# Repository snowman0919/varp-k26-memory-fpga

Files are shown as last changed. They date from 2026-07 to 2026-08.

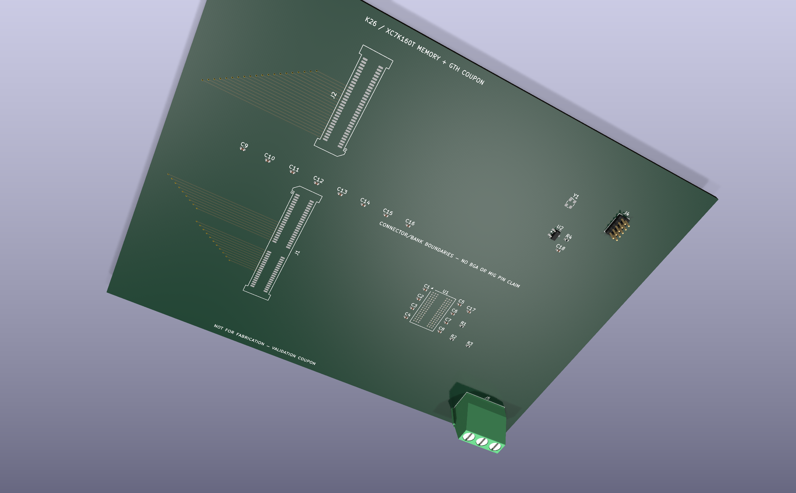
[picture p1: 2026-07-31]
paper/final/figures/paper_f07_kicad_coupon_render.png

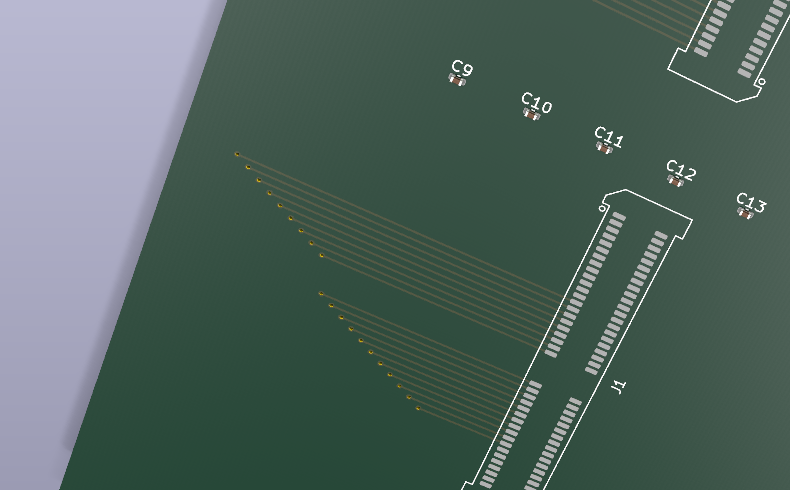
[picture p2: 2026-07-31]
presentation/final/assets/kicad_routed_crop.png

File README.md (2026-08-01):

# 온디바이스 sLLM을 위한 K26–Memory FPGA 후보 구조

Kria K26이 연산·제어를 맡고 외부 Memory FPGA가 다채널로 가중치를 공급하는
확장형 가속기 구조를 설계하고, 데이터 이동 비용을 포함한 작업 재분배가 언제
유효한지 평가한 연구 저장소다.

K26 연산부와 Memory FPGA 가중치 공급부

## 핵심 결론

- Gemma 3 1B INT8와 문맥 길이 32K의 용량 모델은 2.43 GiB다. 따라서 기본 선택은
  K26 로컬이며 외부 8GB는 더 큰 모델·긴 문맥·로컬 경합을 위한 확장 후보다.
- 실제 그래프의 토큰당 183개 투영을 의존성 있는 802개 TileJob으로 변환했다.
- 합성 편향 부하의 동일 시드 다섯 개 중앙값에서 S3는 S1보다 TileJob p95를
  19.13%, p99를 18.71% 줄였다. 반면 Gemma 기존 산술 배치에서는 p95가 0.28%
  늘어 정책 효과가 초기 배치와 이동 비용에 조건부임을 확인했다.
- 대표 실제 가중치 타일 세 개가 작업 수락→DMA 요청→DDR 응답 경계→논리 링크
  FIFO→MatVec 결과의 폐루프 논리 RTL을 통과했고 INT32 기준과 일치했다.

이 수치는 보드 실측이 아니다. GTH·MIG 물리 타이밍, 전체 보드 전력·가격,
제작 가능한 PCB는 아직 검증하지 않았다.

## 연구 기여

1. K26의 연산·제어와 Memory FPGA의 가중치 공급 역할을 분리한 확장 후보 구조
2. 원격 가중치·활성값·부분합 비용을 서비스 시간에 부과한 동적 작업 배치 평가
3. 실제 모델 형상→분석 모델→폐루프 논리 RTL→KiCad 라우팅 쿠폰의 재현 흐름

## 빠른 시작

필수 도구는 Python 3.11+, Java 21, sbt, Verilator, KiCad CLI, Pandoc,
Chromium, Poppler, ffmpeg, Manim과 한글 글꼴이다.

```bash
make setup
make test
make rtl-test
make paper-experiments
make research-freeze
make paper
make presentation
make reproduce
```

허가된 원본 Gemma 3 1B ONNX가 있을 때만 다음 명령으로 trace를 재생성한다.
모델 가중치는 저장소와 release에 포함하지 않는다.

```bash
GEMMA3_1B_ONNX_DIR=/authorized/path make model-trace
```

## 주요 산출물

- [제출 논문](paper/final/submission_manuscript.pdf)
- [기술보고서](paper/technical_report/technical_report.pdf)
- [16장 발표자료](presentation/final/presentation.pptx)
- [발표 PDF](presentation/final/presentation.pdf)
- [발표자 노트](presentation/final/speaker_notes.md)
- [슬라이드별 출처 인덱스](presentation/final/slide_source_index.md)
- [발표 contact sheet](presentation/final/slide_contact_sheet.png)
- [연구 동결 기록](research/v11_research_freeze.md)
- [스터디팩과 Q&A](study/README.md)
- [코드·자료 공개 안내](paper/final/code_and_data_availability.md)
- [학술대회 패키지 통합 인덱스](conference_package/INDEX.md)

## 저장소 구조

| 경로 | 내용 |
|---|---|
| `src/`, `tests/` | 의존성 인식 분석 모델과 검증 |
| `hw/` | SpinalHDL/Verilator RTL과 폐루프 논리 가상 시제품 |
| `experiments/`, `results/`, `evidence/` | Gemma trace, 합성 실험, 결과 CSV |
| `hardware/kicad/` | 일반 경계 라우팅 쿠폰, **NOT FOR FABRICATION** |
| `paper/`, `presentation/`, `study/` | 논문·발표·방어 자료 |

## 재현과 주장 범위

`make research-freeze`는 동일 시드 비교, 원격 복사 비용 부과, Gemma 단계·토큰
의존성, 실제 타일 RTL trace, K26 로컬 기준선과 KiCad 범위를 검사한다. 자세한
논리/물리 경계는 [architecture.md](docs/architecture.md)를 따른다.

## 소스 아카이브

GitHub의 자동 **Download ZIP**은 저장소 tree를 그대로 받는 편의 경로다. 재현
기준은 `v11-conference-final` release에 첨부하는 공식
`VARP_K26_Source.zip`이며, 이 파일은 `source_manifest`와 checksum을 함께
포함한다. 두 경로 모두 모델 가중치는 포함하지 않는다.

## 인용과 라이선스

[CITATION.cff](CITATION.cff)의 최윤혁(한국디지털미디어고등학교,
[ORCID 0009-0006-3537-0249](https://orcid.org/0009-0006-3537-0249)) 정보를 사용한다.
소스 사용 조건은 [LICENSE](LICENSE)를 따른다.

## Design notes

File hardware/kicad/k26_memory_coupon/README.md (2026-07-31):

# K26 memory/interface validation coupon

> **NOT FOR FABRICATION — proposal_only**

This electrically connected KiCad 9 coupon accounts for one DDR3L x16
representative channel slice, a four-lane full-duplex K26 PL-GTH link bundle,
two K26 GTH reference-clock inputs, reset/config/JTAG, and a decoupling subset.

The XC7K160T and K26 are connector/bank boundaries. No XC7K160T FFG676 ball,
MIG placement, production stackup, impedance, or timing claim is made.

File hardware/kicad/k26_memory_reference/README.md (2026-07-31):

# K26 / XC7K160T hierarchical conditional reference

> **NOT FOR FABRICATION — proposal_only**

This hierarchy records the Phase-A architectural boundaries: K26 SOM PL-GTH,
XC7K160T-2FFG676I package resources, four independent DDR3L x16 channels,
four full-duplex serial lanes, clock/reset/config, power, and JTAG.

It is intentionally not a complete electrical design. Exact FPGA balls,
MIG-generated placement, SI/PI, power sequencing and production DDR3L MPNs
remain unresolved gates.

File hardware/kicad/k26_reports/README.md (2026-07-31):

# K26 KiCad validation reports

> **NOT FOR FABRICATION — proposal_only**

Generated ERC/DRC, parity, BOM, netlist, and scope reports live here.

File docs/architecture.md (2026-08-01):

# K26–Memory FPGA 가상 시제품 구조와 구현 범위

## 닫힌 논리 데이터 경로

`ClosedLoopVirtualPrototypeTop`은 다음 경로를 하나의 backpressure-aware RTL
흐름으로 연결한다.

```text
MatVecFetchCommand
  → DMA 요청 FIFO
  → 4채널 메모리 명령 스케줄러
  → DDR 응답 경계(MemoryWeightResponse)
  → 작업 지역성에 따른 4개 논리 링크 FIFO
  → 작업 ID 기반 activation/weight 결합
  → 다중 큐 스케줄러
  → ComputeClusterArray
  → signed-INT8 MatVec 결과
```

입력 명령에는 작업 정보와 activation만 들어 있다. 가중치는 DDR 응답 경계에서
별도로 들어와 논리 링크 FIFO를 통과해야만 MatVec 명령으로 조립된다. 따라서
가중치 응답 없이 연산이 시작되지 않는다. pending table은 job ID를 기준으로
응답을 정확히 한 번만 수락하며, FIFO와 연산부의 역압을 상위 단계로 전달한다.

`ClosedLoopVirtualPrototypeTopSpec`은 실제 Gemma 3 1B 파일에서 제한적으로 추출한
세 개의 16×4 INT8 가중치 타일을 이 경로로 보낸다. DMA 명령, DDR 응답, MatVec
결과 cycle을 기록하고 software INT32 기준값과 일치하는지 검사한다.

## 물리 구현과 구분해야 하는 경계

현재 링크 FIFO는 넓은 논리 응답을 전달한다. 다음 항목은 아직 구현하지 않았다.

- GT serializer/deserializer와 lane bonding
- K26–Memory FPGA 사이의 실제 GTH wrapper
- 양쪽 clock domain crossing과 reset synchronization
- packet fragmentation, CRC 재전송, credit 반환
- MIG가 생성한 DDR3L PHY와 calibration
- Vivado 배치배선, timing closure, 실효 대역폭과 보드 전력 측정

따라서 현재 결과는 닫힌 **논리 RTL 가상 시제품**의 정확성과 역압을 검증한다.
물리 GTH/DDR 성능이나 실제 보드 대역폭을 검증하지 않는다.

## 기존 통합 셸

`K26WorkStealingTop`은 scheduler→연산 입력 저장소→MatVec 구간과 독립적인
메모리 명령·링크 라우팅 경로를 제공한다. 이전 논문은 이 셸의 세 경로를 하나의
전체 데이터 경로처럼 보이게 설명했다. 최종 논문에서는 직접 연결된
`ClosedLoopVirtualPrototypeTop`을 논리 구조 증거로 사용하고, 기존 셸은 모듈별
단위 시험과 설계 공간 실험용으로만 남긴다.

## KiCad 자료의 정확한 위치

현재 KiCad의 `k26_memory_coupon`은 전체 Memory FPGA 보드가 아니다. 범용 Samtec
커넥터 두 개가 K26 GTH 경계와 FPGA bank 경계를 대신하고, DDR3L x16 한 슬라이스와
대표 차동 링크 배선만 포함한다. 실제 K26 SOM 커넥터 핀, XC7K160T BGA pinout,
4채널 MIG, 전원 트리와 제작 검증은 포함하지 않는다. 따라서 이 자료는
**인터페이스 라우팅 검증 쿠폰**이며 `NOT FOR FABRICATION`이다.

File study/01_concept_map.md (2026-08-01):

# 개념 지도

```text
Gemma 3 1B ONNX
  └─ 7,837 nodes → 183 projections/token
      └─ full-K, N≤1024 → 802 TileJobs/token
          ├─ qkv→o→gate/up→down→next layer
          ├─ 초기 배치 4종
          └─ S1/S2/S3 비용 포함 분석

K26: scheduler + 4 compute clusters + MatVec
  ↕ 4 logical links
Memory FPGA 후보: 4 DDR3L channels + weight service

실제 타일 → DMA 요청 → DDR 응답 경계 → 논리 FIFO → MatVec → INT32 결과
GTH/MIG/CDC/packet/board timing → 후속 물리 구현

KiCad generic boundary coupon → NOT FOR FABRICATION
```

중심 판단은 “외부가 항상 빠른가”가 아니라 “어떤 확장 조건에서 로컬 기준선을
넘는가”이다.

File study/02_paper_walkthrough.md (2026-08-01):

# 논문 순회

## I–III. 문제와 질문 전환

처음에는 외부 8GB를 용량 해법으로 보았지만 1B 용량 모델이 2.43 GiB임을 확인했다.
따라서 질문을 가중치 공급 분리와 다중 클러스터 활용으로 바꿨다.

## IV–VI. 구조와 정책

K26은 계산 소유권, Memory FPGA는 데이터 공급 친화도를 맡는다. S1은 정적 로컬
큐, S2는 가장 오래된 작업 이동, S3는 대기 이득에서 가중치·활성값·부분합 이동
비용을 뺀다. 추가 전송은 실제 분석 서비스 시간에 들어간다.

## V·VII. 실제 모델과 구현

토큰당 183개 투영을 의존성 있는 802개 출력 TileJob으로 나눈다. 대표 실제 타일
3개는 폐루프 논리 RTL을 통과했다. 물리 GTH·MIG 경로와 보드 타이밍은 포함하지
않는다.

## VIII. 결과와 결정

합성 편향 부하에서는 p95/p99가 줄지만 균형·채널 집중 조건에서는 이득이 없다.
Gemma 형상에서는 초기 배치에 따라 악화와 개선이 모두 나타난다. K26 로컬 기준선이
시험한 외부 후보보다 짧아 외부 구조의 채택은 보류한다.

## IX–XI. 물리 범위와 결론

KiCad는 전체 보드가 아니라 일반 경계 라우팅 쿠폰이다. 기여는 역할 분리, 비용 포함
배치, 모델→RTL→KiCad 재현 흐름이다.

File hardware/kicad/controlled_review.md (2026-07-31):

# VARP K26 memory coupon — controlled-evidence review

> **NOT FOR FABRICATION — `proposal_only`**

**Review date:** 2026-07-31

**Native tool:** KiCad CLI 9.0.9

**Automated analyzers:** KiCad skill schema 1.4.0 plus EMC analyzer
**Reviewed source:** `k26_memory_coupon.kicad_sch`, `k26_memory_coupon.kicad_pcb`,
the hierarchical `k26_memory_reference` schematic, and the checked-in Gerber
set.

## Verdict

**PASS for an internally consistent, electrically connected research coupon
and paper illustration; FAIL for fabrication readiness, pin-level
implementation, signal/power integrity, thermal, or compliance claims.**

KiCad's native gates pass: coupon ERC 0/0, hierarchical reference ERC 0/0,
coupon DRC 0 violations, schematic parity 0 issues, and native unconnected-pad
count 0. Those results apply only to the deliberately reduced connector/bank
boundary model and its relaxed proposal rules. The independent analyzers find
55 unrouted logical nets, nine return-path crossings, no ground stitching,
insufficient test access, manufacturing-rule risks, and incomplete component
provenance. These findings are fabrication blockers, not paper blockers.

## Scope and evidence classes

| Class | What is supported |
|---|---|
| Raw-file checked | 29 schematic components, 116 named schematic nets, 29 PCB footprints, 65 track segments, 50 vias, one zone, 140 × 110 mm outline, four copper layers declared |
| Native-tool checked | ERC, DRC, schematic/PCB parity, exports, and the routed-subset connectivity under the checked-in proposal rules |
| Analyzer-derived | routing completeness, geometry/DFM heuristics, cross-domain return-path findings, Gerber completeness, EMC risk heuristics |
| Source-supported feasibility | K26 connector lane availability, XC7K160T package/bank capacity, and the conditional multi-controller architecture cited in `k26_native_validation.md` |
| Inference only | actual BGA/MIG placement, production stackup, impedance, insertion loss, skew, jitter, eye margin, PDN, junction temperature, and EMC pass/fail |
| Datasheet/extraction verified | none in this analyzer run; local datasheet extraction coverage is 0% |

No analyzer score is promoted to a hardware-performance or regulatory result.

## Native gates

| Gate | Result | Artifact |
|---|---:|---|
| Coupon ERC | 0 errors, 0 warnings | `k26_reports/coupon_erc.json` |
| Hierarchical reference ERC | 0 errors, 0 warnings | `k26_reports/reference_erc.json` |
| Coupon PCB DRC | 0 violations | `k26_reports/coupon_drc.json` |
| Schematic parity | 0 issues | `k26_reports/coupon_drc.json` |
| Native unconnected pads | 0 | `k26_reports/coupon_drc.rpt` |

`scripts/verify_k26_kicad.py` reran all of these gates and returned:
`KiCad native gate: PASS (coupon ERC=0, reference ERC=0,
coupon DRC/parity=0)`.

The native DRC result does not contradict the analyzer's 55 unrouted nets:
the proposal coupon intentionally ignores incomplete ratsnest connectivity
outside the routed subset, and `via_dangling` is disabled for its unfilled
internal ground-zone intent. Clearance, shorts, width, drill, outline, and
parity rules remain active.

## Schematic and component review

The coupon contains two IC/boundary devices, four connectors, one oscillator,
18 capacitors, and four resistors. It represents one DDR3L x16 slice, four
full-duplex K26 PL-GTH lanes, two GTH reference-clock pairs, reset/config/JTAG,
and a decoupling subset.

The schematic analyzer reports 16 findings: one error, one warning, and 14
informational items. The error is a sourcing-readiness gate: only 1 of 10
unique parts has an MPN. The warning is the absence of a datasheet extraction
directory. Consequently:

- no final DDR3L density/rank/organization is asserted;
- no connector or XC7K160T ball mapping is asserted;
- no oscillator, passive tolerance, voltage rating, or package claim is
  asserted;
- symbol pin names and net labels are treated as model consistency only.

## PCB, routing, and return paths

The PCB analyzer found 29 footprints, 116 nets, 65 track segments, 50 vias,
one zone, and 1,991.51 mm of track. It reports `routing_complete=false` and 55
unrouted nets. The explicitly routed evidence is the 20 GTH/refclock
single-ended nets. DDR, rail, reset, and JTAG completeness is not established.

Fabrication blockers reported by geometry analysis:

- 0.10 mm annular rings are below the analyzer's 0.125 mm standard-process
  threshold;
- ten untented via-in-pad cases require an explicit fabrication process;
- 27 SMD parts have no front-side fiducials;
- test-point coverage is 0/116 nets;
- 55 nets are unrouted.

Cross-analysis reports nine high-speed nets crossing a modeled GND-plane gap:
DDR CK P/N, DQ0, LDQS P/N, and both GTH reference-clock P/N pairs. It also
reports no ground stitching vias. These must be fixed or disproved with a
filled-zone, stackup-aware return-path review before fabrication.

## Gerber and manufacturing review

The Gerber analyzer found all expected copper, mask, paste, silkscreen, edge,
and drill outputs: 26 Gerber files, one mixed drill file, 63 holes, 1,139
flashes, and 5,533 draws. The job file gives a 140.1 × 110.1 mm board extent.

Two alignment warnings arise because the analyzer compares the extents of
sparse copper/mask artwork with the full Edge.Cuts rectangle. Empty paste or
silkscreen on some layers naturally has a smaller extent, so this is not by
itself evidence of a shifted plot. It remains a pre-fab checkpoint: inspect
the Gerbers in an independent CAM viewer and confirm origin, outline, drill,
mask, and every copper layer.

## EMC and thermal review

The CISPR 32 Class B-oriented risk analyzer produced 26 findings and a
heuristic score of 67/100. This is **not** a compliance prediction. The main
actionable findings are:

- ten decoupling capacitors are far from their nearest modeled via;
- J5 lacks modeled EMC filtering;
- four GTH reference-clock nets are on an outer layer and near J2;
- the return-path dataset was not recognized by the EMC consumer even though
  the separate cross-analyzer found nine explicit plane-gap crossings.

The thermal analyzer ran but assessed zero components. It skipped scoring
because there are no complete MPNs, extracted thermal parameters, or
quantifiable dissipation values. No temperature or cooling claim is supported.

## Power, interfaces, and testability

The source names +1V35, +3V3, and GND rails and includes a decoupling subset,
but it does not close the full K26/XC7K160T/DDR power tree, sequencing, current,
VTT/VREF tolerance, or PDN impedance. Four GTH lanes and two reference-clock
pairs are geometrically represented only. Production work requires exact
connector/package pins, Vivado MIG placement, GTX quad/refclock assignment,
fabricator stackup, field-solved impedance, loss/jitter budgeting, and SI/PI
simulation.

JTAG and reset boundaries are present, but 0% test-point coverage means the
coupon is not a manufacturing-test design. Add rail, reset, clock, link, and
DDR observation points plus a bring-up and boundary-scan plan.

## False positives and reviewer overrides

| Analyzer output | Disposition |
|---|---|
| Native DRC says zero unconnected pads | Valid only under proposal rules; overridden for completeness by the analyzer's 55-net routing inventory |
| Gerber width/height alignment warnings | Likely sparse-layer extent behavior; retain mandatory CAM overlay check |
| EMC says return-path data unavailable | Tool-consumer limitation; separate cross-analysis provides nine deterministic RP-002 findings |
| Numerical EMC score | Checklist prioritization only; never a pass/fail or lab substitute |
| Thermal score skipped | Correct result, not a clean thermal bill of health |
| One part with MPN | Insufficient to support any board-wide part, pin, lifecycle, or sourcing claim |

## Analyses performed and skipped

Performed:

- raw source and checked-in native-report inspection;
- KiCad 9.0.9 coupon and hierarchical ERC;
- KiCad 9.0.9 coupon PCB DRC and schematic parity;
- schematic analysis;
- full PCB and proximity analysis;
- schematic/PCB cross-analysis;
- Gerber/drill analysis;
- CISPR 32 Class B-oriented EMC risk analysis;
- thermal analyzer invocation;
- deterministic project verification script.

Skipped or non-applicable:

- datasheet deep review and pin-level extraction — no datasheet cache and
  incomplete MPN coverage;
- lifecycle/distributor audit — part identity coverage is insufficient and
  no unfounded sourcing lookup was substituted;
- SPICE/PDN simulation — `ngspice` is unavailable and no closed production
  circuit model exists;
- full-wave SI/EMI and lab compliance — no production stackup, enclosure,
  cable model, or calibrated hardware;
- Vivado MIG placement/timing — exact DDR organization and BGA placement are
  unresolved;
- fabrication release — explicitly prohibited by scope.

## Delta from the prior native review

The earlier `k26_native_validation.md` established the conditional native
gate and source counts. This review adds a fresh independent analyzer run,
full/proximity PCB inspection, Gerber analysis, cross-domain return-path
checks, EMC risk analysis, thermal invocation, explicit false-positive
disposition, and a performed/skipped ledger. No source schematic or PCB edit
was made, so the native outcome is unchanged. The additional analysis makes
the incompleteness concrete: 55 unrouted nets, nine return-path crossings,
no stitching, 0% test access, incomplete MPN/datasheet coverage, and no
thermal basis.

## Required next hardware phase

1. Select production DDR3L, oscillator, connectors, passives, regulators, and
   protection parts; archive manufacturer documents and exact MPNs.
2. Generate the four-controller topology in Vivado MIG for
   `XC7K160T-2FFG676I`; assign legal BGA, byte-group, bank, GTX, and refclock
   pins.
3. Close the fabricator stackup and impedance rules, fill reference planes,
   reroute all nets, add stitching, fiducials, test points, and explicit
   via-in-pad/tenting fabrication notes.
4. Complete PDN, SI, thermal, EMC, DFM, and manufacturing-test analyses.
5. Repeat native ERC/DRC/parity, analyzer suite, independent CAM review, and
   physical bring-up before any feasibility or performance statement.

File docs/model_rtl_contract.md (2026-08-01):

# Analytical model versus RTL contract

The Python event model is a policy exploration tool; it is not a behavioral or
cycle-accurate reference for `TileScheduler`.

| Topic | Python analytical model | Current RTL |
|---|---|---|
| Home queue | explicit `TileJob.home_cluster` | `jobId % clusterCount` |
| S2/S3 victim choice | searches every eligible job in victim queues | inspects victim queue heads only, preserving per-queue FCFS |
| Locality cost | byte/service-dependent floating-point penalties | fixed integer channel, bundle, activation, and reduction penalties |
| Dispatch width | multiple idle clusters may dispatch at one event time | at most one job per clock edge |
| Compute rate | default abstract 64 MAC/cycle | 16×4 demo performs 64 MACs in 65 request-to-done cycles |
| Memory/link | analytical resource service and overlap assumptions | `K26WorkStealingTop`: independent command/routing planes. `ClosedLoopVirtualPrototypeTop`: DMA request FIFO→multichannel command scheduler→testbench response boundary→logical link FIFO→job-ID join→MatVec result |

Consequences:

- Python S0–S3 rankings are candidate-policy evidence only.
- Python cycle counts are not predictions of RTL latency or throughput.
- Exact RTL equivalence requires a separate cycle-stepped reference model or a
  common trace contract; neither is claimed here.
- The current RTL tests establish bounded functionality and exact-once
  ownership, not analytical-result reproduction.
- The closed-loop actual-tile fixture uses one cluster, one channel, and S0.
  S3 ownership transfer is covered by a separate synthetic scheduler fixture;
  the two tests do not constitute one physical Work-Stealing execution.
- `ClosedLoopVirtualPrototypeTop` closes a logical payload path. Its response is
  injected at a testbench boundary, so GTH serialization, packet framing,
  credit/CDC, MIG/DDR timing, and board payload bandwidth remain open gates.

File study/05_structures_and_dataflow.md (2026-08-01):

# 구조와 데이터 흐름

## 역할 분리

K26은 TileJob 수락, 대기열 정책, DMA 명령, 네 연산 클러스터와 MatVec 결과를
관리한다. Memory FPGA 후보는 네 DDR3L 채널의 가중치 공급을 맡는다.

## 닫힌 논리 경로

`작업 수락 → DMA 요청 FIFO → 채널 스케줄러 → DDR 응답 경계 → 논리 링크 FIFO → job ID 결합 → MatVec → 결과`

대표 Gemma 타일 세 개가 이 경로를 통과했다. 응답이 없으면 MatVec 명령을 만들 수
없고 같은 응답은 한 번만 수락된다.

## 열린 물리 경로

GTH 직렬화, 레인 결합, CDC, 패킷, CRC, 크레딧, MIG/PHY, 실제 K26 커넥터와 보드
타이밍은 후속 범위다. 논리 폐루프를 물리 링크 완료로 말하면 안 된다.

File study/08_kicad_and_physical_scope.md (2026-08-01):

# KiCad와 물리 범위

현재 KiCad 자료는 K26 모듈과 Memory FPGA가 실장된 전체 보드가 아니다. J1/J2
일반 경계 커넥터, MLCC, 단일 DDR3L slice와 일부 GTH·기준 클록 배선을 둔 참조
라우팅 쿠폰이다.

footprint 29개, 라우팅된 GTH/refclk 관련 net 20개, 선언한 제한 범위 ERC/DRC 0을
확인했다. 이 값은 쿠폰 subset에만 적용된다.

정확한 MPN, K26 connector pinout, FPGA package·transceiver quad, 네 MIG bank,
전원 트리, 전체 배선, SI/PI/PDN/thermal/EMC와 제조 검사가 남아 있다. 항상
**NOT FOR FABRICATION**으로 표시한다.

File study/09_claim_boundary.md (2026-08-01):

# 주장 범위

## 직접 또는 RTL로 확인

- Gemma ONNX 노드·투영 형상과 대표 실제 가중치 타일
- 대표 타일 3개의 폐루프 논리 RTL 순서와 INT32 일치
- KiCad 원본 객체와 제한된 쿠폰 검사

## 분석 모델

- 합성 부하 S1/S2/S3의 TileJob p95/p99·완료시간·이동량
- Gemma 형상의 초기 배치 민감도
- K26 로컬/외부 메모리 대역폭 민감도와 2.43 GiB 용량 모델

## 주장하지 않음

- 보드 실측 성능·전력·물리 링크 대역폭
- 기능적 Gemma 생성 또는 전체 모델 FPGA 실행
- 전체 가속기 가격·저전력 달성
- 제작 가능한 PCB·SI/PI/thermal closure

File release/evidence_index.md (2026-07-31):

# VARP K26 evidence index

This index separates direct, simulated, analytical, hybrid, and blocked claims. Hashes bind every entry to the release snapshot.

| ID | Evidence type | Artifact | Supported | Forbidden |
|---|---|---|---|---|
| E01 | graph-derived + analytical | `experiments/gemma3_1b/trace_manifest.json` | Hashed ONNX graph/token ledger and replay provenance | End-to-end model execution or hardware latency |
| E02 | graph-derived | `experiments/gemma3_1b/projection_trace.csv` | 183 dense projection nodes and source tensor geometry | Measured execution time |
| E03 | RTL-simulated bounded extract | `evidence/model/gemma3_1b_rtl_tile_parity.csv` | Three actual-weight 16x4 INT8 tiles match software references | Full-model RTL inference or global quantization accuracy |
| E04 | RTL-simulated | `evidence/waveforms/work_stealing_events.csv` | Scheduler-to-real-MatVec event timeline for the bounded case | System throughput or board timing |
| E05 | analytical model | `results/experiments/scheduler_controlled.csv` | Controlled six-policy comparisons across five seeds and three runs | RTL cycle performance or physical speedup |
| E06 | hybrid modeled | `results/model_level/gemma3_1b_hybrid.csv` | Projection-model plus disclosed host fallback arithmetic | Measured end-to-end accelerator latency |
| E07 | estimated energy | `results/power_cost/energy_category_model.csv` | Compute/link/DRAM energy sensitivity ranges | Vivado or board power |
| E08 | current price snapshot + arithmetic | `cost/cost_sensitivity.csv` | Memory-package/die cost sensitivity only | Full FPGA/board/system price |
| E09 | native KiCad | `hardware/kicad/k26_reports/k26_scope_manifest.json` | Internal proposal-coupon ERC/DRC/parity status | Fabrication readiness, SI/PI, or compliance |
| E10 | controlled review | `hardware/kicad/controlled_review.md` | Native and analyzer findings with explicit overrides | Production pinout, thermal closure, or EMC pass |
| E11 | toolchain contract | `docs/toolchain/COMPATIBILITY_MATRIX.md` | Required tools and explicit missing-tool consequences | Host-specific tool availability or successful design execution |
| E12 | asset QA | `build/publication_assets/validation_report.json` | Figure/flow/presentation asset validation | Scientific validation of the underlying models |

## Claim-to-evidence crosswalk

| Claim | Figure | Table / result | Generator / verifier | Primary source |
|---|---|---|---|---|
| C01: Architecture planes and open payload boundary | `paper/final/figures/paper_f01_evidence_path.svg` | `paper/final/submission_manuscript.md#iv-k26memory-fpga-시스템` | `hw/src/main/scala/varp/k26/K26WorkStealingTop.scala` | `docs/architecture.md` |
| C02: 7,837 graph nodes and 183 projections/token | `paper/final/figures/paper_f02_onnx_runtime_graph.svg` | `experiments/gemma3_1b/projection_trace.csv` | `experiments/gemma3_1b/generate_trace.py` | `experiments/gemma3_1b/trace_manifest.json` |
| C03: S0/S1/S2/S3 policy and evidence boundary | `paper/final/figures/paper_f03_policy_boundary.svg` | `results/experiments/scheduler_controlled.csv` | `scripts/run_k26_experiments.py` | `src/varp/k26_scheduler_model.py` |
| C04: Three bounded steals preserve MatVec identity | `paper/final/figures/paper_f04_waveform_identity.svg` | `evidence/waveforms/work_stealing_events.csv` | `scripts/build_rtl_evidence.py` | `hw/src/test/scala/varp/WorkStealingEvidenceSpec.scala` |
| C05: S3 lowers skew/mixed p95 versus S1 | `paper/final/figures/paper_f05_tail_latency.svg` | `build/publication_assets/tables/scheduler_core_metrics.csv` | `publication_tools/generate_publication_and_presentation.py` | `results/experiments/scheduler_controlled.csv` |
| C06: S3 p95/completion/remote-byte trade-off versus S2 | `paper/final/figures/paper_f06_tradeoff.svg` | `build/publication_assets/tables/scheduler_core_metrics.csv` | `publication_tools/generate_publication_and_presentation.py` | `results/experiments/scheduler_controlled.csv` |
| C07: Energy and cost are sensitivity estimates | `build/publication_assets/figures/F06/figure.svg` | `results/power_cost/energy_category_model.csv` | `scripts/build_power_cost_evidence.py` | `cost/memory_die_price_snapshot.csv` |
| C08: Native KiCad coupon is not fabrication-ready | `paper/final/figures/paper_f07_kicad_coupon_render.png` | `hardware/kicad/k26_reports/k26_scope_manifest.json` | `scripts/verify_k26_kicad.py` | `hardware/kicad/controlled_review.md` |
| C09: Blocked physical performance and power claims | `build/publication_assets/figures/F03/figure.svg` | `build/publication_assets/tables/blocked_evidence.csv` | `scripts/audit_phase_a_toolchain.py` | `docs/evidence.md` |

## Global blockers

- No Vivado implementation, place-and-route, timing, or report_power.
- No production MIG pin placement or SI/PI closure.
- No board power, throughput, thermal, or EMC compliance measurement.
- No model weights are redistributed.
- No HWP is emitted without an actual HWP tool and template.

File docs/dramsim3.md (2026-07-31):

# DRAMsim3 status

This public repository does not include a runnable DRAMsim3 adapter or a
cycle-coupled scheduler/DRAMsim3 flow. It preserves:

- four DDR3L configuration snapshots under `configs/dram/`;
- the imported four-channel statistics snapshot at
  `results/runs/dramsim3-snapshot/dramsim_stats_ch4.json`;
- a derived, explicitly bounded energy breakdown under `results/power_cost/`.

`make reproduce` does not claim to regenerate the imported DRAMsim3 snapshot.
The old experimental adapter is available only in the preserved
`archive/v10-full-evidence` history. `DRAMSIM3_ROOT` is probed for disclosure by
`make doctor`, but no sibling checkout is assumed and no DRAMsim3 performance
claim is promoted from mere tool availability.

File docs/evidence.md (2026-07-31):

# Evidence classes

| Class | Examples | Supports | Does not support |
|---|---|---|---|
| Direct source | model hashes, native KiCad files, controlled ledgers | provenance and declared structure | execution performance |
| RTL simulated | scheduler/MatVec tests, event CSV, tile parity | bounded functional behavior | board timing or throughput |
| Analytical/hybrid | scheduler tables, capacity, energy/cost arithmetic | comparisons under stated assumptions | measured acceleration or power |
| Imported snapshot | DRAMsim3 statistics | preserved prior run only | public end-to-end regeneration |
| Blocked | Vivado, MIG, SI/PI, thermal, EMC | future acceptance gates | any positive physical claim |

Every public claim must keep its qualifier. A KiCad ERC/limited-DRC pass is not
fabrication readiness. An available executable is not evidence that the design
ran through it. Model weights are never part of Git or release archives.

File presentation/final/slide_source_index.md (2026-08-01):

# Slide Source Index

모든 경로는 저장소 root 기준이다. 화면에서 생략한 시드·분석 모델 조건은 speaker notes와 연구 CSV에 남긴다.

| Slide | 원본 CSV | 사용 Figure / 자료 | 생성·검증 스크립트 | 허용 해석 | 금지 해석 |
|---:|---|---|---|---|---|
| 1 | 없음 | cover_background.png | image_gen; build_v11_deck.py | 후보 구조의 장식적 배경 | 실제 회로나 구현 완료 상태 |
| 2 | 없음 | 편집 가능한 목차 | build_v11_deck.py | 발표 질문과 진행 순서 | 연구 결과 |
| 3 | k26_local_external_sensitivity.csv | 편집 가능한 질문 전환 | run_k26_local_baseline.py | 2.43 GiB 용량 모델과 K26 로컬 우선 판단 | K26 기능 실행·보드 측정 |
| 4 | 없음 | 편집 가능한 K26↔Memory FPGA 구조 | build_v11_deck.py; ClosedLoopVirtualPrototypeTop.scala | 4클러스터·4채널 후보와 논리/물리 경계 | GTH·MIG 물리 완료 |
| 5 | gemma3_1b_closed_loop_trace.csv | tile_dataflow.mp4/frame; 세 타일 타임라인 | manim_scenes.py; ClosedLoopVirtualPrototypeTopSpec.scala | 1클러스터·S0 대표 타일 3개 논리 폐루프 | S3 결합 실행·전체 Gemma·보드 타이밍 |
| 6 | 없음 | 편집 가능한 정적 큐 개념 | build_v11_deck.py | 정적 소유권의 지역성과 불균형 | 수치 성능 |
| 7 | 없음 | work_stealing_sequence.mp4/frame | manim_scenes.py; k26_scheduler_model.py | 대기 감소 이득과 이동 비용을 비교하는 정책 | 최적성·보드 타이밍 |
| 8 | projection_trace.csv; gemma3_1b_dependency_manifest.json | 편집 가능한 7,837→183→802 흐름 | gemma_dependency_model.py | ONNX 형상·모델 의존성·초기 배치 | 기능적 텍스트 생성·실제 컴파일러 배치 |
| 9 | s1_s3_timeline_events.csv | scheduler_timeline.mp4/frame | generate_conference_figures.py; manim_scenes.py | 동일 합성 작업·시드의 대기·원격 준비·연산 구간 | Gemma 사건·물리 사이클 |
| 10 | paired_policy_effects.csv; gemma3_1b_policy_effects.csv | 편집 가능한 결과 비교 | build_v11_research_summary.py; build_v11_deck.py | 합성 paired median과 Gemma 배치 민감도 | 사용자 요청 latency·보편적 우월성 |
| 11 | paired_policy_effects.csv | bottleneck_migration.mp4/frame | manim_scenes.py | S1/S2 비교 기준을 분리한 병목 이동 | 세 수치가 같은 비교라는 해석 |
| 12 | k26_local_external_sensitivity.csv | 편집 가능한 로컬/외부 비교 | run_k26_local_baseline.py; build_v11_deck.py | 시험한 대역폭 민감도에서 K26 로컬 우선 | 보드 실측·모든 미래 조건의 우월성 |
| 13 | 없음 | 실제 KiCad 렌더와 확대 이미지 | verify_k26_kicad.py; kicad-cli; build_v11_deck.py | 참조 쿠폰의 객체·부분 배선·제한 검사 범위 | 제작 가능 보드·전체 DRC 0 |
| 14 | 없음 | 편집 가능한 한계→탐구 관문 | build_v11_deck.py | 현재 미구현 경계와 후속 검증 순서 | 실측 완료·전체 보드 완료 |
| 15 | 없음 | 편집 가능한 3줄 결론·QR | build_v11_deck.py | 후보 구조·효과 조건·현재 채택 판단의 요약 | 보편적 우월성·실측 완료 |
| 16 | 없음 | 편집 가능한 Q&A 마무리 화면 | build_v11_deck.py; study/10_qna_bank.md; study/15_final_round_scoring_strategy.md | 구두 질의응답 시작 | 준비된 질문·답변이 화면에 있다는 해석 |

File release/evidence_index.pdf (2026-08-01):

# VARP K26 evidence index

Claim-separated manifest. Hashes bind entries to the release snapshot.

## E01 — graph-derived + analytical

experiments/gemma3_1b/trace_manifest.json
Supports: Hashed ONNX graph/token ledger and replay provenance

Does not support: End-to-end model execution or hardware latency

SHA-256: 3a274321062648bd08298617ca7681bd04bf1d39467257b5aebae09b7cdfb6d2 · 3340 bytes

## E02 — graph-derived

experiments/gemma3_1b/projection_trace.csv
Supports: 183 dense projection nodes and source tensor geometry

Does not support: Measured execution time

SHA-256: d0948d20ce56daf43edc2ff61a405797df9980bbe86dfff91ba9d2f1cfb100c4 · 79394 bytes

## E03 — RTL-simulated bounded extract

evidence/model/gemma3_1b_rtl_tile_parity.csv
Supports: Three actual-weight 16x4 INT8 tiles match software references

Does not support: Full-model RTL inference or global quantization accuracy

SHA-256: 2190f50a7a260b27514da4e842740e08236601920819f25aed85c76c5efa9861 · 589 bytes

## E04 — RTL-simulated

evidence/waveforms/work_stealing_events.csv
Supports: Scheduler-to-real-MatVec event timeline for the bounded case

Does not support: System throughput or board timing

SHA-256: 9ce1ec5dd0c485029f495151df034d908da1a85fff82d6af47f6507a26b6fe8f · 15791 bytes

## E05 — analytical model

results/experiments/scheduler_controlled.csv
Supports: Controlled six-policy comparisons across five seeds and three runs

Does not support: RTL cycle performance or physical speedup

SHA-256: ab30ebadd8c801c166f4fd510cdb68706a102a9747d3bd640674cbe2636db848 · 449498 bytes

## E06 — hybrid modeled

results/model_level/gemma3_1b_hybrid.csv
Supports: Projection-model plus disclosed host fallback arithmetic

Does not support: Measured end-to-end accelerator latency

SHA-256: 527b5ecb7e8d4381678607b47d22a2df5a6c4445614624fce703c5ea713ed983 · 6163 bytes

## E07 — estimated energy

results/power_cost/energy_category_model.csv
Supports: Compute/link/DRAM energy sensitivity ranges

Does not support: Vivado or board power

SHA-256: 8fe5a7c70dd0c34f313e81872dd337a3cc529d0e5ea328eb7bc211fc4781c492 · 4692 bytes

## E08 — current price snapshot + arithmetic

cost/cost_sensitivity.csv
Supports: Memory-package/die cost sensitivity only

Does not support: Full FPGA/board/system price

SHA-256: 5f2c9f32b96cf023b2d5353355a627bd7d7e829ce274f1568faa96281865c4a1 · 3457 bytes

## E09 — native KiCad

hardware/kicad/k26_reports/k26_scope_manifest.json
Supports: Internal proposal-coupon ERC/DRC/parity status

Does not support: Fabrication readiness, SI/PI, or compliance

SHA-256: 7dc8ebf6d5e63205b31fdf8510b35ca52b20942b1926419bd64aee37c8fd0caf · 1057 bytes

## E10 — controlled review

hardware/kicad/controlled_review.md
Supports: Native and analyzer findings with explicit overrides

Does not support: Production pinout, thermal closure, or EMC pass

SHA-256: 4e497fc5a83e4ce43f63705afcfc7d9a1f3e5e67cd39162345c5fe577f353550 · 10256 bytes

## E11 — toolchain contract

docs/toolchain/COMPATIBILITY_MATRIX.md
Supports: Required tools and explicit missing-tool consequences

Does not support: Host-specific tool availability or successful design execution

SHA-256: 961bee51ff6725adbf2ba68e3d36f841e352d6f54f852fd46c7fed5c8a934689 · 1085 bytes

## E12 — asset QA

build/publication_assets/validation_report.json
Supports: Figure/flow/presentation asset validation

Does not support: Scientific validation of the underlying models

SHA-256: 9bb5ebf57fa2c25a83b336ef0f902dc7efbd2d2ddab8e8f636cf0f81dca7f594 · 672 bytes

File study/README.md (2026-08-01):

# VARP v11 발표·논문 방어 스터디팩

이 자료는 수치를 외우기보다 왜 질문이 바뀌었고, 무엇을 만들었으며, 어떤
조건에서만 유효한지 설명하도록 돕는다.

## 45분 본선 준비 순서

1. 한 장 요약과 개념 지도를 읽는다.
2. 슬라이드 순회의 16개 기억 문장을 소리 내어 말한다.
3. 예상 질문과 답변의 Q1–20과 적대적 질문을 답한다.
4. 모든 수치 앞에 분석 모델/RTL 시뮬레이션/직접 확인 중 하나를 붙인다.
5. 본선 심사 기준 대응표에서 A등급 답변 12개와 타 발표 질문 3개를 소리 내어 연습한다.

## 답변 규칙

- Work Stealing을 주인공으로 만들지 말고 시스템 구조의 조건부 수단으로 설명한다.
- Gemma 1B는 K26 로컬 우선, 외부 8GB는 확장 후보라고 답한다.
- 폐루프 **논리** RTL과 미완성 GTH·MIG **물리** 경로를 구분한다.
- KiCad는 전체 보드가 아니라 참조 라우팅 쿠폰이라고 말한다.
- 질의응답은 결론→근거→경계→다음 검증의 네 문장으로 25초 안에 답한다.
- 전체 세션의 80% 이상 접속하고 다른 참가자 발표에 근거 있는 질문을 준비한다.

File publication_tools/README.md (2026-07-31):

# Paper 10 visual and presentation tools

Run from the repository root:

```bash
python3 publication_tools/generate_publication_and_presentation.py
python3 publication_tools/validate_publication_and_presentation.py
```

Runtime dependencies are Python 3.11+, Pillow, python-pptx, and the system
`pdftoppm`. `ffmpeg` is optional; when installed it creates MP4/GIF animation.

The generator reads committed source CSVs in `data/publication/`, the
controlled scheduler CSV, and bounded native KiCad reports. It writes all
rendered assets to `build/publication_assets/` and `build/presentation/`.
Those generated files are intentionally ignored by Git. The generator does
not invent Gemma, energy, cost, synthesis, or physical-measurement data.

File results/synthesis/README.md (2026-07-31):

# K26 paper-target synthesis gate

- Gate: **blocked**
- Evidence type: `rtl-elaboration`
- Generated top: `K26WorkStealingTop`
- Generated Verilog: `build/k26-rtl/K26WorkStealingTop.v`
- SHA-256: `4d5f94f5d3f206a70d032df7f8a18d83a4b5a0d9d8ba92aa0dc31bef2e67b8ed`
- Lines: 43260
- Conditional reference device: `XC7K160T-2FFG676I`

Vivado is not installed in this environment. Therefore no utilization,
timing-closure, MIG-legality, or physical-link claim is made. Verilator is used
only for functional RTL validation and is not a substitute for AMD synthesis.
The exact machine-readable gate and tool paths are in `synthesis_gate.json`.

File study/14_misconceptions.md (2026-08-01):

# 흔한 오해

| 오해 | 바로잡기 |
|---|---|
| 1B는 외부 8GB가 반드시 필요하다 | 2.43 GiB 용량 모델이므로 K26 로컬이 우선이다 |
| 외부 후보가 로컬보다 빠르다 | 시험한 분석 민감도에서는 로컬 기준선이 더 짧다 |
| Work Stealing이 논문의 주인공이다 | 구조의 남은 불균형을 처리하는 조건부 수단이다 |
| S3는 항상 빠르다 | Gemma 기존 산술 배치에서는 p95와 완료시간이 악화됐다 |
| p95는 사용자 요청 지연이다 | 의존성 해제 뒤 TileJob 완료 분포다 |
| 32토큰은 병렬 decode다 | 단계와 토큰을 직렬화한 분석 반복이다 |
| 실제 타일 3개 일치는 전체 모델 실행이다 | 제한된 폐루프 논리 RTL 정확성이다 |
| 폐루프 RTL은 물리 GTH/MIG 완료다 | 직렬화·CDC·PHY·보드 타이밍은 후속 범위다 |
| KiCad 렌더는 제작 가능한 보드다 | 일반 경계 라우팅 쿠폰이며 NOT FOR FABRICATION이다 |
| 저비용·저전력을 달성했다 | 전체 BOM과 보드 전력이 없어 목표로만 기술한다 |

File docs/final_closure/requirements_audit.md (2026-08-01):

# 통합 목표 요구사항 감사표

기준 문서:

1. `goal-objective.md` — VARP K26–Memory FPGA 최종 학술대회 산출물 목표
2. `VARP_IT_ACADEMIC_CONTEST_FINAL_REVISION_PROMPT.md` — IT 학술대회 v11 최종 개정 요구
3. `final1.md` — 저장소·PPT·study·release 품질과 재현성 Gate

두 문서가 충돌하면 더 최근의 v11 명칭과 사용자 승인 16장 발표 구성을 적용한다. 사실성,
공개성, 재현성, 보안 요구는 두 문서의 더 엄격한 조건을 적용한다.

`final1.md`의 “구현과 실험을 확장하지 않는다”는 초기 release-only 범위는 이후
사용자가 “논문·연구 데이터·구조 설계를 먼저 끝내라”고 직접 변경했고, v11 목표도
연구 인과 보강을 요구하므로 superseded로 기록한다. 대신 `final1.md`의 Makefile,
archive, PDF timeout, README, study, release, secret scan Gate는 그대로 유지한다.

| 구분 | 최종 요구 | 현재 상태 | 완료 조건 |
|---|---|---|---|
| 연구 중심 | K26 연산부와 확장형 Memory FPGA 공급부의 공동설계 | **PASS** | 논문·발표 모두 구조의 필요성, 동작, 효과 조건과 채택 조건을 중심으로 재구성 |
| 닫힌 데이터 경로 | 작업→DMA→메모리 응답→링크→연산 입력 FIFO→MatVec | **PASS(논리 경로)** | 실제 Gemma 대표 타일 3개의 ID·byte·cycle·결과 일치 RTL trace 보존; 물리 GTH/MIG/CDC는 미완료로 명시 |
| 실험 인과 | 원격 이동 비용이 링크 서비스 시간에 반영 | **PASS** | 기본/추가 전송 byte와 cycle을 분리하고 통제 실험 전부 재실행 |
| Gemma 의존성 | layer와 autoregressive token 장벽 | **PASS** | qkv→o→gate/up→down→다음 layer와 lm_head→다음 token 장벽 적용 |
| 작업 단위 | 투영 하나가 아닌 출력 타일 | **PASS** | 실제 K/N 형상에서 full-K, N≤1024 분석 타일 생성; 802 TileJobs/token |
| 배치 민감도 | 초기 배치 효과와 작업 훔치기 효과 분리 | **PASS** | source rule·round robin·size aware·channel affinity 비교 |
| K26-local 기준선 | 외부 메모리 채택 임계값 | **PASS** | 동일 조건 용량·대역폭 민감도에서 K26-local을 우선 기준선으로 판정 |
| KiCad | 정확한 범위의 인터페이스 참조 설계 | **PASS(제한 쿠폰)** | K26–Memory FPGA 경계, GTH/refclk, 대표 DDR3L 라우팅 쿠폰과 ERC/DRC 범위를 명시; 제작 가능 보드 주장은 금지 |
| 비용·에너지 | DRAM 부품 비용과 모델 추정만 사용 | **PASS(모델 범위)** | DRAM die 비용·분석 에너지 민감도만 제시하고 FPGA 가격·전체 BOM·실측 전력은 제외 |
| 논문 | 독립 국문 v11 최종본, 약 10쪽 | **PASS** | 제출본 8쪽·기술보고서 10쪽, v11-r1~r5와 v11-final 및 검토·변경 기록 보존 |
| 논문 언어 | 자연스러운 한국어, 내부 감사 문체 제거 | **PASS** | 최종 언어 검토와 PDF 텍스트 감사를 통과 |
| 발표 | 사용자 승인 16장, 9:20~9:50, 목차와 진행 표시 | **PASS** | 16장, 목표 590초·낭독 추정 578.0초, PPTX/PDF/notes/source index/PNG/contact sheet; 본선 30·10·20·5점 기준 매핑 |
| Manim | 설명 기능이 있는 영상 3개 이상 | **PASS** | 데이터 흐름·작업 재분배·타임라인·꼬리 지연·병목 이동 영상과 정지 fallback 생성 |
| 발표 편집성 | 텍스트·도형·그래프 편집 가능 | **PASS** | 16장 검증, 4개 내장 영상, 텍스트·도형 중심 구성; 전체 슬라이드 이미지화 없음 |
| Q&A | 80개 이상, v11 연구 중심 | **PASS** | 연구 중심 89문항과 본선 심사 전략을 포함한 34쪽 학습 자료 PDF 완성 |
| 공개 인덱스 | 논문·슬라이드·표·그림·영상·Q&A 한곳 연결 | **PASS** | `conference_package/INDEX.md`와 슬라이드별 출처·해석 경계 연결 |
| README | 한국어 최소 공개 진입점 | **PASS** | 구조·핵심 결과·Quick start·재현 명령·산출물 경로를 간결하게 제공 |
| 저장소 정리 | Release ZIP과 대형 미디어를 main에서 제거 | **PASS** | ZIP·대형 MP4/GIF 추적 제거 및 `.gitignore`; 로컬 Release 자산은 유지 |
| GitHub | `conference-final`, 최종 commit/tag/release | **PASS** | 공개 기준선 `fe65fd6`·annotated tag `v11-conference-final`과 자산 17개는 불변 보존; 16장 발표 개정은 `conference-final` 후속 커밋, Draft PR #3 유지 |
| Actions | 오류 없는 공개 자동화 | **PASS** | 실패하던 공개 workflow를 삭제했고 현재 `.github/workflows` 추적 파일 0개 |
| 보안 | 비밀정보·내부 토큰 0건 | **PASS** | 현재 산출물·중첩 Release 자산 949개 고신뢰 패턴 0건; 소유자가 과거 PDF 경보 #1을 `false_positive`로 해소 |
| 독립 검토 | 최소 5회 | **PASS** | 가속기 기여·인과·한국어 가독성·하드웨어 시각·발표/Q&A·최종 언어의 6회 검토와 대응 기록 보존 |
| 최종 검증 | make 계약·fresh archive·시각 QA | **PASS** | unit/RTL/paper/presentation/reproduce/release, 실제 공식 source archive와 GitHub archive, checksum 검증 통과 |

## 현재 금지 주장

- 실제 보드에서 측정한 성능 또는 전력
- 완성된 생산용 DDR/GTH/MIG 구현
- 전체 가속기 가격 또는 저비용 달성
- 3B 모델 실행 완료
- 제작 가능한 PCB
- 요청 단위 꼬리 지연 개선
- 모든 조건에서 우월한 작업 훔치기
- 의존성을 무시한 기존 32-token pooled 결과를 실제 decode-32로 해석

## P0 처리 결과

1. 닫힌 논리 RTL 경로와 실제 타일 trace: 완료.
2. 원격 전송 비용·의존성·token 장벽 반영 실험: 완료.
3. K26-local 및 초기 배치 기준선: 완료.
4. 연구 동결 문서와 Figure source 교체: 완료.
5. 연구 동결 이후 v11 논문·16장 발표 생성: 완료.
6. 과거 Vault 경보: 소유자 `false_positive` 해소와 현재 자산 재귀 검사 0건으로 완료.

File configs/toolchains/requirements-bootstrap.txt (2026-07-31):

pip==24.0 \
    --hash=sha256:ba0d021a166865d2265246961bec0152ff124de910c5cc39f1156ce3fa7c69dc
setuptools==65.5.0 \
    --hash=sha256:f62ea9da9ed6289bfe868cd6845968a2c854d1427f8548d52cae02a42b4f0356
cmake==4.4.0 \
    --hash=sha256:51bcb2e65c0d5c1af4a749ba40a321b7436420c7359724ab46719004f3cd2149
ninja==1.13.0 \
    --hash=sha256:fb46acf6b93b8dd0322adc3a4945452a4e774b75b91293bafcc7b7f8e6517dfa
wheel==0.45.1 \
    --hash=sha256:708e7481cc80179af0e556bbf0cc00b8444c7321e2700b8d8580231d13017248

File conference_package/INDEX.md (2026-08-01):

# 학술대회 공개 패키지

이 인덱스는 논문, 발표, 실험 근거, 물리 참조 설계와 발표 준비 자료를 한곳에서
연결한다. 수치는 별도 표기가 없으면 분석 모델 결과이며 보드 실측값이 아니다.

## 최종 논문

- 원고: [`paper/final/submission_manuscript.md`](../paper/final/submission_manuscript.md)
- 제출 PDF: [`paper/final/submission_manuscript.pdf`](../paper/final/submission_manuscript.pdf)
- 그림·배치 목록: [`paper/final/figure_manifest.csv`](../paper/final/figure_manifest.csv)
- 코드·데이터 공개 범위: [`paper/final/code_and_data_availability.md`](../paper/final/code_and_data_availability.md)
- 개정 이력: [`paper/revisions/`](../paper/revisions/)

## 9분 50초 발표

- 편집 가능한 PPTX: [`presentation/final/presentation.pptx`](../presentation/final/presentation.pptx)
- PDF: [`presentation/final/presentation.pdf`](../presentation/final/presentation.pdf)
- 발표자 노트: [`presentation/final/speaker_notes.md`](../presentation/final/speaker_notes.md)
- 슬라이드별 출처·허용/금지 해석: [`presentation/final/slide_source_index.md`](../presentation/final/slide_source_index.md)
- 슬라이드 PNG와 전체 미리보기: [`presentation/final/slides/`](../presentation/final/slides/),
  [`presentation/final/slide_contact_sheet.png`](../presentation/final/slide_contact_sheet.png)
- Manim 생성 코드: [`presentation/tools/manim_scenes.py`](../presentation/tools/manim_scenes.py)

MP4/GIF는 저장소 용량을 줄이기 위해 GitHub Release 자산으로 제공한다. PPTX에는
데이터 흐름, 작업 훔치기, 실행 타임라인, 병목 이동 영상 네 개가 직접 포함되어 있다.

## 연구 데이터와 재현

- 연구 동결 요약: [`research/v11_research_freeze.md`](../research/v11_research_freeze.md)
- 정책 짝비교: [`results/experiments/paired_policy_effects.csv`](../results/experiments/paired_policy_effects.csv)
- Gemma 의존성·배치 민감도: [`results/model_level/gemma3_1b_placement_sensitivity.csv`](../results/model_level/gemma3_1b_placement_sensitivity.csv)
- K26 로컬/외부 후보 민감도: [`results/model_level/k26_local_external_sensitivity.csv`](../results/model_level/k26_local_external_sensitivity.csv)
- 닫힌 논리 RTL 추적: [`evidence/model/gemma3_1b_closed_loop_trace.csv`](../evidence/model/gemma3_1b_closed_loop_trace.csv)
- 전체 재현: 저장소 루트에서 `make setup && make reproduce`

## RTL과 KiCad 범위

- 논리 폐루프 RTL: [`hw/src/main/scala/varp/k26/ClosedLoopVirtualPrototypeTop.scala`](../hw/src/main/scala/varp/k26/ClosedLoopVirtualPrototypeTop.scala)
- 모델–RTL 계약: [`docs/model_rtl_contract.md`](../docs/model_rtl_contract.md)
- 시스템 구조와 미구현 물리 경로: [`docs/architecture.md`](../docs/architecture.md)
- Native KiCad 원본: [`hardware/kicad/`](../hardware/kicad/)

KiCad 자료는 인터페이스 라우팅 참조 쿠폰이며 **NOT FOR FABRICATION**이다. GTH
직렬화, CDC/크레딧, MIG/DDR 물리 타이밍, SI/PI와 보드 실측은 후속 검증 범위다.

## 발표 준비

- 89개 예상 질문과 답변: [`study/10_qna_bank.md`](../study/10_qna_bank.md)
- 통합 학습자료 PDF: [`study/study_pack.pdf`](../study/study_pack.pdf)
- 화이트보드 설명: [`study/11_whiteboard_explanations.md`](../study/11_whiteboard_explanations.md)
- 주장 경계: [`study/09_claim_boundary.md`](../study/09_claim_boundary.md)
- 본선 심사 A등급 대응 전략: [`study/15_final_round_scoring_strategy.md`](../study/15_final_round_scoring_strategy.md)

## 최종 검증과 공개 상태

- 요구사항 감사표: [`docs/final_closure/requirements_audit.md`](../docs/final_closure/requirements_audit.md)
- 최종 Gate 기록: [`docs/final_closure/final_validation.md`](../docs/final_closure/final_validation.md)
- 본선 심사 기준 감사표: [`docs/final_closure/final_round_scoring_audit.md`](../docs/final_closure/final_round_scoring_audit.md)
- Release checksum: [`release/checksums.sha256`](../release/checksums.sha256)
- 공개 Release: [`v11-conference-final`](https://github.com/snowman0919/varp-k26-memory-fpga/releases/tag/v11-conference-final)

로컬 산출물과 공식 소스 아카이브 검증은 통과했다. 과거 PDF의 GitHub 경보 #1은
저장소 소유자가 `false_positive`로 해소했고, 현재 패키지 재귀 검사도 0건이다.
`v11-conference-final` tag와 Release는 공개 당시 기준선으로 보존한다. 이후 요청된
16장 발표 개정은 tag를 이동하지 않고 `conference-final` 브랜치 최신 커밋에서 제공한다.

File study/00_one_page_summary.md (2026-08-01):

# 한 장 요약

## 무엇을 만들었나

Kria K26이 연산·제어를 맡고 외부 Memory FPGA가 다채널로 가중치를 공급하는
확장 후보 구조를 설계했다. Work Stealing은 유휴 클러스터가 생길 때 데이터 이동
비용보다 이득이 큰 작업만 옮기는 보조 정책이다.

## 왜 필요한가

Gemma 3 1B INT8와 문맥 32K의 용량 모델은 2.43 GiB로 K26 4GB 안에 들어간다.
따라서 외부 8GB의 이유는 단순 용량이 아니라 더 큰 모델·긴 문맥·로컬 경합에서
가중치 공급을 실행 메모리와 분리할 가능성이다.

## 무엇을 확인했나

- ONNX 7,837개 노드에서 토큰당 183개 투영을 찾아 802개 TileJob으로 변환했다.
- 대표 실제 가중치 타일 3개가 폐루프 논리 RTL을 통과해 INT32 결과와 일치했다.
- 합성 편향 부하에서 S3 대 S1 TileJob p95 −19.13%, p99 −18.71%였다.
- Gemma 형상은 초기 배치에 따라 p95 효과가 +0.28%에서 −19.79%까지 바뀌었다.
- 시험한 민감도에서 외부 후보는 K26 로컬 기준선을 이기지 못했다.

## 결론

Gemma 1B는 K26 로컬을 우선한다. 외부 메모리와 Work Stealing은 남은 불균형이
이동 비용보다 큰 확장 조건에서 다시 평가한다. 보드 성능·전력, 전체 가격,
제작 가능한 PCB는 주장하지 않는다.

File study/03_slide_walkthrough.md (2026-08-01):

# 16장 슬라이드 순회

1. 연구 주제는 확장형 K26–Memory FPGA 공동설계다.
2. 필요성→구조→검증→채택 조건을 답한다.
3. 1B가 4GB에 들어가 질문을 용량에서 공급 분리로 바꿨다.
4. 부하 균형 이득이 이동 비용보다 큰가를 묻는다.
5. K26은 계산, Memory FPGA는 가중치 공급을 맡는다.
6. 실제 타일 3개가 폐루프 논리 RTL을 통과했다.
7. 정적 큐는 지역성을 지키지만 유휴 클러스터를 만든다.
8. S3는 이동 비용이 이득보다 작을 때만 작업을 옮긴다.
9. 183개 투영을 의존성 있는 802개 TileJob으로 바꾼다.
10. 동일 작업·시드에서 정책만 바꾼 사건을 비교한다.
11. 효과는 부하 불균형과 초기 배치에 조건부다.
12. 병목은 큐에서 링크·메모리 서비스로 이동한다.
13. KiCad 결과는 제작 보드가 아니라 참조 라우팅 쿠폰이다.
14. 현재 한계를 K26 기준선·물리 폐루프·동일 추적 재평가의 순서로 바꾼다.
15. 후보 구조·효과 조건·현재 채택 판단을 세 문장으로 결론 낸다.
16. Q&A 화면에서 멈추고 상세 답변은 발표자 참고 자료로만 준비한다.

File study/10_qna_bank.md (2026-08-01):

# 예상 질문과 답변

총 89문항이다. 먼저 짧게 답하고, 필요할 때 근거 파일과 주의할 해석을 덧붙인다.

## Q01. 연구의 한 문장 질문은?

- **짧은 답:** K26 계산부와 외부 Memory FPGA를 결합할 가치가 있는 조건, 그리고 작업 훔치기가 그 구조의 유휴 연산을 줄이는 조건을 묻는다.
- **상세 답:** Gemma 3 1B를 의존성 있는 TileJob으로 바꾸고, K26 로컬 기준선·초기 배치·큐 정책·원격 이동 비용을 함께 비교한다.
- **근거:** `paper/final/submission_manuscript.md — “I. 서론”, “VIII. 결과와 시스템 설계 결정”`
- **주의할 해석:** ‘외부 FPGA가 빠르다’로 바꾸면 보드 증거를 과장한다.

## Q02. 왜 단순히 ‘메모리 대역폭이 중요하다’는 말보다 진전인가?

- **짧은 답:** 병목을 대기열 정책과 검증 가능한 지표로 바꿨기 때문이다.
- **상세 답:** 실제 그래프 기반 작업, p95/p99, 원격 전송량, 정확히 한 번 처리 조건과 다음 물리 관문을 연결했다.
- **근거:** `paper/final/submission_manuscript.md — “I. 서론”, “II. 관련 연구와 연구 공백”`
- **주의할 해석:** 알고리즘 신규성이나 최고 성능으로 과장하면 안 된다.

## Q03. 핵심 기여 세 가지는?

- **짧은 답:** 역할 분리 구조, 이동 비용을 포함한 동적 작업 배치, 모델→RTL→KiCad 재현 흐름이다.
- **상세 답:** K26의 연산·제어와 Memory FPGA의 다채널 가중치 공급을 분리하고, 의존성·초기 배치·원격 서비스 비용을 포함해 정책을 비교했으며, 실제 타일의 논리 RTL 폐루프와 참조 라우팅 쿠폰까지 연결했다.
- **근거:** `paper/final/submission_manuscript.md — “I. 서론”`
- **주의할 해석:** 완성 시스템 구현을 기여로 추가하면 과장이다.

## Q04. 이 연구는 완성된 가속기인가?

- **짧은 답:** 아니다.
- **상세 답:** 작업 수락→DMA 요청→논리 메모리 응답→논리 링크 FIFO→작업 ID 결합→MatVec 결과의 RTL 경로는 닫혔다. 다만 GTH 직렬화, 클록 도메인 교차·크레딧, 실제 MIG/DDR 타이밍과 보드 계측은 아직 없다.
- **근거:** `docs/architecture.md`
- **주의할 해석:** 논리 폐루프를 물리 GTH–DDR 폐루프 또는 보드 구현으로 확대하면 안 된다.

## Q05. 어떤 증거 유형이 있는가?

- **짧은 답:** 직접 확인, RTL 시뮬레이션, 그래프 기반, 분석 모델, 미검증이다.
- **상세 답:** 각 유형은 지원 가능한 주장과 금지 주장을 표 2에서 고정한다.
- **근거:** `docs/evidence.md; paper/final/submission_manuscript.md — “IV. K26–Memory FPGA 시스템 구조”, 표 2`
- **주의할 해석:** 유형을 생략하면 분석값이 실측처럼 들린다.

## Q06. 결론을 한 문장으로 말하면?

- **짧은 답:** S3는 불균형 조건의 후보이며 외부 메모리 채택은 실측 기준선까지 보류한다.
- **상세 답:** 편향·혼합 부하의 꼬리 지연·전송량 이득은 분석 모델 결과이며 용량만으로 8 GiB 필요성을 지지하지 않는다.
- **근거:** `paper/final/submission_manuscript.md — “VIII. 결과와 시스템 설계 결정”, “IX. PCB 인터페이스 라우팅 쿠폰”`
- **주의할 해석:** ‘S3 채택 확정’으로 말하지 않는다.

## Q07. 증거 경계를 왜 함께 제시하는가?

- **짧은 답:** 연구의 중심 기여는 아니지만 분석·RTL·물리 쿠폰의 효력을 구분하기 위해서다.
- **상세 답:** 그래프, RTL, 분석 모델, 물리 제안의 연결 여부를 명시해 다음 실험을 선택할 수 있다.
- **근거:** `docs/evidence.md`
- **주의할 해석:** 한계를 단순한 미완성 변명으로 축소하지 않는다.

## Q08. 가장 중요한 다음 실험은?

- **짧은 답:** 동일 Gemma 작업으로 K26 로컬 메모리 기준선을 보드에서 먼저 측정하는 것이다.
- **상세 답:** 그 다음 GTH, 클록 도메인 교차, 크레딧, 패킷과 MIG를 논리 폐루프에 붙이고, 정확성·유효 대역폭·꼬리 지연·전력을 로컬 기준선과 같은 조건에서 측정한다.
- **근거:** `docs/architecture.md`
- **주의할 해석:** 바로 보드 성능 수치를 약속하지 않는다.

## Q09. Prefill이란?

- **짧은 답:** 입력 문맥을 처리해 KV cache를 만드는 단계다.
- **상세 답:** 여러 토큰을 병렬 계산할 여지가 크고 Attention의 행렬 연산 형태가 Decode와 다르다.
- **근거:** `study/04_glossary.md`
- **주의할 해석:** 본 결과를 prefill 성능으로 확대하지 않는다.

## Q10. Decode란?

- **짧은 답:** 이전 KV를 사용해 다음 토큰을 순차 생성하는 단계다.
- **상세 답:** 작은 배치에서는 투영 가중치를 반복 전송하므로 메모리와 대기열의 꼬리 지연이 중요해진다.
- **근거:** `paper/final/submission_manuscript.md — “I. 서론”, “III. 온디바이스 가속기의 설계 목표”`
- **주의할 해석:** decode-32와 context-32K를 혼동하지 않는다.

## Q11. Decode-32와 context-32K의 차이는?

- **짧은 답:** 32개 생성 토큰과 KV 길이 32,768의 차이다.
- **상세 답:** Decode-32는 의존성 있는 802 TileJob/토큰을 32번 직렬 반복한 25,664 TileJob이고, context-32K는 KV와 실행 여유를 포함한 용량 산술 조건이다.
- **근거:** `paper/final/submission_manuscript.md — “III. 온디바이스 가속기의 설계 목표”, “V. Gemma 3 1B 작업의 하드웨어 매핑”`
- **주의할 해석:** 둘을 같은 부하 길이로 말하면 계산 의미가 바뀐다.

## Q12. 투영 작업 부하는 무엇인가?

- **짧은 답:** Attention과 MLP의 선형변환 작업이다.
- **상세 답:** q/k/v/o 104, gate/up/down 78, lm_head 1로 토큰당 183개다.
- **근거:** `paper/final/submission_manuscript.md — “V. Gemma 3 1B 작업의 하드웨어 매핑”`
- **주의할 해석:** 전체 ONNX 노드가 모두 투영이라고 말하지 않는다.

## Q13. MatVec는 무엇인가?

- **짧은 답:** 행렬 타일과 벡터의 곱이다.
- **상세 답:** 현재 RTL 연산 모듈은 부호 있는 INT8 16×4 입력을 INT32 누산 결과로 계산한다.
- **근거:** `paper/final/submission_manuscript.md — “V. Gemma 3 1B 작업의 하드웨어 매핑”; hw/src/main/scala/varp/compute/ComputeCluster.scala; hw/src/main/scala/qk/DecodeMatVecInt8.scala`
- **주의할 해석:** 전체 투영 연산기나 모델 실행으로 확대하지 않는다.

## Q14. 타일 분할이 필요한 이유는?

- **짧은 답:** 큰 투영을 제한된 연산·메모리 단위로 나누기 위해서다.
- **상세 답:** TileJob이 K/N 범위, 주소와 선호 채널·링크 묶음을 보존한다.
- **근거:** `paper/final/submission_manuscript.md — “V. Gemma 3 1B 작업의 하드웨어 매핑”`
- **주의할 해석:** 현재 타일 시험 입력이 전체 배치를 검증했다고 말하지 않는다.

## Q15. INT8과 INT4의 차이는?

- **짧은 답:** 가중치 비트폭과 표현 범위가 다르다.
- **상세 답:** INT4는 저장·전송량을 더 줄일 수 있지만 묶음 배치, 스케일, 정확도와 RTL 데이터 경로 검증이 별도로 필요하다.
- **근거:** `paper/final/submission_manuscript.md — “V. Gemma 3 1B 작업의 하드웨어 매핑”; study/04_glossary.md`
- **주의할 해석:** 이 연구 자료가 INT4를 구현했다고 말하지 않는다.

## Q16. 실제 타일 결과 일치 3/3은 무엇을 증명하는가?

- **짧은 답:** 세 실제 16×4 가중치 타일의 RTL 산술 일치를 증명한다.
- **상세 답:** 외부 데이터 오프셋에서 읽고 타일별 대칭 INT8로 양자화한 값이 INT32 기준 결과와 일치했다.
- **근거:** `paper/final/submission_manuscript.md — “V. Gemma 3 1B 작업의 하드웨어 매핑”`
- **주의할 해석:** 모델 전체 정확도나 K26 타이밍을 증명하지 않는다.

## Q17. ONNX 그래프 노드 수는?

- **짧은 답:** 7,837개다.
- **상세 답:** 해시로 고정한 연구 자료의 protobuf 그래프 목록에서 얻은 그래프 기반 수치다.
- **근거:** `paper/final/submission_manuscript.md — “V. Gemma 3 1B 작업의 하드웨어 매핑”`
- **주의할 해석:** 다른 모델 버전에 일반화하지 않는다.

## Q18. 토큰당 투영 수는?

- **짧은 답:** 183개다.
- **상세 답:** Attention 104, MLP 78, lm_head 1의 합이다.
- **근거:** `paper/final/submission_manuscript.md — “V. Gemma 3 1B 작업의 하드웨어 매핑”`
- **주의할 해석:** 실제 가속기가 183개를 실행했다는 뜻은 아니다.

## Q19. 모델 가중치가 저장소에 있는가?

- **짧은 답:** 없다.
- **상세 답:** 목록, 해시와 획득 안내서만 공개하며 가중치는 릴리스에서도 제외한다.
- **근거:** `models/ACQUISITION.md; models/LICENSE_NOTES.md`
- **주의할 해석:** 재배포 권한이 있다고 암시하지 않는다.

## Q20. 183개 투영과 802개 TileJob의 차이는?

- **짧은 답:** 투영은 그래프 연산 단위이고 TileJob은 하드웨어가 처리할 K/N 타일 단위다.
- **상세 답:** 토큰당 밀집 투영 183개를 N≤1024와 전체 K 범위의 작업으로 나누면 802 TileJob이 된다. 최종 결론은 구형 호스트 지연값에 기대지 않는다.
- **근거:** `paper/final/submission_manuscript.md — “V. Gemma 3 1B 작업의 하드웨어 매핑”; results/model_level/gemma3_1b_dependency_manifest.json`
- **주의할 해석:** 투영 수를 실행 작업 수로 그대로 사용하지 않는다.

## Q21. TileJob의 핵심 필드는?

- **짧은 답:** 작업 식별자, 범위, 주소, 지역성과 소유권 정보다.
- **상세 답:** 작업 ID, 도착 시점, 계층·연산, 활성값·가중치·출력 주소, K/N, 선호 채널·링크 묶음, 우선순위, 이동 가능 표시를 가진다.
- **근거:** `paper/final/submission_manuscript.md — “IV. K26–Memory FPGA 시스템 구조”`
- **주의할 해석:** Python 모델과 RTL의 소유권 정의가 완전히 같다고 말하지 않는다.

## Q22. 연산 경로의 닫힌 구간은?

- **짧은 답:** 작업 수락→DMA 요청→논리 응답→논리 링크 FIFO→작업 ID 결합→MatVec 결과다.
- **상세 답:** `ClosedLoopVirtualPrototypeTop`은 실제 Gemma INT8 타일 세 개에 대해 DMA 응답 뒤에만 계산을 시작하고 INT32 기준 결과까지 작업 식별자를 보존한다.
- **근거:** `docs/architecture.md`
- **주의할 해석:** 논리 응답 주입을 실제 DDR3L 읽기나 GTH 전송으로 부르지 않는다.

## Q23. 메모리 명령 경로는 무엇을 하는가?

- **짧은 답:** 외부 요청을 채널·뱅크 대기열을 거쳐 명령으로 내보낸다.
- **상세 답:** 폐루프 상위 모듈에서는 명령과 작업 ID를 보존한 뒤 시험 응답 경계에서 데이터를 주입한다. 물리 MIG/DDR 제어기와 타이밍은 아직 연결하지 않았다.
- **근거:** `docs/architecture.md`
- **주의할 해석:** 완전한 DDR 제어기나 DMA로 부르지 않는다.

## Q24. 링크 경로는 무엇을 하는가?

- **짧은 답:** 응답 데이터를 선택한 링크 묶음의 논리 FIFO로 전달한다.
- **상세 답:** 폐루프 상위 모듈에서 데이터와 작업 ID가 MatVec까지 이어지지만, GTH 래퍼·패킷 구성·크레딧·클록 도메인 교차는 후속 물리 구현 범위다.
- **근거:** `docs/architecture.md`
- **주의할 해석:** 실제 유효 대역폭을 측정했다고 말하지 않는다.

## Q25. 왜 TileJob 대기열과 전송 FIFO를 분리하는가?

- **짧은 답:** 작업 배치와 바이트 이동의 원인을 분리하기 위해서다.
- **상세 답:** 전자는 실행 소유권, 후자는 크레딧·역압과 전송 시점을 결정한다.
- **근거:** `paper/final/submission_manuscript.md — “IV. K26–Memory FPGA 시스템 구조”`
- **주의할 해석:** 대기열 개선을 링크 개선으로 등치하지 않는다.

## Q26. 역압(Backpressure)이란?

- **짧은 답:** 뒤쪽 단계가 받을 수 없을 때 앞쪽 전송을 늦추는 흐름 제어 현상이다.
- **상세 답:** 현재 논리 경로는 Stream/FIFO의 준비·유효 신호 기반 역압을 구현했다. 물리 링크의 크레딧 흐름 제어와 클록 도메인 교차는 아직 구현하지 않았으며, 작업 대기열 불균형과도 다른 원인이다.
- **근거:** `study/04_glossary.md`
- **주의할 해석:** 논리 FIFO 역압을 물리 GTH 링크의 크레딧·클록 도메인 교차 구현으로 확대하지 않는다.

## Q27. CDC란?

- **짧은 답:** 서로 다른 클록 도메인 사이의 안전한 전달이다.
- **상세 답:** 동기화 회로나 비동기 FIFO와 준안정성 분석이 필요하다.
- **근거:** `docs/architecture.md`
- **주의할 해석:** 단순 FIFO를 클록 도메인 교차 완료로 간주하지 않는다.

## Q28. DDR channel/bank/row의 관계는?

- **짧은 답:** 채널은 독립 인터페이스, 뱅크는 내부 병렬 단위, 행은 뱅크 안에서 열린 데이터 단위다.
- **상세 답:** 주소 매핑과 행 적중 여부가 서비스 시간과 경합을 바꾼다.
- **근거:** `paper/final/submission_manuscript.md — “IV. K26–Memory FPGA 시스템 구조”; study/04_glossary.md`
- **주의할 해석:** 핀 전송률을 유효 대역폭으로 말하지 않는다.

## Q29. 네 채널 대역폭 산술값은?

- **짧은 답:** 4×16비트×800 MT/s를 가정하면 6.4 GB/s다.
- **상세 답:** 6.4 GB/s는 이 특정 핀 구성의 오버헤드 전 산술값이다. 12.8 GB/s는 더 넓거나 빠른 외부 구성을 가정한 별도의 민감도 지점이며, 둘 다 실측값이 아니다.
- **근거:** `paper/final/submission_manuscript.md — “IV. K26–Memory FPGA 시스템 구조”; results/capacity/README.md`
- **주의할 해석:** 실측 유효 대역폭으로 인용하지 않는다.

## Q30. FIFO란?

- **짧은 답:** 먼저 들어온 항목을 먼저 처리하는 대기열이다.
- **상세 답:** S1 로컬 FCFS는 지역성을 보존하지만 편향 부하에서 유휴 상태를 만들 수 있다.
- **근거:** `paper/final/submission_manuscript.md — “VI. 다중 대기열과 지역성 인식 작업 재분배”`
- **주의할 해석:** 중앙 FIFO의 물리 비용이 0이라고 가정하지 않는다.

## Q31. S0는 무엇인가?

- **짧은 답:** 이상적 전역 FIFO 기준선이다.
- **상세 답:** 불균형의 참고 하한을 주지만 중재·팬아웃·교차 연결 비용과 원격 저장을 단순화한다.
- **근거:** `docs/calibration.md; results/experiments/scheduler_controlled.csv`
- **주의할 해석:** 실제 RTL 구현이나 최적 구현으로 부르지 않는다.

## Q32. S1은 무엇인가?

- **짧은 답:** 원래 클러스터의 로컬 FIFO만 사용하는 정적 정책이다.
- **상세 답:** 원격 이동이 없지만 편향 부하에서 다른 클러스터가 유휴 상태일 수 있다.
- **근거:** `paper/final/submission_manuscript.md — “VI. 다중 대기열과 지역성 인식 작업 재분배”`
- **주의할 해석:** 모든 조건에서 나쁜 정책이라고 일반화하지 않는다.

## Q33. S2는 무엇인가?

- **짧은 답:** 유휴 클러스터가 가장 오래된 실행 가능 작업을 훔치는 정책이다.
- **상세 답:** 대기 시간을 우선해 균형을 개선하지만 원격 전송량이 커질 수 있다.
- **근거:** `paper/final/submission_manuscript.md — “VI. 다중 대기열과 지역성 인식 작업 재분배”`
- **주의할 해석:** 지역성 인식 정책이라고 부르지 않는다.

## Q34. S3는 무엇인가?

- **짧은 답:** 대기 시간과 지역성 비용을 함께 보는 작업 훔치기 정책이다.
- **상세 답:** 점수는 원격 가중치, 활성값, 부분합 소유자, 링크 묶음 불일치를 반영한 하나의 설계 지점이다.
- **근거:** `paper/final/submission_manuscript.md — “VI. 다중 대기열과 지역성 인식 작업 재분배”`
- **주의할 해석:** 새로운 최적 알고리즘으로 주장하지 않는다.

## Q35. 작업 훔치기가 RTL에 구현됐는가?

- **짧은 답:** 제한된 스케줄러 RTL과 검증용 시험 경로에 구현됐다.
- **상세 답:** 별도 스케줄러 RTL 시험에서 작업 소유권 이동과 정확히 한 번 완료를 검증했고, 폐루프 상위 모듈에서는 실제 Gemma 타일의 DMA–응답–MatVec 작업 ID 보존을 검증했다. 두 시험은 아직 하나의 물리 GTH/MIG 실행으로 합쳐지지 않았다.
- **근거:** `paper/final/submission_manuscript.md — “VII. 구현과 평가 방법”; hw/src/test/scala/varp/`
- **주의할 해석:** Gemma 전체가 DDR과 링크를 거쳐 실행됐다고 말하지 않는다.

## Q36. 지역성 점수는 어떻게 쓰는가?

- **짧은 답:** 대기 시간에서 이동 관련 비용을 빼 후보를 고른다.
- **상세 답:** 양수 임계값과 계수는 보정되지 않은 설계 지점이며 민감도 한계가 있다.
- **근거:** `paper/final/submission_manuscript.md — “VI. 다중 대기열과 지역성 인식 작업 재분배”`
- **주의할 해석:** 보편적 최적값이라고 부르지 않는다.

## Q37. S3가 항상 S0보다 좋은가?

- **짧은 답:** 아니다.
- **상세 답:** S0는 중앙 공유 비용을 생략한 이상적 참고선이다. 최종 채택 판단은 S0 우열이 아니라 실제 가능한 S1/S2/S3와 K26 로컬 기준선 사이에서 한다.
- **근거:** `docs/calibration.md; results/experiments/scheduler_controlled.csv`
- **주의할 해석:** S0의 원격 전송량 0 B를 물리 측정으로 사용하지 않는다.

## Q38. 왜 S3가 S0보다 느릴 수 있는가?

- **짧은 답:** 로컬 큐, 실행 가능성, 지역성 비용이 선택을 제한하기 때문이다.
- **상세 답:** S0는 중앙 중재·팬아웃·교차 연결·원격 저장 비용을 대부분 생략한 이상 참고선이기 때문이다.
- **근거:** `results/experiments/paired_policy_effects.csv; docs/calibration.md`
- **주의할 해석:** 분산 구조의 물리 열세가 증명됐다고 말하지 않는다.

## Q39. S3가 균형 부하에서 이득이 없는 이유는?

- **짧은 답:** 대기열 불균형이 없어 작업을 훔칠 필요가 없기 때문이다.
- **상세 답:** 다섯 동일 시드의 짝 비교에서 S3 대 S1 p95 효과가 0%였고 불필요한 작업 훔치기도 발생하지 않았다.
- **근거:** `paper/final/submission_manuscript.md — “VIII. 결과와 시스템 설계 결정”`
- **주의할 해석:** 다른 균형 부하까지 동일하다고 일반화하지 않는다.

## Q40. 채널 집중 조건에서 이득이 없는 이유는?

- **짧은 답:** 대기열보다 메모리 채널 병목이 지배하기 때문이다.
- **상세 답:** 다섯 동일 시드의 짝 비교에서 S3 대 S1 p95 효과가 0%였다. 실행 위치를 바꿔도 같은 메모리 집중을 피하지 못했기 때문이다.
- **근거:** `paper/final/submission_manuscript.md — “VIII. 결과와 시스템 설계 결정”`
- **주의할 해석:** 실제 DDR 채널 집중 측정으로 부르지 않는다.

## Q41. p95란?

- **짧은 답:** 표본의 95%가 그 이하인 지연 경계다.
- **상세 답:** 느린 5%가 시작되는 꼬리 지연 지표로 대화형 지연을 평균보다 잘 드러낸다.
- **근거:** `results/experiments/paired_policy_effects.csv; docs/calibration.md`
- **주의할 해석:** 단일 실행의 최악값과 같다고 말하지 않는다.

## Q42. p99를 함께 보는 이유는?

- **짧은 답:** 더 극단적인 꼬리 지연을 확인하기 위해서다.
- **상세 답:** S3 대 S1에서 편향 부하 p99는 18.71%, 혼합 부하 p99는 16.92% 감소했다. S3 대 S2 차이는 각각 약 1.69%, 1.89%로 비교 기준에 따라 해석이 달라진다.
- **근거:** `paper/final/submission_manuscript.md — “VIII. 결과와 시스템 설계 결정”`
- **주의할 해석:** 작은 차이를 보드 유의성으로 과장하지 않는다.

## Q43. 완료시간과 p95의 차이는?

- **짧은 답:** p95는 개별 꼬리 지연 분포, 완료시간은 마지막 작업 종료다.
- **상세 답:** S3는 p95를 줄이면서 큰 마지막 작업 때문에 완료시간을 소폭 늘릴 수 있다.
- **근거:** `paper/final/submission_manuscript.md — “VIII. 결과와 시스템 설계 결정”`
- **주의할 해석:** p95 개선을 전체 완료시간 개선으로 등치하지 않는다.

## Q44. 연산 동작률은 무엇인가?

- **짧은 답:** 실제 연산 사이클의 전체 클러스터 시간 비율이다.
- **상세 답:** 실제 MAC 동작에 가까운 정의지만 분석 모델에서 계산한 서비스 시간 값이다.
- **근거:** `results/experiments/paired_policy_effects.csv; docs/calibration.md`
- **주의할 해석:** 실제 FPGA 활용률 보고서로 부르지 않는다.

## Q45. 예약 점유율은 무엇인가?

- **짧은 답:** 배치부터 대기와 연산 완료까지 예약된 비율이다.
- **상세 답:** 링크·메모리 대기가 포함되어 0.99여도 연산기가 99% 동작한 것은 아니다.
- **근거:** `results/experiments/paired_policy_effects.csv; docs/calibration.md`
- **주의할 해석:** 활용률이라는 축약어만 쓰지 않는다.

## Q46. 미예약 유휴 시간이란?

- **짧은 답:** 클러스터가 예약되지 않은 사이클 수다.
- **상세 답:** 연산 유휴와 달리 예약 중 메모리·링크 대기는 포함하지 않는다.
- **근거:** `results/experiments/paired_policy_effects.csv; docs/calibration.md`
- **주의할 해석:** 전력 유휴 시간으로 직접 사용하지 않는다.

## Q47. 완전 중첩 모델은?

- **짧은 답:** 링크와 메모리를 동시에 시작해 둘 중 큰 값으로 데이터 준비 시점을 둔다.
- **상세 답:** 서비스 경계의 낙관적 가정이며 물리 트랜잭션 타이밍이 아니다.
- **근거:** `results/experiments/paired_policy_effects.csv; docs/calibration.md`
- **주의할 해석:** 실제 중첩 구현 증거로 말하지 않는다.

## Q48. 순차 모델은?

- **짧은 답:** 링크와 메모리 서비스를 직렬로 더한다.
- **상세 답:** 경계 민감도이며 편향 부하에서 S2/S3 순위가 뒤집힐 수 있다.
- **근거:** `results/experiments/service_overlap_sensitivity.csv; docs/calibration.md` (논문 본문의 핵심 결론과 분리한 보조 분석)
- **주의할 해석:** 실제 하드웨어가 순차라는 증거는 아니다.

## Q49. 왜 S3가 S0보다 항상 우수하지 않은가?

- **짧은 답:** 정책 목표와 비용 정의가 다르기 때문이다.
- **상세 답:** S3는 실제 가능한 로컬 큐에서 지역성을 지키며 불균형을 줄이고, S0는 중앙 공유 비용을 이상화한 참고선이므로 목표와 비용 경계가 다르다.
- **근거:** `docs/calibration.md; results/experiments/scheduler_controlled.csv`
- **주의할 해석:** S3의 구조적 필요성을 확정하지 않는다.

## Q50. 편향 부하에서 S1→S3 p95 변화는?

- **짧은 답:** 19.13% 감소다.
- **상세 답:** 동일한 1,000개 작업과 시드 다섯 개를 짝지어 계산한 효과의 중앙값이다. 절대 사이클보다 짝 비교 비율을 채택 근거로 사용한다.
- **근거:** `results/experiments/paired_policy_effects.csv`
- **주의할 해석:** 보드 지연 감소로 말하지 않는다.

## Q51. 혼합 부하에서 S1→S3 p95 변화는?

- **짧은 답:** 17.70% 감소다.
- **상세 답:** 동일 작업·동일 시드 다섯 쌍의 중앙값이며, 다른 부하에 자동으로 일반화하지 않는다.
- **근거:** `results/experiments/paired_policy_effects.csv`
- **주의할 해석:** 다른 부하에 일반화하지 않는다.

## Q52. S2→S3 원격 가중치 변화는?

- **짧은 답:** 편향 부하 35.49%, 혼합 부하 22.60% 감소다.
- **상세 답:** 동일 작업·동일 시드 짝 비교의 중앙값이다. S2는 가장 오래된 실행 가능 작업, S3는 지역성 비용까지 반영하므로 이동량 차이가 생긴다.
- **근거:** `results/experiments/paired_policy_effects.csv; paper/final/submission_manuscript.md — “VIII. 결과와 시스템 설계 결정”`
- **주의할 해석:** 실제 링크 전송량으로 말하지 않는다.

## Q53. S3 완료시간의 상충 관계는?

- **짧은 답:** S2보다 편향 부하는 0.01% 길고 혼합 부하는 0.93% 짧다.
- **상세 답:** 두 차이 모두 작으며, 꼬리 지연과 전송량 개선이 마지막 완료시간의 일관된 개선을 보장하지 않음을 보인다.
- **근거:** `paper/final/submission_manuscript.md — “VIII. 결과와 시스템 설계 결정”`
- **주의할 해석:** S3가 모든 지표를 개선한다고 말하지 않는다.

## Q54. 프로세스 반복 3회의 의미는?

- **짧은 답:** 동일 시드의 결정성 검사다.
- **상세 답:** 독립 표본 수가 아니라 재실행 결과 동일성을 확인한다.
- **근거:** `results/experiments/paired_policy_effects.csv; docs/calibration.md`
- **주의할 해석:** n=15로 통계 표본을 부풀리지 않는다.

## Q55. 시드 수는?

- **짧은 답:** 합성 부하 하위 집합에서 5개다.
- **상세 답:** 부하별 고정 시드 19, 23, 29, 31, 43의 중앙값을 사용한다.
- **근거:** `results/experiments/paired_policy_effects.csv; docs/calibration.md`
- **주의할 해석:** Gemma 재생도 5개 시드를 썼다고 말하지 않는다.

## Q56. 분석 사이클과 RTL 사이클이 같은가?

- **짧은 답:** 아니다.
- **상세 답:** 분석은 기본 64 MAC/사이클, 현재 RTL은 64 MAC의 요청부터 완료까지 65사이클이어서 발행률 차이가 65배다.
- **근거:** `docs/calibration.md; paper/final/submission_manuscript.md — “VII. 구현과 평가 방법”`
- **주의할 해석:** 분석 사이클을 FPGA 클록에 직접 환산하지 않는다.

## Q57. Python과 RTL 스케줄러 의미가 같은가?

- **짧은 답:** 완전히 같지 않다.
- **상세 답:** 원래 위치 정의, 피해 대기열 후보, 지역성 비용, 배치 폭이 다르다.
- **근거:** `docs/model_rtl_contract.md; paper/final/submission_manuscript.md — “VII. 구현과 평가 방법”`
- **주의할 해석:** 동일 구현 교차검증이라고 과장하지 않는다.

## Q58. 정확히 한 번 처리 조건은?

- **짧은 답:** 입력, 배치, 완료 작업 ID 집합이 같고 중복이 0이다.
- **상세 답:** 누락·중복을 숨긴 지연 개선이 아닌지 확인하는 정상성 관문이다.
- **근거:** `docs/model_rtl_contract.md; evidence/waveforms/work_stealing_events.csv`
- **주의할 해석:** 전체 DMA 경로 정확히 한 번 처리로 확대하지 않는다.

## Q59. DRAMsim3는 무엇을 하는가?

- **짧은 답:** DDR 타이밍 제약을 사이클 수준에서 모델링한다.
- **상세 답:** 채널·뱅크·행 타이밍을 다루지만 공개 보존본은 Gemma 재생과 결합되지 않았다.
- **근거:** `docs/dramsim3.md` (논문 본문의 핵심 결론과 분리한 보조 분석)
- **주의할 해석:** 보존본을 재현 가능한 종단 간 결과라 하지 않는다.

## Q60. DRAMsim3 결과가 에너지에 합산됐는가?

- **짧은 답:** 아니다.
- **상세 답:** 사이클 단위 결합이 없어 Gemma의 토큰당 에너지에 포함하지 않는다.
- **근거:** `docs/dramsim3.md; results/power_cost/README.md` (보조 분석)
- **주의할 해석:** 보존본을 현재 실행 결과로 말하지 않는다.

## Q61. 실제 전력을 측정했는가?

- **짧은 답:** 아니다.
- **상세 답:** Vivado 배치·배선 및 전력 보고서와 제작 보드 보정 측정이 없다.
- **근거:** `research/v11_research_freeze.md; results/power_cost/README.md`
- **주의할 해석:** 토큰당 에너지를 측정 전력으로 부르지 않는다.

## Q62. 토큰당 에너지는 무엇인가?

- **짧은 답:** 가정 범위의 동적 에너지 추정치다.
- **상세 답:** MAC pJ, 링크 pJ/bit, DRAM 동적 에너지 식을 결합하고 리프레시·유휴·PHY·보드를 제외한다.
- **근거:** `results/power_cost/README.md` (보조 분석)
- **주의할 해석:** 전체 보드 에너지로 말하지 않는다.

## Q63. 링크 에너지 민감도 범위는?

- **짧은 답:** 비트당 24/51.2/120 pJ다.
- **상세 답:** 하한·중앙·상한 가정으로 원격 전송량 민감도를 본다.
- **근거:** `results/power_cost/energy_category_model.csv; results/power_cost/energy_model_metadata.json` (보조 분석)
- **주의할 해석:** 실제 송수신기 측정값으로 말하지 않는다.

## Q64. MAC 에너지 민감도 범위는?

- **짧은 답:** INT8 MAC당 1/5/15 pJ다.
- **상세 답:** 공정에 독립적인 설계 민감도이며 구현 전력 보고서가 아니다.
- **근거:** `results/power_cost/energy_category_model.csv; results/power_cost/energy_model_metadata.json` (보조 분석)
- **주의할 해석:** K26 소자의 보장값으로 인용하지 않는다.

## Q65. 메모리 다이 비용 정규화 지표는?

- **짧은 답:** DRAM 패키지 가격을 내부 다이 수로 나눈 산술이다.
- **상세 답:** 베어 다이 견적이나 전체 BOM이 아니라 용량·비용 민감도용 정규화다.
- **근거:** `cost/memory_die_price_snapshot.csv; results/power_cost/README.md` (보조 분석)
- **주의할 해석:** 구매 가능한 다이 가격이라고 말하지 않는다.

## Q66. 가격 조사 시점 자료의 한계는?

- **짧은 답:** 시점·수량·유통사에 따라 변한다.
- **상세 답:** 2026-07-31 수량 1개 기준 Mouser/DigiKey 조사 자료이므로 조달 전 갱신해야 한다.
- **근거:** `cost/memory_die_price_snapshot.csv`
- **주의할 해석:** 현재 최저가나 양산가로 보장하지 않는다.

## Q67. 왜 K26 로컬 DDR4만 쓰지 않는가?

- **짧은 답:** 아직 외부 메모리 채택이 확정되지 않았다.
- **상세 답:** 먼저 로컬 유효 대역폭·경합·전력 기준선을 측정해 외부 채널 분리 이득과 비교해야 한다.
- **근거:** `paper/final/submission_manuscript.md — “III. 온디바이스 가속기의 설계 목표”, “VIII. 결과와 시스템 설계 결정”`
- **주의할 해석:** 로컬 DDR4가 부족하다고 단정하지 않는다.

## Q68. 왜 Gemma 1B가 4 GB에 들어가는데 외부 8 GB인가?

- **짧은 답:** 용량 외의 대역폭·분리 가설을 검증하기 위한 후보이기 때문이다.
- **상세 답:** 문맥 32K의 INT8 용량 2.4301 GiB는 명목 4 GB 안에 들어가므로 용량 논거는 기각된다.
- **근거:** `paper/final/submission_manuscript.md — “III. 온디바이스 가속기의 설계 목표”, “X. 논의와 한계”`
- **주의할 해석:** 8 GB가 필수라고 말하지 않는다.

## Q69. 3B 모델을 실행했는가?

- **짧은 답:** 아니다.
- **상세 답:** 3B는 일반 용량·모델 분석일 뿐 실제 종단 간 실행 증거가 없다.
- **근거:** `docs/evidence.md; paper/final/submission_manuscript.md — “X. 논의와 한계”`
- **주의할 해석:** 용량 적합을 실행 성공으로 바꾸지 않는다.

## Q70. 외부 8 GiB 후보의 물리 구성은?

- **짧은 답:** 분석에서는 네 채널×2 GiB 후보로만 놓았다.
- **상세 답:** 채널당 8 Gb×8 패키지 두 개라는 산술 후보를 사용했지만, 최종 메모리 밀도·랭크·부품 번호·전원·네 개 MIG 구성은 결정하거나 구현하지 않았다.
- **근거:** `paper/final/submission_manuscript.md — “IV. K26–Memory FPGA 시스템 구조”; results/capacity/README.md; hardware/kicad/k26_memory_reference/03_DDR3L_Four_Channel_Topology.kicad_sch`
- **주의할 해석:** 배선 완료 보드 구성으로 말하지 않는다.

## Q71. KiCad 원본은 실제 객체인가?

- **짧은 답:** 그렇다.
- **상세 답:** 텍스트 그림만이 아니라 실제 회로도·PCB 원본과 렌더가 있다.
- **근거:** `hardware/kicad; paper/final/figures/paper_f07_kicad_coupon_render.png`
- **주의할 해석:** 실제 원본이 곧 제작 준비를 뜻하지 않는다.

## Q72. ERC란?

- **짧은 답:** 회로도 전기 규칙 검사다.
- **상세 답:** 핀 유형, 연결과 선언 규칙을 검사하지만 SI/PI나 실동작은 보장하지 않는다.
- **근거:** `scripts/verify_k26_kicad.py`
- **주의할 해석:** ERC 통과를 기능 검증으로 부르지 않는다.

## Q73. DRC란?

- **짧은 답:** PCB 배선 규칙 검사다.
- **상세 답:** 간격·폭 등 설정 규칙을 검사하지만 미배선과 제조·신호 무결성 전체를 대신하지 않는다.
- **근거:** `scripts/verify_k26_kicad.py`
- **주의할 해석:** 제한 DRC를 제작 승인으로 부르지 않는다.

## Q74. PCB는 제작 준비 완료인가?

- **짧은 답:** 아니다.
- **상세 답:** 미배선 신호망 55개와 SI/PI/PDN, 열, EMC 및 FPGA 제약 관문이 남았다.
- **근거:** `paper/final/submission_manuscript.md — “IX. PCB 인터페이스 라우팅 쿠폰”; study/08_kicad_and_physical_scope.md`
- **주의할 해석:** 제작을 권장하지 않는다.

## Q75. KiCad 쿠폰이 증명하는 것은?

- **짧은 답:** 실제 원본과 범위가 제한된 규칙 검사 가능성이다.
- **상세 답:** 물리 제안의 형태와 일부 규칙을 검증하지만 닫힌 하드웨어 데이터 경로는 아니다.
- **근거:** `docs/evidence.md`
- **주의할 해석:** 완성 보드 기능으로 확대하지 않는다.

## Q76. 55 미배선 신호망의 의미는?

- **짧은 답:** 아직 물리 연결이 완결되지 않았다는 제작 차단 조건이다.
- **상세 답:** 배선, 길이 정합과 후속 DRC가 필요하다.
- **근거:** `paper/final/submission_manuscript.md — “IX. PCB 인터페이스 라우팅 쿠폰”`
- **주의할 해석:** 단순 시각적 경고로 축소하지 않는다.

## Q77. SI/PI/PDN은 각각 무엇인가?

- **짧은 답:** 신호 무결성, 전원 무결성, 전력 분배망이다.
- **상세 답:** 고속 신호 품질과 전원 안정성을 해석·측정하는 물리 검증 단계다.
- **근거:** `study/08_kicad_and_physical_scope.md`
- **주의할 해석:** ERC/DRC가 대신한다고 말하지 않는다.

## Q78. 다음 물리 검증 순서는?

- **짧은 답:** 배선→규칙 검사→SI/PI/PDN→FPGA 타이밍→제작→초기 구동→계측 순서다.
- **상세 답:** 각 단계의 통과 기준을 만족한 뒤 다음으로 간다.
- **근거:** `study/08_kicad_and_physical_scope.md`
- **주의할 해석:** 검증 전 제작을 먼저 권하지 않는다.

## Q79. 보드에서 가장 먼저 측정할 기준선은?

- **짧은 답:** K26 로컬 메모리에서 동일 부하의 대역폭·꼬리 지연·전력을 측정한다.
- **상세 답:** 분석 민감도 기준선은 이미 만들었지만, 외부 메모리 후보와 같은 추적·정확성 조건의 보드 측정이 있어야 채택 여부를 결정할 수 있다.
- **근거:** `paper/final/submission_manuscript.md — “VIII. 결과와 시스템 설계 결정”, “X. 논의와 한계”`
- **주의할 해석:** 최고 사양만으로 기준선을 대신하지 않는다.

## Q80. 실제 링크 유효 대역폭을 아는가?

- **짧은 답:** 아니다.
- **상세 답:** 논리 RTL 데이터 흐름은 닫혔지만 GTH 래퍼, 패킷, 크레딧/클록 도메인 교차, MIG와 보드 계측이 없으므로 물리 링크 유효 대역폭은 알 수 없다.
- **근거:** `docs/architecture.md`
- **주의할 해석:** 4레인 후보를 측정 대역폭으로 바꾸지 않는다.

## Q81. 제작 후 성공 기준은?

- **짧은 답:** 정확성, 정확히 한 번 처리, 타이밍, 대역폭, 꼬리 지연, 보정 전력이다.
- **상세 답:** 로컬 기준선과 동일 부하에서 결과 해시·ID 집합과 물리 계측을 함께 확인한다.
- **근거:** `study/11_whiteboard_explanations.md`
- **주의할 해석:** 부팅 또는 링크 고정만으로 성공이라 하지 않는다.

## Q82. 모델 가중치 없이 어떻게 재현하는가?

- **짧은 답:** 공개 합성 부하·시험 입력과 목록에 고정된 경로를 재현한다.
- **상세 답:** 전체 그래프 추적은 사용자가 적법한 로컬 자료를 제공할 때만 해시를 검증해 생성한다.
- **근거:** `models/ACQUISITION.md; Makefile`
- **주의할 해석:** 가중치가 릴리스에 포함됐다고 말하지 않는다.

## Q83. 공식 소스 ZIP과 GitHub 자동 ZIP 차이는?

- **짧은 답:** 공식 ZIP은 소스 목록을 포함하고 자동 ZIP은 대체 파일 트리 검사를 쓴다.
- **상세 답:** 둘 다 시험·출판 인덱스의 기본 동작을 확인할 수 있지만 체크섬 기반 재현은 공식 압축 파일이 기준이다.
- **근거:** `README.md; scripts/test_source_archive.py`
- **주의할 해석:** 자동 ZIP에 목록이 있다고 가정하지 않는다.

## Q84. 재현 명령이 깨끗한 작업 트리를 요구하는 이유는?

- **짧은 답:** 생성이 추적 파일을 바꾸지 않는지 확인하기 위해서다.
- **상세 답:** Git 모드에서는 변경 내역과 작업 트리 상태, 압축 파일 모드에서는 목록·체크섬으로 오염을 검사한다.
- **근거:** `scripts/verify_clean_source.py; Makefile`
- **주의할 해석:** 단순 명령 성공만 재현 가능이라 부르지 않는다.

## Q85. 근거를 답변마다 붙이는 이유는?

- **짧은 답:** 청중이 주장을 원본까지 추적할 수 있게 하기 위해서다.
- **상세 답:** 수치, 그림, 스크립트와 원본 표를 연결하면 기억 오류와 과장을 줄인다.
- **근거:** `release/evidence_index.md`
- **주의할 해석:** 포인터 없는 수치를 새 결과처럼 말하지 않는다.

## Q86. 가장 위험한 발표 실수는?

- **짧은 답:** 분석 수치를 보드 실측처럼 말하는 것이다.
- **상세 답:** 항상 증거 유형과 제외 범위를 수치 앞뒤에 붙인다.
- **근거:** `study/09_claim_boundary.md`
- **주의할 해석:** ‘성능이 향상됐다’만 단독으로 말하지 않는다.

## Q87. 질문에 답을 모를 때 어떻게 하는가?

- **짧은 답:** 현재 증거로 결정 불가라고 말하고 다음 관문을 제시한다.
- **상세 답:** 필요한 실험, 입력, 지표와 통과 기준을 구체적으로 답한다.
- **근거:** `study/12_interview_script.md`
- **주의할 해석:** 추정값을 즉석 실측처럼 만들지 않는다.

## Q88. 이 연구 자료의 가장 강한 주장과 가장 약한 주장은?

- **짧은 답:** 가장 강한 것은 범위가 고정된 출처·RTL 기능, 가장 약한 것은 물리 성능 추정이다.
- **상세 답:** 그래프 해시와 결과 일치는 직접 확인·RTL 시뮬레이션 증거지만 에너지와 혼합 구조 지연은 가정 의존적이다.
- **근거:** `docs/evidence.md`
- **주의할 해석:** 모든 결과를 같은 신뢰도로 표현하지 않는다.

## Q89. 90초 발표의 마지막 문장은?

- **짧은 답:** 이번 민감도에서는 Gemma 1B는 K26 로컬을 우선하고, 외부 구조는 실제 경합과 확장 요구가 확인될 때 채택한다는 것이다.
- **상세 답:** 계산·메모리 역할 분리, 이동 비용을 포함한 동적 배치, 모델→RTL→KiCad 재현 흐름을 기여로 정리하고 K26 로컬 실측과 GTH/MIG 물리 폐루프를 다음 단계로 제시한다.
- **근거:** `presentation/final/outline.md`, 슬라이드 14
- **주의할 해석:** 완제품 출시 약속으로 끝내지 않는다.

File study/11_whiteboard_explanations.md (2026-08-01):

# 화이트보드 설명

## 전체 구조 — 90초

왼쪽에 K26의 네 작업대, 오른쪽에 네 출고 창구를 가진 Memory FPGA를 그린다.
TileJob이 계산 위치와 가중치 위치를 연결한다. 1B는 K26 로컬 우선이고 외부는
확장 조건의 후보다.

## Work Stealing — 60초

한 작업대의 줄이 길고 옆 작업대가 빈 그림을 그린다. S2는 가장 오래된 일을 가져오고
S3는 기다린 이득에서 부품 운반 비용을 뺀다. 양수일 때만 ownership을 옮긴다.

## 실제 모델 매핑 — 60초

7,837→183→802를 쓰고 qkv→o→MLP→다음 계층 장벽을 그린다. 다음 토큰은 lm_head
뒤에 열린다. p95는 이 TileJob 분포이지 사용자 요청 시간이 아니다.

## 논리 RTL과 물리 경계 — 60초

DMA 요청→응답 경계→논리 FIFO→MatVec을 실선으로, GTH/MIG/보드 타이밍을 점선으로
그린다. 대표 타일 3개 결과는 맞지만 물리 대역폭은 아직 모른다.

## 다음 검증 — 45초

K26 로컬 실측→GTH/CDC/패킷→MIG 한 채널→전체 보드 전력·비용 순서로 닫는다.

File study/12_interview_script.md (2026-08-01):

# 면접·심사 답변 스크립트

## 20초 소개

“K26이 연산하고 외부 Memory FPGA가 가중치를 공급하는 확장 후보 구조를 설계했습니다.
Gemma 실제 형상을 의존성 있는 TileJob으로 바꾸고, 데이터 이동 비용을 포함해
Work Stealing이 유효한 조건을 분석했습니다. Gemma 1B는 K26 로컬 우선이며,
외부 구조는 더 큰 모델과 실제 로컬 경합에서 다시 평가합니다.”

## 수치 답변 공식

“이 값은 **[분석 모델/RTL 시뮬레이션/직접 확인]**에서 **[조건]**으로 얻었습니다.
비교 기준은 **[S1/S2/K26 로컬]**이고, **[보드 실측·사용자 요청 지연 등 제외 범위]**로
확대하지 않습니다.”

## 모르는 질문

“현재 자료로는 결정할 수 없습니다. 다음 실험은 [구체 경로/측정]이고 통과 기준은
[정확성·타이밍·대역폭·전력]입니다.”

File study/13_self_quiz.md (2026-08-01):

# 셀프 퀴즈

1. 왜 1B가 4GB에 들어가는데 외부 8GB를 연구했는가?
2. 이 연구의 시스템 중심 기여 세 가지는 무엇인가?
3. 토큰당 183개 투영이 802개 TileJob이 되는 이유는?
4. 단계·토큰 의존성을 어떻게 보존했는가?
5. 네 초기 배치가 필요한 이유는?
6. S1, S2, S3의 차이는?
7. 원격 복사 비용은 완료시간에 어떻게 들어가는가?
8. 합성 편향 부하의 p95/p99 결과는?
9. Gemma 기존 산술 배치와 채널 친화 배치 결과는 왜 다른가?
10. TileJob p95를 사용자 요청 지연이라 부르면 왜 안 되는가?
11. 폐루프 논리 RTL과 열린 물리 경로를 그려라.
12. KiCad 쿠폰이 전체 보드가 아닌 근거는?
13. K26 로컬과 외부 후보의 다음 실측은 무엇인가?
14. 저비용·저전력 달성을 왜 아직 주장하지 않는가?

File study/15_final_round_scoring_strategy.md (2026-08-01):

# 본선 심사 A등급 대응 전략

사용자가 제공한 한국정보기술진흥원 기준 화면을 발표 준비 Gate로 옮겼다. 1차 평가점수는
최종 점수에 35% 반영되며, 본선 항목은 주제 이해도 30점, 전달성 10점,
질의응답 20점, 참여도 5점이다.

등급별 점수는 주제 이해도 30/25/20/15/10점, 전달성 10/9/8/7/6점,
질의응답 20/16/12/8/4점, 참여도 5/4/3/2/1점이다. 참여도는 접속 시간 비율로
A 80% 이상, B 60% 이상, C 40% 이상, D 20% 이상, E 20% 미만이다.

## 1. 주제 이해도 30점

A등급 목표 답변은 다음 네 문장을 끊김 없이 연결한다.

1. 문제: Gemma 3 1B는 K26 4 GB에 들어가지만 정적 작업 배치와 가중치 공급 경합은 남는다.
2. 구조: K26은 계산·제어, Memory FPGA 후보는 다채널 가중치 공급을 맡는다.
3. 결과: S3는 불균형이 이동 비용보다 큰 조건에서 꼬리 지연을 줄이며, 배치가 이미 균형이면 이득이 없다.
4. 결정: 이번 민감도에서는 K26 로컬을 우선하고 외부 후보는 더 큰 모델·긴 문맥·실측 경합에서 재평가한다.

슬라이드 3, 4, 10, 12, 14의 기억 문장을 보지 않고 말할 수 있어야 한다. 숫자를
외우는 것보다 왜 질문이 바뀌었고 왜 구조 채택을 보류했는지를 설명한다.

## 2. 전달성 10점

- 화면의 문장을 읽지 않는다. 제목→큰 Figure→핵심 수치 순으로 가리킨다.
- 한 슬라이드의 결론은 한 문장으로 끝낸다.
- 시간 점검은 Slide 4 끝 2:25, Slide 8 끝 5:15, Slide 11 끝 7:40,
  Slide 13 끝 9:10이다.
- 10초 늦으면 Slide 5의 세 타일 세부 사이클을 생략한다.
- 20초 늦으면 Slide 13의 배선 개수 설명을 생략하되 `NOT FOR FABRICATION`은 남긴다.
- 마지막 30초에는 세 기여, 한계, QR, 질문 전환을 반드시 말한다.

## 3. 질의응답 20점

### 25초 답변 공식

1. 결론 한 문장
2. 근거 유형과 핵심 수치 하나
3. 허용되지 않는 확대 해석
4. 필요하면 다음 검증 한 문장

예: “S3는 항상 빠르지 않습니다. 분석 모델의 합성 편향 부하에서는 S1 대비
TileJob p95가 19.13% 줄었지만, Gemma 기존 배치에서는 0.28% 늘었습니다.
이는 사용자 요청 지연이나 보드 실측이 아닙니다. 실제 채택 전에는 K26 로컬과
같은 작업으로 보드에서 대역폭·전력·꼬리 지연을 측정해야 합니다.”

### 먼저 외울 12문항

| 우선 | 질문 | Q&A 원문 |
|---:|---|---:|
| 1 | 핵심 기여 세 가지는? | Q03 |
| 2 | 완성된 가속기인가? | Q04 |
| 3 | 실제 타일 3/3은 무엇을 증명하는가? | Q16 |
| 4 | 작업 훔치기가 RTL에 구현됐는가? | Q35 |
| 5 | S3가 항상 좋은가? | Q37–Q39 |
| 6 | p95와 완료시간은 어떻게 다른가? | Q41–Q43 |
| 7 | S1·S2 비교 기준이 왜 다른가? | Q50–Q53 |
| 8 | 실제 전력을 측정했는가? | Q61 |
| 9 | K26 로컬만 쓰지 않는 이유는? | Q67 |
| 10 | 1B가 4 GB에 들어가는데 왜 외부 8 GB인가? | Q68 |
| 11 | PCB는 제작 가능한가? | Q74–Q76 |
| 12 | 다음 물리 검증은 무엇인가? | Q78–Q81 |

모르는 질문에는 추측하지 않는다. “현재 자료로는 결정할 수 없습니다”라고 먼저
말하고 필요한 입력, 실험, 통과 지표를 구체적으로 답한다.

## 4. 참여도 5점과 추가 질문 점수

- 전체 세션의 80% 이상 접속 상태를 유지한다. 접속 이름과 네트워크를 시작 전에 확인한다.
- 발표가 끝나도 퇴장하지 않는다. 주최 측이 접속 시간으로 참여도를 확인할 수 있다.
- 다른 참가자의 발표에서 주장 하나와 근거 하나를 메모하고, 최소 한 번은 양질의 질문을 한다.
- 자기 연구를 홍보하는 질문이나 이미 답한 내용을 반복하는 질문은 피한다.

다른 발표에 사용할 수 있는 질문 예시는 다음과 같다.

1. “제시한 성능 향상에서 연산 개선과 메모리 전송 개선의 기여를 어떻게 분리하셨나요?”
2. “비교 기준의 자원량과 전력 조건을 동일하게 맞추기 위해 어떤 통제를 하셨나요?”
3. “현재 결과가 시뮬레이션이라면 실제 하드웨어에서 가장 먼저 확인할 실패 조건은 무엇인가요?”

## 5. 리허설 합격 조건

- 9분 20초 이상 9분 50초 이하로 두 번 연속 완주한다.
- 슬라이드 3·4·10·12·14의 기억 문장을 화면 없이 말한다.
- 위 12문항 중 무작위 8개를 문항당 25초 안에 답한다.
- 모든 수치에 분석 모델, RTL 시뮬레이션, 직접 확인 중 하나를 붙인다.
- 참여용 질문 세 개 중 하나를 상대 연구에 맞게 구체화한다.

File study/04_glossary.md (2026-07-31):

# 용어집

| 용어 | 뜻 |
|---|---|
| Prefill | 입력 문맥 전체를 병렬적으로 처리해 KV cache를 만드는 단계 |
| Decode | 이전 KV를 재사용하며 다음 토큰을 한 개씩 생성하는 단계 |
| Projection | attention/MLP의 선형변환; decode에서 가중치 재읽기 비중이 큼 |
| MatVec | 행렬과 벡터의 곱; 이 artifact는 signed INT8 16×4 primitive를 사용 |
| TileJob | 일부 K/N 범위와 주소·소유권·친화도를 가진 작업 단위 |
| FCFS | 도착 순서 우선 처리 |
| Work Stealing | 빈 worker가 다른 queue의 eligible job을 가져오는 정책 |
| Locality cost | 원격 weight/activation/reduction/bundle mismatch의 모델 비용 |
| p95/p99 | 지연 표본의 95/99 백분위; tail을 나타냄 |
| Compute duty | 실제 compute cycle 비율 |
| Reservation occupancy | dispatch 후 대기까지 포함한 cluster 예약 비율 |
| Backpressure | downstream이 받을 수 없어 upstream 전송을 늦추는 흐름 제어 |
| CDC | 서로 다른 clock domain 사이의 안전한 신호 전달 |
| DDR channel/bank/row | 독립 채널, 내부 병렬 bank, bank 안의 row 주소 계층 |
| DRAMsim3 | DRAM timing simulator; 본 repo의 snapshot은 replay와 결합되지 않음 |
| SpinalHDL | Scala 기반 하드웨어 기술 언어 |
| Verilator | HDL을 C++ 모델로 변환해 시뮬레이션하는 도구 |
| ERC/DRC | 전기 규칙/배선 규칙 검사; 제작 가능성 전체를 보장하지 않음 |

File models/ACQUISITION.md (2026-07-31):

# Gemma 3 1B acquisition and local verification

The trace generator is deliberately fail-closed. It does not download a model,
extract the two local ZIP files, copy weights into Git, or modify the source
artifact.

## Authorized acquisition

1. Review and accept the applicable Gemma terms at an authorized Google,
   Kaggle, or Hugging Face distribution point.
2. Obtain or export a Gemma 3 1B ONNX artifact with external data through your
   own authenticated process.
3. Keep the artifact outside this repository.
4. Set `GEMMA3_1B_ONNX_DIR` to the directory containing all files listed below.
5. Run the generator; it validates completeness and records new SHA-256 values.

Required local files:

```text
model.onnx
model.onnx_data
config.json
tokenizer.json
tokenizer_config.json
special_tokens_map.json
generation_config.json
chat_template.jinja
```

Command used for this evidence snapshot:

```bash
python3 experiments/gemma3_1b/generate_trace.py \
  --model-dir ${GEMMA3_1B_ONNX_DIR}
```

On another machine:

```bash
export GEMMA3_1B_ONNX_DIR=/authorized/read-only/path/gemma3-1B-onnx
python3 experiments/gemma3_1b/generate_trace.py
```

If the path or any required file is absent, the command exits with status 2 and
prints `BLOCKED`. It never substitutes synthetic graph rows or guessed token
IDs. Different hashes mean a different artifact and require a new evidence
review; they are not silently accepted as equivalent.

## Provenance limitation

The inspected artifact existed before this work. Its original acquisition
transaction, exporter command/revision, and accepted-license receipt are not
available in the workspace. The graph itself, configuration, tokenizer, file
sizes, and hashes are directly inspectable; the missing acquisition chain
remains an explicit provenance blocker for public redistribution.

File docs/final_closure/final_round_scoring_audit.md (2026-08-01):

# 본선 심사 기준 반영 감사표

기준 출처: 사용자가 2026-08-01 제공한 한국정보기술진흥원 본선 심사 기준 화면.

| 기준 | A | B | C | D | E |
|---|---:|---:|---:|---:|---:|
| 주제 이해도 | 30 | 25 | 20 | 15 | 10 |
| 전달성 | 10 | 9 | 8 | 7 | 6 |
| 질의응답 | 20 | 16 | 12 | 8 | 4 |
| 참여도 | 5 | 4 | 3 | 2 | 1 |

참여도 등급은 접속 시간 비율로 A 80% 이상, B 60% 이상, C 40% 이상,
D 20% 이상, E 20% 미만이다. 심사위원 질문에 대한 응답과 다른 참가자에 대한
양질의 질문은 총점 한도 안에서 추가 점수를 받을 수 있다.

| 항목 | A등급 | 대응 산출물 | 검증 |
|---|---:|---|---|
| 1차 평가점수 | 35% 반영 | 기존 1차 결과는 외부 입력으로 유지 | 발표 산출물에서 임의 환산하지 않음 |
| 주제 이해도 | 30점 | 논문 서사, 16장 발표, 슬라이드별 기억 문장·예상 질문 | 필요성→구조→검증→채택 조건 연결 |
| 전달성 | 10점 | 9:50 스크립트, 그림 설명 순서, 전환문, 시간 점검점 | 16장·한 장 한 메시지·낭독 추정 9:20–9:50 Gate |
| 질의응답 | 20점 | 89문항 Q&A, 25초 답변 공식, 우선 12문항 | 결론→근거→경계→다음 검증 구조 |
| 참여도 | 5점 | 80% 이상 접속·타 발표 질문 전략 | 당일 접속 시간은 발표자가 직접 충족해야 함 |

## 점수와 연구 내용의 연결

주제 이해도는 수치 암기가 아니라 다음 판단 사슬로 평가한다.

`1B 용량 가설 수정 → 역할 분리 후보 구조 → 논리 RTL과 분석 모델 → 조건부 S3 효과 → K26 로컬 우선 결정`

질의응답은 현재 구현, 모델 결과, 물리 미검증 범위를 섞지 않는 것을 최우선으로
한다. 전달성은 Figure를 가리키는 순서와 시간 점검점을 발표자 노트에 넣어 재현한다.
참여도는 산출물로 대신 증명할 수 없으므로 80% 이상 접속과 타 발표에 대한 양질의
질문을 당일 행동 Gate로 남긴다.

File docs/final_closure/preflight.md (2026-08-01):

# 최종 마감 사전점검

점검일: 2026-08-01
저장소: `https://github.com/snowman0919/varp-k26-memory-fpga`
작업 브랜치: `conference-final`

## 1. 저장소 상태

- 작업 경로: `/home/monad/develop/workbench/varp-k26-memory-fpga`
- 공개 범위: GitHub public repository
- 기본 브랜치: `main`
- 점검 시작 브랜치: `repo-presentation-finalization`
- 현재 작업 브랜치: `conference-final` (`origin/main`에서 분기)
- 점검 시작 시 미커밋 변경: 없음
- 최근 기준 커밋:
  - `be02e39` Remove failing public artifact workflow
  - `d053c4f` remove failing public artifact workflow
  - `f1bab6c` Merge pull request #1 from snowman0919/repo-presentation-finalization
  - `8eaefa1` refresh submission release archives
  - `4dafc83` finalize research-first conference presentation

## 2. 민감정보 점검

### GitHub

- 2026-08-01 재조회에서 열린 secret-scanning 경고 1건을 확인했다.
- 유형은 HashiCorp Vault service token이며, 위치는 과거 커밋
  `730a05b`의 `presentation/final/presentation.pdf`다.
- GitHub는 이 경고를 `publicly_leaked=true`, `validity=unknown`으로 표시한다.
- 현재 작업 트리, 현재 PDF/PPTX, 기존 두 GitHub Release의 중첩 문서를 다시
  검사했으며 같은 고신뢰 패턴은 검출되지 않았다.
- 개인키 헤더 `BEGIN ... PRIVATE KEY`: 현재 파일에서 0건.

### 로컬 산출물

다음을 재귀적으로 검사했다.

- `paper/final/submission_manuscript.pdf`
- `presentation/final/presentation.pptx`
- `presentation/final/presentation.pdf`
- `release/*.zip` 및 ZIP 내부의 중첩 PPTX·문서

고신뢰 자격증명 패턴 검출 결과: 0건.

일반 키워드 `token`, `secret`, `api_key`, `password`, `vault`는 연구 문서와 코드의 토큰 용어 또는 보안 설명 때문에 별도로 분류했다. 실제 자격증명 할당으로 확인된 항목은 없다.

### 도구 가용성

- `gitleaks`: 설치되지 않음.
- `trufflehog`: 설치되지 않음.
- 대체 검사: GitHub secret-scanning API, 전체 Git 이력 패턴 검사, 현재 파일 검사, PDF/PPTX/release ZIP 재귀 검사.

후속 판정: 2026-08-01 09:32 KST에 저장소 소유자 `snowman0919`가 경보 #1을
`false_positive`로 해소했다. 해결 코멘트는 없고 GitHub validity는 `unknown`이지만,
소유자가 실제 비밀이 아니라는 분류를 명시했고 현재 작업 트리·PDF/PPTX·중첩
Release 자산 949개에서도 같은 고신뢰 패턴이 0건이었다. 따라서 force push 없이
보안 Gate를 해제하고 새 공개 Release를 진행한다. 경보에 표시됐던 문자열 자체는
문서나 로그에 기록하지 않는다.

## 3. 핵심 산출물 현황

| 산출물 | 현재 상태 |
|---|---|
| 논문 Markdown/PDF | 존재, PDF 12쪽 |
| 발표 PPTX/PDF | 존재, 16:9 10장 |
| 발표자 노트 | 존재 |
| 학습자료 PDF | 존재, 29쪽 |
| README/CITATION/Makefile | 존재 |
| KiCad | 완성 보드가 아닌 제한된 라우팅 검증 coupon |

## 4. 즉시 확인된 마감 결손

1. 발표자료가 목표 권장 13–16장이 아니라 10장이고 목차가 없다.
2. 현재 KiCad PCB는 K26와 XC7K160T를 실제 부품이 아닌 Samtec 경계 커넥터로 대체했다.
3. 대표 DDR3L x16 한 개만 배치되어 있으며 4채널·8개 package 물리 구현이 아니다.
4. `release/*.zip` 다섯 개가 `main`에 추적돼 있어 목표의 release/main 분리 조건과 충돌한다.
5. 대형 MP4/GIF가 `main`에 다수 추적돼 있다.
6. 논문은 영어 혼용과 방어적 증거 설명이 많아 독립적인 하드웨어 설계 논문으로 재편집해야 한다.
7. 최소 5회 독립 비평과 `paper/revisions/v10.1`–`v10-final` 보존이 아직 증명되지 않는다.
8. 최종 목표가 요구하는 `v10-conference-final` tag/release가 없다.

이 문서는 사전점검 기록이며, 위 결손이 해결되기 전에는 conference-ready 완료로 판정하지 않는다.

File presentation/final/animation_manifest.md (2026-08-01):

# 발표 시각자료 Manifest

모든 애니메이션은 Manim으로 생성했으며 수치 장면은 저장된 CSV를 직접 읽는다. 보드 실측 타이밍을 표현하지 않는다.

| 순서 | Asset | 역할 | 근거 |
|---:|---|---|---|
| 1 | `tile_dataflow.mp4/.gif` | 실제 타일의 폐루프 논리 경로 | `gemma3_1b_closed_loop_trace.csv`와 RTL 구조 |
| 2 | `work_stealing_sequence.mp4/.gif` | 대기 이득−이동 비용 선택 과정 | `k26_scheduler_model.py` |
| 3 | `scheduler_timeline.mp4/.gif` | 동일 작업·시드의 S1/S3 사건 비교 | `s1_s3_timeline_events.csv` |
| 4 | `tail_latency_results.mp4/.gif` | 합성 부하와 Gemma 배치 민감도 | `paired_policy_effects.csv`; `gemma3_1b_policy_effects.csv` |
| 5 | `bottleneck_migration.mp4/.gif` | p95·비지역 가중치·완료시간 절충 | `paired_policy_effects.csv` |

`presentation.mp4`와 `presentation.gif`는 위 장면을 연결한 무음 시각 요약이다. 9분 50초 구두 설명은 `speaker_notes.md`를 따른다.

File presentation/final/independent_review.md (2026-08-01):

# Independent Presentation Review

검토 대상은 최신 `presentation.pptx`, `presentation.pdf`, 16개 원본 크기 PNG,
contact sheet, speaker notes, slide source index와 해당 CSV/RTL/KiCad 원본이다.

| 독립 역할 | 최종 판정 | 확인 범위 |
|---|---|---|
| 기술 컨퍼런스 발표자 | PASS | 14번 한계→향후 탐구, 15번 3줄 결론, 16번 Q&A의 25초·25초·15초 종결 흐름과 노트 전용 Q&A 참고자료 |
| 한국어 가독성 검토자 | PASS | 14~16번의 3초 이해, 글자 겹침·잘림·오버플로우 0건, 화면상 상세 Q&A 미노출 |
| 하드웨어 연구자 | PASS | K26 기준선→물리 폐루프→SI/PI·전력·동일 Gemma 재평가 관문, 분석 모델·민감도 qualifier, 제작·실측 과장 방지 |

하드웨어 검토에서 발견한 두 위험은 최종본에 반영했다. Slide 14는 `SI/PI·전력
검증 + 동일 Gemma 재평가`를 독립 관문으로 표시하고, Slide 15는 `분석 모델에서`와
`이번 민감도에서`를 화면에 직접 넣어 보드 실측·보편 결론으로 읽히지 않게 했다.

자동 Gate는 다음을 확인한다.

- 16 slides, 16:9, 목표 590초, 낭독 추정 578.0초
- 16개의 speaker-note 기억 문장·그림 순서·예상 질문·답변 핵심·해석 경계
- 16-page PDF와 16개의 1920×1080 PNG
- 캔버스 밖 객체·텍스트 overflow·지원하지 않는 글리프 0건, 최소 12 pt
- 내장 Manim 영상 4개, 편집 가능한 텍스트·도형 중심 구성
- Slide 16의 화면 텍스트를 `Q&A`, `질문 받겠습니다`, `감사합니다`로 제한

실행 명령:

```bash
python presentation/tools/validate_editable_deck.py
```

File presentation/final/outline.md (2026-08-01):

# 온디바이스 sLLM을 위한 K26–Memory FPGA 후보 구조 평가

형식: 16:9 · 16장 · 목표 9:50 · 한국어 기술 컨퍼런스 발표

중심 문장: K26 계산부와 Memory FPGA 가중치 공급부의 후보 구조를 평가하고, 작업 훔치기(Work Stealing)는 남은 부하 불균형의 이득이 이동 비용보다 클 때만 사용하는 수단으로 둔다.

## 구성

1. 온디바이스 sLLM을 위한 K26–Memory FPGA 후보 구조 평가 — 0:25 · Gemma 3 1B 작업 부하에서 구조·배치·이동 비용의 채택 조건을 분석한다.
2. 오늘 답할 네 가지 질문 — 0:25 · 필요성→구조→검증→채택 조건의 순서로 연구 질문에 답한다.
3. 1B는 4GB에 들어갔다—연구 질문을 바꿨다 — 0:45 · 외부 8GB의 가치는 용량보다 가중치 공급 분리와 유휴 연산 감소에서 검증해야 한다.
4. 계산은 K26, 공급은 Memory FPGA 후보 — 0:45 · TileJob이 네 연산 클러스터와 네 DDR3L 채널·논리 링크의 위치를 함께 추적한다.
5. 실제 가중치 타일이 논리 폐루프 RTL을 통과했다 — 0:40 · DMA 응답 뒤에 MatVec이 실행되고 세 결과가 INT32 기준과 일치했다.
6. 정적 로컬 큐는 지역성을 지키지만 작업대를 놀린다 — 0:40 · 한 큐가 길어지면 다른 클러스터가 비어 있어도 꼬리 작업은 기다린다.
7. 이득이 이동 비용보다 클 때만 훔친다 — 0:40 · 대기 감소가 가중치·활성값·부분합 이동 비용보다 큰 작업만 옮긴다.
8. Gemma 그래프를 의존성 있는 802개 TileJob으로 변환 — 0:45 · 초기 배치와 나중 재분배의 효과를 분리한다.
9. 동일 작업·동일 시드에서 S1과 S3만 바꿨다 — 0:45 · S1의 유휴·대기 구간이 S3에서는 원격 준비와 연산 구간으로 바뀐다.
10. 효과는 부하 불균형과 초기 배치에 조건부 — 0:45 · 편향 부하에서는 줄지만 Gemma의 기존 산술 배치에서는 오히려 늘 수 있다.
11. 작업 훔치기는 병목을 없애지 않고 이동시킨다 — 0:40 · 큐 대기는 줄지만 원격 복사와 링크·메모리 서비스가 새 비용이 된다.
12. 이번 민감도에서는 K26 로컬이 우선이다 — 0:45 · 시험한 대역폭 범위에서 외부 4채널 후보는 K26 로컬 완료시간을 이기지 못했다.
13. KiCad 결과는 참조 라우팅 쿠폰이다 — 0:45 · 실제 KiCad 객체와 일부 배선은 만들었지만 전체 제품 보드나 제작 자료는 아니다.
14. 한계와 향후 탐구 방향 — 0:25 · 현재의 미구현 경계를 다음 세 측정 관문으로 바꾼다.
15. 결론 및 기여 — 0:25 · 이 연구의 결론은 세 문장으로 압축된다.
16. Q&A — 0:15 · 질문 받겠습니다.

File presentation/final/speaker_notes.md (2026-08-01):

# VARP v11 — 9분 50초 발표자 노트

총 목표 시간: 9:50

## 본선 심사 기준 대응

- 주제 이해도 30점: 모든 답을 필요성→구조→검증→채택 조건으로 연결한다.
- 전달성 10점: 한 슬라이드 한 문장, 그림은 아래 순서대로 가리키며 읽지 말고 설명한다.
- 질의응답 20점: 결론 한 문장→근거 유형·수치→해석 경계→다음 검증 순서로 25초 안에 답한다.
- 참여도 5점: 전체 세션의 80% 이상 접속하고 다른 발표에 근거 있는 질문을 준비한다.
- 시간 점검: Slide 4 끝 2:20 · Slide 8 끝 5:05 · Slide 11 끝 7:15 · Slide 14 끝 9:10 · Slide 15 끝 9:35.

## Slide 1: 온디바이스 sLLM을 위한 K26–Memory FPGA 후보 구조 평가 (0:25)

기억할 문장: 이 발표는 완성 제품이 아니라 K26–Memory FPGA 후보 구조의 설계 공간 평가입니다.

발화문: 온디바이스 sLLM에서 가중치를 어디에 두고 어떻게 공급할지를 연구했습니다. K26이 연산과 제어를 맡고 외부 Memory FPGA가 다채널 가중치 공급을 맡는 후보 구조를 만들고, 작업 훔치기(Work Stealing)가 유휴 연산을 줄이는 조건과 그때 생기는 데이터 이동 비용을 함께 분석했습니다. 중심 질문은 어떤 배치와 부하에서 공급 분리의 이득이 이동 비용을 넘어서는가입니다.

그림 설명 순서: 온디바이스 제약 → K26/Memory FPGA 역할 → 채택 조건 질문

전환: 먼저 오늘 답할 질문을 보겠습니다.

예상 질문: 이 연구의 핵심 기여를 한 문장으로 말하면 무엇인가?

답변 핵심: 계산·공급 역할 분리, 이동 비용을 포함한 동적 배치, 모델→RTL→KiCad 재현 흐름이 세 기여입니다.

해석 경계: 후보 구조·분석 결과이며 제작 완료 가속기를 뜻하지 않습니다.

주의할 표현: 완성 제품·실측 가속기라고 말하지 않는다.

## Slide 2: 오늘 답할 네 가지 질문 (0:25)

기억할 문장: 발표는 왜 검토했는지, 무엇을 설계했는지, 무엇을 확인했는지, 언제 채택할지의 순서입니다.

발화문: 첫째 외부 메모리 구조를 왜 검토했는가, 둘째 계산부와 가중치 공급부를 어떻게 나눴는가, 셋째 실제 Gemma 작업에서 무엇을 검증했는가, 마지막으로 어떤 조건에서 구조와 작업 훔치기가 유효한가를 답하겠습니다.

그림 설명 순서: 필요성 → 구조 → 검증 → 채택 조건의 네 번호

전환: 출발점은 예상과 달랐던 용량 계산입니다.

예상 질문: 왜 이 네 질문 순서로 발표하는가?

답변 핵심: 필요성에서 시작해 구조와 검증을 거친 뒤 채택 조건으로 끝내야 결과가 설계 결정으로 연결됩니다.

해석 경계: 세부 조건은 발표자 노트와 출처 인덱스에 있습니다.

주의할 표현: 목차를 결과처럼 설명하지 않는다.

## Slide 3: 1B는 4GB에 들어갔다—연구 질문을 바꿨다 (0:45)

기억할 문장: Gemma 1B의 2.43 GiB가 K26 4GB 안에 들어가므로 외부 메모리는 기본 요구가 아니라 조건부 후보입니다.

발화문: INT8 가중치와 문맥 32K, 실행 여유를 합치면 약 2.43 GiB였습니다. 그래서 외부 8GB가 필요하다는 최초 가설을 버리고, 가중치 공급을 분리해 네 클러스터의 유휴를 줄이는 이득이 데이터 이동 비용보다 큰가로 질문을 바꿨습니다. 2.43 GiB에는 INT8 가중치, 문맥 32K의 KV, 실행 여유가 포함됩니다. 명목 용량에 들어간다는 사실만으로 실제 대역폭과 지연이 충분하다고 결론 내리지는 않습니다.

그림 설명 순서: 처음 가설 → 2.43 GiB 용량 계산 → 새 연구 부등식

전환: 이 질문을 두 FPGA의 역할 분리로 구체화했습니다.

예상 질문: Gemma 1B가 4 GB에 들어가는데 왜 외부 8 GB를 검토했는가?

답변 핵심: 외부 8 GB는 1B의 필수 용량이 아니라 더 큰 모델·긴 문맥과 가중치 공급 분리를 위한 조건부 확장 후보입니다.

해석 경계: 2.43 GiB는 용량 모델이며 보드 실측이 아닙니다.

주의할 표현: 외부 8 GB가 Gemma 1B의 필수 용량이라고 말하지 않는다.

## Slide 4: 계산은 K26, 공급은 Memory FPGA 후보 (0:45)

기억할 문장: K26은 연산·제어를, Memory FPGA 후보는 네 채널의 가중치 공급을 맡습니다.

발화문: K26의 네 연산 클러스터와 로컬 큐가 TileJob을 실행합니다. 외부 후보는 네 DDR3L 채널과 네 논리 링크로 가중치를 공급합니다. TileJob의 선호 채널과 링크가 계산 위치와 데이터 위치를 연결합니다. 실선은 이번에 닫은 논리 경로, 점선 GTH·CDC·MIG는 후속 물리 경로입니다. 실선은 RTL에서 작업 ID와 데이터가 이어지는 논리 경로이고, 빨간 물리 경로는 아직 구현하지 않은 GTH 직렬화, 클록 도메인 교차, 패킷, MIG를 뜻합니다.

그림 설명 순서: K26 연산부 → 논리 링크 → Memory FPGA 공급부 → 미구현 물리 경로

전환: 실제 타일이 닫힌 논리 경로를 통과하는지 확인했습니다.

예상 질문: 현재 실제로 구현된 구간과 후보로 남은 구간은 어디인가?

답변 핵심: 작업 수락부터 논리 응답·링크 FIFO·MatVec 결과까지는 닫혔고 GTH·CDC·MIG 물리 경로는 남아 있습니다.

해석 경계: 4채널과 4링크는 후보 구조이며 물리 GTH/MIG는 미구현입니다.

주의할 표현: 논리 폐루프를 물리 GTH·MIG 폐루프로 확대하지 않는다.

## Slide 5: 실제 가중치 타일이 논리 폐루프 RTL을 통과했다 (0:40)

기억할 문장: 대표 Gemma 타일 세 개가 작업 수락부터 결과까지 닫힌 논리 경로를 통과했습니다.

발화문: 작업 수락, DMA 요청, 응답 경계, 논리 링크 FIFO, 작업 ID 결합, MatVec 결과를 하나의 상위 모듈로 연결했습니다. gate_proj, lm_head, o_proj 세 타일이 모두 INT32 기준과 일치했습니다. 이 실제 타일 시험은 1클러스터·1채널·S0이며, S3 작업 소유권 시험은 별도의 합성 스케줄러 시험 입력입니다. 응답은 MIG가 아니라 시험벤치 경계에서 주입했습니다. 세 타일의 수락 사이클은 5, 89, 173이고 결과 사이클은 88, 172, 256입니다. 이 기능 시험은 1클러스터 S0이므로 작업 훔치기 성능 증거와 분리합니다.

그림 설명 순서: 데이터 흐름 영상 → 세 타일 사이클 → 3/3 일치 → 시험 범위

전환: 이제 동적 재분배가 필요한 정적 큐 문제를 보겠습니다.

예상 질문: 실제 Gemma가 FPGA에서 실행됐다고 볼 수 있는가?

답변 핵심: 아닙니다. 실제 가중치 타일 세 개의 논리 RTL 산술만 확인했으며 전체 Gemma 추론은 실행하지 않았습니다.

해석 경계: GTH·CDC·MIG 물리 타이밍과 작업 훔치기 결합 실험은 포함하지 않습니다.

주의할 표현: 세 타일 일치를 전체 모델 실행·정확도로 확대하지 않는다.

## Slide 6: 정적 로컬 큐는 지역성을 지키지만 작업대를 놀린다 (0:40)

기억할 문장: 정적 큐의 문제는 전체 자원 부족보다 작업 쏠림입니다.

발화문: 각 클러스터가 자기 큐만 처리하면 가중치 지역성은 좋습니다. 하지만 C0에 작업이 몰리면 C1부터 C3이 비어 있어도 도와주지 못하고, 뒤쪽 TileJob의 p95와 p99가 길어집니다.

그림 설명 순서: C0의 긴 대기열 → C2·C3 유휴 → 지역성과 부하 균형의 충돌

전환: 빈 작업대가 일을 가져오는 조건을 추가했습니다.

예상 질문: 정적 큐가 지역성을 지키면서도 왜 꼬리 지연을 만드는가?

답변 핵심: 정적 소유권 때문에 한 큐가 밀려도 빈 클러스터가 돕지 못해 뒤쪽 작업의 대기가 길어집니다.

해석 경계: 이 화면은 개념이며 수치는 뒤의 동일 시드 실험에서 제시합니다.

주의할 표현: 정적 큐를 모든 조건에서 나쁜 정책이라고 일반화하지 않는다.

## Slide 7: 이득이 이동 비용보다 클 때만 훔친다 (0:40)

기억할 문장: S3 지역성 인식 작업 훔치기(Work Stealing)는 이동 비용을 서비스 시간에 직접 반영합니다.

발화문: 유휴 클러스터가 실행 가능한 작업을 찾고, 기다림 감소에서 데이터 이동 비용을 뺀 값이 양수일 때만 작업 소유권을 옮깁니다. S2는 가장 오래된 작업을 가져오지만 S3는 지역성 비용을 포함해 원격 이동량을 줄입니다. S3 지역성 인식 작업 훔치기는 가중치뿐 아니라 활성값, 부분합, 링크 묶음 불일치 비용도 포함합니다. 추가 전송량은 사후 통계가 아니라 서비스 시간에 직접 부과됩니다.

그림 설명 순서: 유휴 감지 → 피해 큐 탐색 → 이동 비용 계산 → 소유권 이동 → 완료

전환: 정책을 실제 Gemma 형상의 작업으로 바꾸겠습니다.

예상 질문: S3는 어떤 기준으로 작업을 훔치지 않기로 결정하는가?

답변 핵심: 대기 감소 이득이 가중치·활성값·부분합·링크 이동 비용보다 클 때만 소유권을 옮깁니다.

해석 경계: 영상은 정책 상태 전이이며 최적성이나 보드 타이밍을 뜻하지 않습니다.

주의할 표현: 정책 점수를 최적성 증명이나 보드 타이밍으로 말하지 않는다.

## Slide 8: Gemma 그래프를 의존성 있는 802개 TileJob으로 변환 (0:45)

기억할 문장: 그래프 형상과 단계·토큰 의존성, 네 초기 배치를 명시적으로 모델링했습니다.

발화문: 7,837개 그래프 노드에서 토큰당 183개 밀집 투영을 찾고 N≤1024 기준으로 802 TileJob을 만들었습니다. q/k/v 다음 o, MLP, 다음 계층, lm_head 뒤 다음 토큰 순서를 지켰습니다. 32토큰은 25,664 TileJob입니다. 네 초기 배치를 비교해 처음부터 잘 나눈 효과와 나중에 훔친 효과를 구분했습니다.

그림 설명 순서: 7,837개 노드 → 183개 투영 → 802개 TileJob → 의존성 사슬

전환: 같은 작업과 시드에서 정책만 바꾼 실행을 보겠습니다.

예상 질문: 183개 투영과 802개 TileJob은 어떻게 다른가?

답변 핵심: 183은 그래프의 밀집 투영 수이고 802는 이를 N≤1024·전체 K 범위로 나눈 하드웨어 작업 수입니다.

해석 경계: 802와 25,664는 그래프 형상과 명시한 타일 분할 규칙의 결과입니다.

주의할 표현: 그래프 작업 수를 실제 FPGA 실행 횟수라고 말하지 않는다.

## Slide 9: 동일 작업·동일 시드에서 S1과 S3만 바꿨다 (0:45)

기억할 문장: 실행 사건 CSV의 같은 작업을 대기·원격 준비·연산 구간으로 비교합니다.

발화문: 합성 편향 부하의 같은 1,000개 작업과 같은 시드에서 정책만 바꿨습니다. 대표 작업 훔치기 세 건을 확대해 도착부터 배치까지의 대기, 원격 복사, 연산, 완료를 색으로 구분했습니다. 모든 정책은 완료 ID와 작업 해시가 같고 중복과 누락이 없습니다. J79, J90, J100의 숫자는 원본 사건 CSV에서 가져왔습니다. 구간 폭은 가독성을 위해 압축했지만 상자 안 사이클, 클러스터, 작업 ID는 원본과 같습니다.

그림 설명 순서: 왼쪽 S1 → 오른쪽 S3 → J79·J90·J100 → 색 범례

전환: 다섯 시드를 짝지은 꼬리 지연 결과를 보겠습니다.

예상 질문: 이 타임라인은 실제 Gemma 실행인가?

답변 핵심: 아닙니다. 같은 합성 편향 작업 1,000개와 같은 시드에서 정책만 바꾼 분석 사건입니다.

해석 경계: 분석 사건이며 GTH·DDR 물리 사이클이 아닙니다.

주의할 표현: 분석 사건을 DDR·GTH 물리 사이클로 부르지 않는다.

## Slide 10: 효과는 부하 불균형과 초기 배치에 조건부 (0:45)

기억할 문장: 작업 훔치기는 남은 불균형이 큰 조건에서만 효과가 있습니다.

발화문: 합성 편향 부하에서 S3는 S1보다 TileJob p95를 19.13%, p99를 18.71% 줄였습니다. Gemma 형상에서는 기존 산술 배치가 p95를 0.28% 늘렸고 채널 친화 배치에서는 19.79% 줄였습니다. 보편적 우월성이 아니라 효과 조건을 분리한 결과입니다.

그림 설명 순서: 합성 부하 p95·p99 → Gemma 기존 배치 → 채널 친화 배치

전환: 이득과 함께 새로 생긴 비용을 보겠습니다.

예상 질문: 왜 Gemma 배치에 따라 p95 결과의 방향이 달라지는가?

답변 핵심: 작업 훔치기는 초기 배치 뒤에 남은 불균형만 줄이므로 기존 산술 배치와 채널 친화 배치의 결과 방향이 달라집니다.

해석 경계: p95와 p99는 의존성 해제 뒤 TileJob 완료 분포이며 사용자 응답 지연이 아닙니다.

주의할 표현: TileJob p95를 사용자 요청 지연으로 부르지 않는다.

## Slide 11: 작업 훔치기는 병목을 없애지 않고 이동시킨다 (0:40)

기억할 문장: 비교 기준을 분리하면 꼬리 지연 감소와 이동량 감소가 완료시간 개선을 보장하지 않음을 볼 수 있습니다.

발화문: S3 대 S1에서 p95는 19.13% 줄었습니다. S3 대 S2에서 원격 가중치는 35.49% 줄었지만 완료시간은 0.01% 늘어 사실상 같았습니다. 첫 비교는 정적 큐 효과, 두 번째는 지역성 점수 효과입니다. 왼쪽은 정적 S1과 S3를 비교하고 오른쪽은 가장 오래된 작업 우선 S2와 S3를 비교합니다. 기준이 다르므로 세 수치를 하나의 연속 인과식으로 읽으면 안 됩니다.

그림 설명 순서: S1 대비 p95 → S2 대비 원격 가중치 → 완료시간 → 기준 차이

전환: 이제 전체 구조가 K26 로컬 기준선을 이기는지 보겠습니다.

예상 질문: 세 수치의 비교 기준이 서로 다른 이유는 무엇인가?

답변 핵심: S1 비교는 정적 큐 대비 재분배 효과를, S2 비교는 단순 훔치기 대비 지역성 점수 효과를 분리합니다.

해석 경계: 서로 다른 기준의 수치를 하나의 인과식으로 해석하지 않습니다.

주의할 표현: 서로 다른 기준의 수치를 하나의 연속 인과식으로 묶지 않는다.

## Slide 12: 이번 민감도에서는 K26 로컬이 우선이다 (0:45)

기억할 문장: Gemma 1B의 기본 선택은 이번 분석 민감도에서 K26 로컬입니다.

발화문: 대표 중앙 조건에서 K26 로컬 9.6 GB/s는 약 24.6M사이클, 외부 4채널 6.4 GB/s는 약 120.6M사이클이었습니다. 모든 시험 범위에서 외부 후보가 로컬을 이기지 못했습니다. 외부 구조는 더 큰 모델, 더 긴 문맥, 실제 로컬 경합이 계측될 때 재평가해야 합니다. 4.8, 9.6, 14.4 GB/s의 로컬과 3.2, 6.4, 12.8 GB/s의 외부 민감도를 비교했습니다. 전 범위에서 외부 후보가 로컬 완료시간을 이기지 못했습니다.

그림 설명 순서: K26 로컬 → 외부 후보 → 시험 대역폭 범위 → 채택 보류 조건

전환: 물리 후보를 어디까지 구체화했는지 보겠습니다.

예상 질문: K26 로컬이 이겼는데 외부 구조 연구가 왜 의미 있는가?

답변 핵심: 이번 1B 조건은 K26 로컬이 우선이지만 더 큰 모델·긴 문맥·실측 로컬 경합에서는 외부 후보를 다시 평가할 가치가 있습니다.

해석 경계: 분석 모델의 민감도이며 보드 측정이나 주파수 환산값이 아닙니다.

주의할 표현: 민감도 결과를 보드 실측이나 미래 모든 조건으로 일반화하지 않는다.

## Slide 13: KiCad 결과는 참조 라우팅 쿠폰이다 (0:45)

기억할 문장: 쿠폰은 경계 링크·기준 클록·DDR3L 한 슬라이스의 물리 질문을 구체화합니다.

발화문: 범용 경계 커넥터, DDR3L x16 한 슬라이스, GTH/기준 클록 일부 배선을 실제 KiCad 객체로 만들었습니다. 풋프린트 29개와 배선 20개, 선언된 쿠폰 범위의 ERC/DRC 0을 확인했지만 전체 116개 신호망 중 55개가 미배선이고 SI/PI/PDN도 남았습니다. 화면의 J1·J2는 특정 K26나 Memory FPGA BGA 핀 배치가 아니라 범용 경계입니다. 미배선 55개와 SI·PI·PDN 관문 때문에 제작 대상으로 사용할 수 없습니다.

그림 설명 순서: 전체 KiCad 렌더 → 경계 링크 → 기준 클록 → DDR3L 쿠폰 → 제작 금지

전환: 이제 현재 한계와 다음 검증 순서를 분명히 하겠습니다.

예상 질문: 이 PCB 자료로 바로 제작할 수 있는가?

답변 핵심: 아닙니다. 범용 경계와 일부 GTH·기준 클록·DDR3L 배선을 확인한 참조 쿠폰이며 미배선·SI/PI/PDN 과제가 남았습니다.

해석 경계: REFERENCE COUPON이며 NOT FOR FABRICATION입니다.

주의할 표현: 쿠폰 ERC/DRC 0을 전체 보드 제작 준비 완료로 말하지 않는다.

## Slide 14: 한계와 향후 탐구 방향 (0:25)

기억할 문장: 한계는 미완성 목록이 아니라 다음 검증 순서를 결정합니다.

발화문: 현재 결과는 제한 RTL과 분석 모델까지입니다. 다음은 K26 로컬 기준선을 측정하고 물리 폐루프를 연결한 뒤 정확성·대역폭·꼬리 지연·SI/PI·전력을 재평가합니다.

그림 설명 순서: 현재 한계 세 가지 → 대응 탐구 세 단계 → 검증 순서

전환: 세 문장으로 결론과 기여를 정리하겠습니다.

예상 질문: 가장 먼저 수행할 후속 실험은 무엇인가?

답변 핵심: 동일 Gemma 작업의 K26 로컬 보드 기준선을 먼저 측정한 뒤 물리 폐루프와 전력 평가를 연결합니다.

해석 경계: 현재 성능·전력은 보드 실측이 아니며 제작 가능한 전체 보드도 아닙니다. 후속 물리 폐루프는 packet/GTH·CDC·credit, MIG timing, 핀·전원·배선, SI/PI·보드 계측 순입니다.

주의할 표현: 한계를 변명처럼 나열하지 말고 후속 검증 순서로 연결한다.

## Slide 15: 결론 및 기여 (0:25)

기억할 문장: 구조, 조건, 채택 판단이 이 연구의 세 줄 결론입니다.

발화문: 첫째 계산·공급 역할 분리 후보를 설계했습니다. 둘째 분석 모델에서 이동 비용을 포함한 Work Stealing 조건을 분리했습니다. 셋째 이번 민감도에서 Gemma 1B는 K26 로컬 우선입니다.

그림 설명 순서: 01 후보 구조 → 02 효과 조건 → 03 채택 판단 → GitHub QR

전환: 이상으로 발표를 마치겠습니다.

예상 질문: 가장 독창적인 기여를 한 가지로 압축하면 무엇인가?

답변 핵심: 계산 위치와 데이터 위치를 이동 비용까지 포함해 함께 평가한 공동설계입니다.

해석 경계: 재현 시작 명령은 `make setup && make reproduce`이며 공개 저장소의 수치도 분석 모델 경계를 유지합니다.

주의할 표현: 세 문장 밖의 세부 설명을 화면에 추가하지 않는다.

## Slide 16: Q&A (0:15)

기억할 문장: 질문은 결론→근거→경계→다음 검증 순서로 짧게 답합니다.

발화문: 이상으로 발표를 마치겠습니다. 질문 받겠습니다.

그림 설명 순서: 화면 중앙 Q&A → 질문을 향해 시선 이동

전환: 감사합니다.

예상 질문: 질문을 받으면 어떤 순서로 답할 것인가?

답변 핵심: 결론 한 문장, 근거 유형과 수치, 해석 경계, 다음 검증 순서로 25초 안에 답합니다.

해석 경계: 상세 답변은 study/10_qna_bank.md와 study/15_final_round_scoring_strategy.md의 발표자 참고 자료에만 둡니다.

주의할 표현: 준비된 질문·답변을 화면에 표시하거나 노트를 그대로 읽지 않는다.

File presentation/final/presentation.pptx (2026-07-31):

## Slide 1

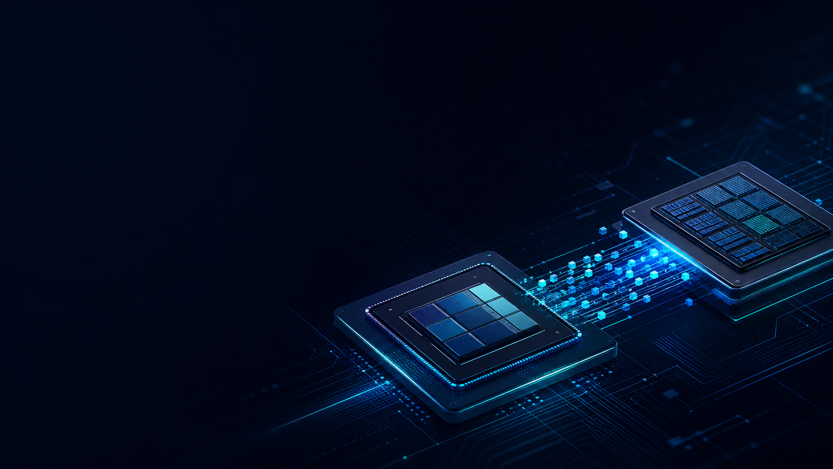
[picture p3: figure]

정적 큐의 Tail을 줄이는
Work Stealing

Gemma 3 1B · K26–Memory FPGA 논문

연구 질문 | Tail 감소는 언제 이동 비용보다 큰가?

최윤혁 · 한국디지털미디어고등학교

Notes: 기억할 문장: 이 논문은 Work Stealing이 항상 빠르다는 주장이 아니라, 실제 LLM 작업에서 언제 Tail 감소가 이동 비용보다 큰지를 묻습니다.

오늘 말씀드릴 질문은 단순히 메모리 대역폭이 중요한가가 아닙니다. 실제 Gemma 3 1B 작업을 여러 연산 클러스터에 나눌 때, 정적 소유권 때문에 일부 큐가 길어지고 다른 클러스터가 쉬는 상황을 어떻게 줄일 것인가입니다.

제안 구조는 K26 연산 SoC와 외부 Memory FPGA를 결합하고, Multi-Queue FCFS 위에 지역성 비용을 고려한 Work Stealing을 적용합니다. 핵심은 무조건 작업을 옮기는 것이 아니라, Tail을 줄이는 이득이 링크·메모리 이동 비용보다 큰 조건을 찾는 것입니다.

먼저 정적 큐에서 왜 Tail이 생기는지 보겠습니다.

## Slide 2

연구 질문: 지역성과 부하 균형을 함께 얻을 수 있는가

정적 소유권의 locality 이점과 queue skew의 Tail 비용을 함께 측정해야 한다.

S1 정적 로컬 큐

클러스터 0

느린 5%가 길어진다

지역성
유지

부하 균형
실패

클러스터 1

유휴

클러스터 2

유휴

클러스터 3

유휴

p95

연구 공백 | 실제 LLM graph · p95/p99
· 원격 byte를 한 조건에서 연결

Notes: 기억할 문장: 연구 공백은 locality와 load balance를 따로 보는 것이 아니라 p95·p99와 원격 byte를 같은 작업에서 연결하는 데 있습니다.

S1 정적 로컬 큐에서는 각 TileJob이 home cluster의 FCFS 큐에 들어갑니다. 이 방식은 원격 가중치 이동을 만들지 않는 장점이 있지만, skew가 생기면 Cluster 0의 큐만 길어지고 나머지 클러스터는 할 일이 없어집니다.

평균 지연만 보면 이 현상이 약하게 보일 수 있습니다. 하지만 사용자 체감과 시스템의 느린 요청을 결정하는 p95와 p99에서는 긴 queue wait가 그대로 드러납니다. 따라서 이 연구의 목표는 평균 처리량보다 Tail을 줄이면서 이동 비용을 통제하는 것입니다.

이 문제를 풀기 위해 계산 소유권과 메모리 친화도를 분리한 구조를 설계했습니다.

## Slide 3

연구 대상 구조와 구현 경계

K26의 계산 소유권과 Memory FPGA의 데이터 친화도를 TileJob에서 분리한다.

K26 연산 SoC

Memory FPGA

채널 친화도 + Bank 인식 큐

타일
스케줄러

페이로드 저장소

요청·제어 →

← 가중치 응답

4-bundle 링크

응답 폐루프 미구현

클러스터 0
MatVec

클러스터 1
MatVec

DDR3L
CH 0

DDR3L
CH 1

DDR3L
CH 2

DDR3L
CH 3

클러스터 2
MatVec

클러스터 3
MatVec

TileJob = 계산 소유권 + 데이터 친화도

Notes: 기억할 문장: 논문의 시스템 모델은 계산 위치와 데이터 위치를 분리하지만, 닫힌 DDR 응답 경로까지 구현했다고 주장하지 않습니다.

왼쪽 K26에는 TileScheduler, payload store, 네 개의 compute cluster와 signed INT8 16×4 MatVec가 있습니다. TileJob은 작업 identity, K/N 범위, weight·activation 주소, preferred channel과 link bundle을 보존합니다.

오른쪽 Memory FPGA 후보는 네 DDR3L 채널과 네 link bundle을 통해 weight service를 분리하는 구조입니다. 스케줄러는 어느 cluster가 계산할지 정하고, channel affinity는 데이터 이동 비용을 계산하는 기준이 됩니다.

현재 runnable RTL은 scheduler에서 payload store와 MatVec 결과까지입니다. DDR response와 link receive의 완전한 폐루프는 다음 검증 단계이며, 오늘의 중심은 이 구조 위에서 scheduling 조건을 분석한 결과입니다.

이제 유휴 클러스터가 어떤 규칙으로 작업을 가져오는지 보겠습니다.

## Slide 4

지역성 비용을 반영한 Work Stealing

S3는 job age에서 원격 이동 비용을 뺀 점수가 양수인 작업만 훔친다.

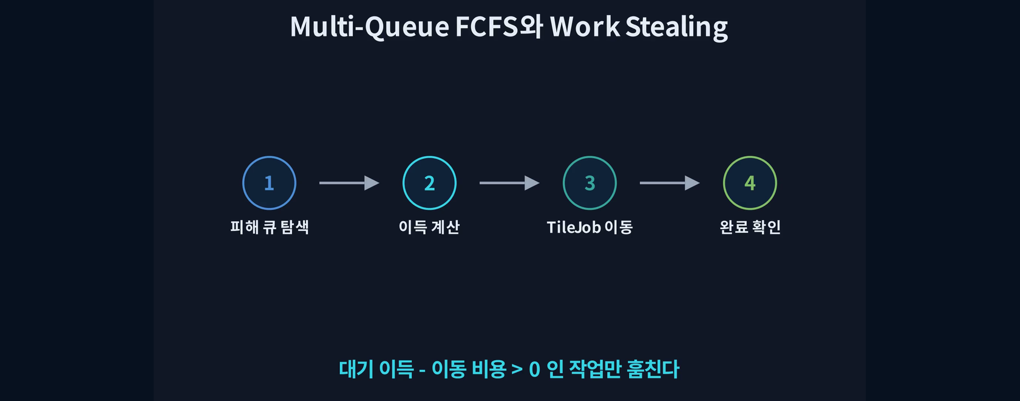
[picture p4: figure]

score = job age - remote weight - activation/reduction - bundle mismatch

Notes: 기억할 문장: S3는 가장 오래된 작업을 그대로 가져오지 않고, 대기 이득에서 데이터 이동 비용을 뺀 선택을 합니다.

첫째, local queue가 비면 cluster가 유휴 상태임을 확인합니다. 둘째, 다른 victim queue에서 실행 가능한 작업을 탐색합니다. 셋째, job age에서 원격 weight, activation, reduction owner와 bundle mismatch 비용을 뺀 locality score를 계산합니다.

넷째, score가 양수인 eligible TileJob을 선택해 유휴 cluster로 옮깁니다. 마지막으로 job identity를 유지해 정확히 한 번만 completion이 발생하는지 검사합니다.

비교 기준인 S2는 가장 오래된 eligible job을 바로 가져옵니다. S3는 이동량을 줄이기 위해 지역성 비용을 함께 보므로 Tail과 remote traffic 사이의 절충이 생깁니다.

이 다섯 단계는 정책 개념을 설명합니다. 분석 모델은 victim queue의 모든 eligible job을 탐색하지만 현재 RTL은 victim head만 검사하며 ownership과 score 정의도 다릅니다. 따라서 model과 RTL이 알고리즘적으로 동일하다고 해석하면 안 됩니다.

정책을 비교하려면 실제 모델 작업을 동일한 TileJob ledger로 만들어야 합니다.

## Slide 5

실제 Gemma graph에서 평가 작업을 만든다

실제 projection 순서를 보존한 5,856개 TileJob과 조건 탐색용 stress를 분리한다.

7,837

ONNX 그래프
노드

실제 그래프

183

프로젝션 / 토큰

프로젝션 필터

5,856

TileJob · 디코드
32

Gemma replay
5,856개 작업

Gemma replay ≠ 조건 분석용 합성 스트레스 · 다음 결과는 별도 작업 집합

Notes: 기억할 문장: 실제 Gemma replay는 연구의 현실성을, 별도 synthetic stress는 효과가 발생하는 조건을 검증합니다.

해시로 고정한 Gemma 3 1B ONNX graph에는 7,837개 node가 있습니다. 여기서 attention의 q·k·v·o, MLP의 gate·up·down, lm_head를 필터링하면 token당 183개 projection이 됩니다.

Decode-32 조건에서는 183 곱하기 32, 즉 5,856개의 coarse TileJob ledger를 만듭니다. 이 ledger로 실제 Gemma replay를 만들고, 별도 stress로 효과 조건을 분리해 확인했습니다.

다음 세 슬라이드는 이 한 개 replay를 반복하지 않습니다. 정책이 유효한 조건을 보기 위해 별도로 생성한 1,000-job 치우침 스트레스와 5개 seed를 사용합니다. 모든 비교에서 input, dispatch, completion ID가 같고 중복과 누락이 0인지 확인했습니다.

다음 슬라이드는 전체 2,000개 event를 축소한 그림이 아니라, 실제 차이가 시작되는 동일 시간 구간을 확대합니다.

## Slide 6

동일 조건에서 S1과 S3의 실행을 비교한다

같은 job stream에서 정책만 바꾸면 유휴 구간이 steal 실행으로 전환된다.

동일 1,000-job stream · 동일 자원 · 정책만 변경

회색 큐 대기 · 어두운 데이터 준비 · 밝은 연산 · 청록 훔친 작업

S1 정적 로컬 큐

동일 2k cycle 구간

S3 지역성 인식 Work Stealing

동일 2k cycle 구간

C0

재배치

C0

J120

C1

유휴

C1

J172 · C0→C1

1

C2

유휴

C2

J162 · C0→C2

2

C3

유휴

C3

J143 · C0→C3

3

3 → 0

유휴 클러스터 활용

-18.12%

p95 지연 감소 · S3 vs S1

1.45 MiB

원격 가중치 이동 발생

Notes: 기억할 문장: 공정한 비교를 위해 같은 job identity와 resource 조건을 고정하고 scheduler 정책만 바꿨습니다.

여기부터는 Gemma replay와 별개의 synthetic scheduler 실험입니다. 각 workload는 1,000 job이고 seed 19, 23, 29, 31, 43을 사용합니다. full-overlap analytical model이며 물리 cycle이 아닙니다. 타임라인은 seed 23의 S1과 S3, 총 2,000개 event 중 동일한 41k에서 43k 구간을 확대했습니다.

S1에서는 Cluster 0만 파란 로컬 작업을 처리하고 Cluster 1부터 3은 유휴입니다. S3에서는 J172, J162, J143이 각각 C0에서 C1, C2, C3으로 이동합니다. 회색선은 큐 대기, 어두운 색 구간은 링크·메모리 준비, 밝은 끝 구간은 compute입니다.

전체 5개 seed 중앙값에서 skew p95는 S1 대비 18.12% 줄었습니다. 그 대가로 S3에는 약 1.45 MiB의 원격 가중치 이동이 생깁니다. 즉 유휴를 줄인 효과와 이동 비용을 함께 봐야 합니다.

이제 p95뿐 아니라 p99도 같은 방향인지 확인하겠습니다.

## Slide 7

실제 Gemma replay에서도 Tail이 감소했다

실제 replay의 p95·p99 감소를 확인하고 별도 stress로 효과 조건을 분리했다.

실제 Gemma projection ledger · 5,856 jobs · 분석 replay

p95

p99

S1

S1

S3

S3

-15.07%

-14.61%

별도 skew stress: p95 -18.12%

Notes: 기억할 문장: 실제 Gemma replay의 감소와 synthetic skew의 조건 분석이 같은 방향을 보이지만, 두 수치를 같은 실험으로 합치면 안 됩니다.

먼저 실제 Gemma decode-32 graph-derived ledger의 analytical replay입니다. 5,856개 coarse TileJob에서 S3는 S1보다 p95를 15.07%, p99를 14.61% 줄였습니다. 이 값은 실제 graph order와 tensor byte에서 파생됐지만 시간은 보드 측정이 아니라 분석 모델입니다.

아래 보조 수치인 18.12%는 별도의 1,000-job synthetic skew, 5개 seed 중앙값입니다. 실제 replay와 동일한 실험으로 합치는 값이 아니라, queue skew가 Tail 감소의 조건임을 확인하는 stress 결과입니다.

Mixed workload에서도 p95는 17.59% 줄고 p99도 감소합니다. 반면 balanced와 channel-hotspot에서는 stealing할 불균형이 없거나 memory channel 자체가 병목이어서 S3의 이득이 나타나지 않습니다.

따라서 결론은 S3가 항상 빠르다는 것이 아닙니다. 실제 graph-derived replay에서 방향성을 확인하고, 별도 stress로 정적 ownership의 queue skew가 효과 조건임을 분리해 확인했다는 것입니다.

그렇다면 줄어든 queue wait의 비용이 어디로 이동하는지 보겠습니다.

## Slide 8

Tail 감소의 비용은 원격 이동이다

S3는 S2보다 원격 가중치를 줄이지만 마지막 completion은 조금 늦어진다.

합성 skew · 1,000 jobs · 5-seed 중앙값 · 분석 모델

1

2

3

Tail 감소

-18.12%

p95 · S3 vs S1

원격 이동 최적화

-37.84%

가중치 · S3 vs S2

완료시간 절충

+0.98%

완료시간 · S3 vs S2

큐 감소

원격 가중치 이동

링크·메모리 부담

Sequential 경계에서는 skew의 S2/S3 p95 순위 역전

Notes: 기억할 문장: 지역성 점수는 원격 이동을 줄이지만, 보수적인 선택 때문에 전체 완료시간은 소폭 늘 수 있습니다.

이 수치도 Gemma replay가 아니라 같은 synthetic skew, 5-seed 중앙값, full-overlap analytical model에서 나옵니다. 왼쪽은 S3와 S1의 비교로 p95가 18.12% 감소합니다. 실제 평균 queue wait 감소율은 17.86%이므로 p95와 같은 지표로 해석하면 안 됩니다. 가운데는 S3와 S2의 비교로 remote weight가 37.84% 줄어듭니다.

오른쪽도 S3와 S2의 비교입니다. 더 보수적인 선택 때문에 마지막 completion은 0.98% 길어집니다. 즉 세 수치는 비교 기준이 서로 다릅니다. S1은 정적 baseline이고, S2는 locality를 고려하지 않는 stealing baseline입니다.

그리고 service composition을 sequential 경계로 바꾸면 synthetic skew의 S2/S3 p95 순위가 뒤집힙니다. 따라서 S3의 S2 대비 Tail 우위는 서비스 중첩 가정에 조건부입니다.

이 결과는 queue wait가 줄어든 대신 link와 memory service가 더 중요해졌음을 보여줍니다. 다음 단계는 이 비용을 실제 보드 인터페이스에서 계측하는 것입니다.

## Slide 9

물리 참조 설계로 다음 검증 범위를 고정했다

Native KiCad coupon으로 링크와 제한 검증 범위를 고정했다.

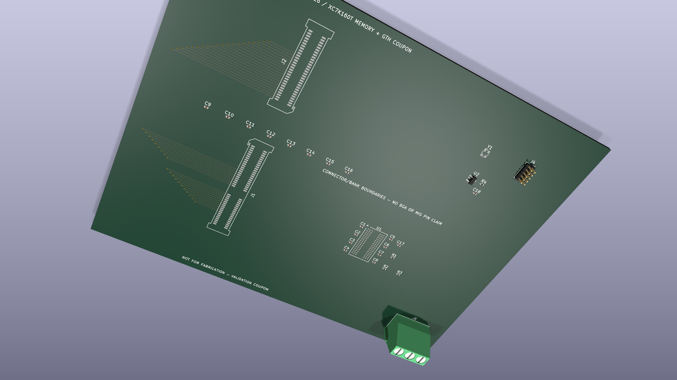
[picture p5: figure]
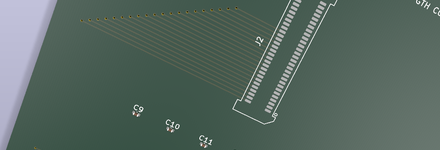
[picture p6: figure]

K26–Memory FPGA 링크

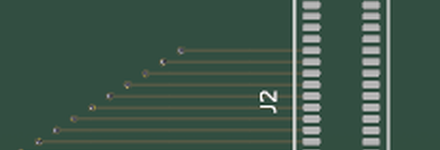
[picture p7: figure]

기준 클록 차동쌍

N

P

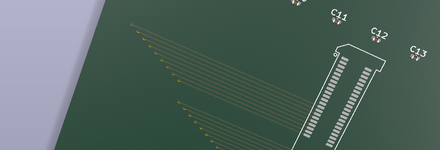
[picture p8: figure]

대표 라우팅 쿠폰

풋프린트 29개

GTH/refclk 배선 20개

ERC 0 · 부분 DRC 0

NOT FOR FABRICATION · 참조 쿠폰

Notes: 기억할 문장: KiCad coupon의 역할은 제품 보드를 보여주는 것이 아니라 다음 물리 검증의 인터페이스와 범위를 고정하는 것입니다.

가운데 큰 이미지는 native KiCad source에서 렌더한 validation coupon입니다. 오른쪽 확대는 K26–Memory FPGA 연결 경계, 기준 클록 차동 경로, 대표 routed coupon 영역을 실제 render에서 잘라 보여줍니다.

현재 coupon에는 29 footprints, 20개의 routed GTH/refclock nets가 있고 선언한 제한 범위에서 ERC와 routed-subset DRC가 0입니다. 그러나 전체 보드에는 55 unrouted nets가 남아 있고, MIG pin placement, SI/PI, PDN, thermal과 timing closure는 수행하지 않았습니다.

따라서 이 이미지는 알고리즘을 어떤 인터페이스로 내려갈지 구체화한 reference coupon입니다. 제작 가능성을 주장하지 않고, 다음 검증의 대상과 범위를 명확히 한 것입니다.

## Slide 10

기여와 한계: 조건부 효과를 규명했다

실제 workload·스케줄러·제한 물리 근거를 하나의 주장 사슬로 연결했다.

1

2

3

실제 Gemma
작업 부하

그래프 → TileJob

지역성 인식
스케줄링

Tail + 이동 비용

물리 참조 설계

RTL → KiCad

다음 검증 | DDR 응답 → Link 수신 → Weight FIFO → MatVec

현재: analytical/RTL-bounded · 보드 성능·전력은 미측정

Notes: 기억할 문장: 이 논문의 기여는 Work Stealing의 보편적 우월성이 아니라 효과가 생기는 조건과 아직 남은 검증을 함께 제시한 것입니다.

실제 Gemma graph에서 TileJob 변환을 정의했고, 별도의 제어된 스트레스에서 Tail과 이동 비용 조건을 분석했으며, 그 구조를 K26–Memory FPGA RTL과 KiCad 참조 설계까지 연결했습니다.

다음 단계는 DDR 응답부터 MatVec까지 폐루프를 완성하고 실제 대역폭·Tail·보드 전력을 측정하는 것입니다.

정적 큐의 유휴를 줄이면 Tail은 짧아지지만 링크·메모리 비용이 생깁니다. 이 연구는 그 재배치가 유효한 조건을 함께 제시합니다. 질문 받겠습니다.

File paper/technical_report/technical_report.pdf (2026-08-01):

# 온디바이스 sLLM용 K26–Memory FPGA 후보

# 구조: 확장 기술보고서

Extended Technical Report on Dependency-Aware Mapping, Closed Logical RTL, and Placement Sensitivity

최윤혁 (CHOI YUNHYUK) · 한국디지털미디어고등학교 · ORCID 0009-0006-3537-0249

2026-08-01

초록

온디바이스 소형 언어 모델은 서버급 가속기를 사용하기 어려워 메모리 용량과 가중치 공급 대역폭을 제한된 전력·비용 안에서 함께 해결해야 한다. 본 연구는 Kria K26이 연산·제어를 맡고 외부 Memory FPGA가 다채널 가중치 공급을 맡는 확장형 후보 구조를 설계했다. 정적 작업 배정으로 일부 연산 클러스터가 유휴 상태에 빠질 때는 데이터 이동 비용을 고려한 작업 훔치기(Work Stealing)를 선택적으로 사용한다. 실제 Gemma 3 1B 그래프의 7,837개 노드에서 토큰당 183개 투영 연산을 추출하고, 이를 의존성이 있는 802개 출력 타일로 변환해 네 가지 초기 배치와 세 가지 대기열 정책을 비교했다. 합성 불균형 부하에서 지역성 인식 정책은 정적 배정보다 TileJob p95를 19.13% 줄이고, 단순 작업 훔치기보다 비지역 가중치 이동량을 35.49% 줄였다. 그러나 Gemma 형상에서는 초기 배치에 따라 p95 변화가 +0.28%에서 −19.79%까지 달라졌으며, K26 로컬 메모리 기준선도 외부 6.4 GB/s 후보보다 짧았다. 따라서 외부 8GB와 작업 재분배는 Gemma 1B의 필수 구성요소가 아니라 더 큰 모델·긴 문맥· 로컬 경합이 확인될 때 채택할 확장 수단이다. 결과는 제한된 RTL 시뮬레이션과 분석 모델에 근거하며 보드 실측값이 아니다.

핵심어: 온디바이스 sLLM, Kria K26, Memory FPGA, 다채널 메모리, 작업 훔치기, SpinalHDL

# Abstract

On-device small language models must address memory capacity and weight-delivery bandwidth within tighter power and cost limits than server accelerators. This work evaluates an extensible candidate architecture in which a Kria K26 handles control and computation while an external Memory FPGA supplies weights through multiple memory channels. Locality-aware work stealing is enabled only when static placement leaves compute clusters idle and its expected benefit exceeds data-movement cost. From the 7,837-node Gemma 3 1B graph, 183 projections per token are mapped to 802 dependency-aware output tiles and evaluated under four initial placements and three queue policies. On a synthetic skew workload, the locality-aware policy reduces TileJob p95 by 19.13% against static placement and non-local weight movement by 35.49% against oldest-job stealing. On Gemma-shaped tiles, however, the p95 effect ranges from +0.28% to −19.79% depending on initial placement, and the modeled K26-local baseline remains shorter than the external 6.4-GB/s candidate. External 8GB memory and work stealing are therefore conditional expansion mechanisms rather than requirements for Gemma 1B. The results are based on bounded RTL simulation and analytical models, not board measurements.

Keywords: on-device sLLM, Kria K26, Memory FPGA, multi-channel memory, work stealing, SpinalHDL

## I. 서론

온디바이스 환경에서는 서버급 GPU의 전력과 가격을 그대로 사용할 수 없다. 모델이 메모리에 들어가는지만 보는 것도 충분하지 않다. 연산부가 가중치를 기다리는 시간, 운영체제·활성값·KV cache가 쓰는 로컬 메모리와 가중치 공급의 경합, 여러 연산 클러스터 사이의 부하 균형이 함께 성능을 결정한다.

본 연구는 처음에 외부 메모리가 Gemma 3 1B의 용량 때문에 필요하다고 가정했다. 그러나 INT8 가중치와 32K 문맥의 용량을 계산한 결과 2.43 GiB로, 명목상 K26 로컬 4GB에 들어갔다. 이에 연구 질문을 “외부 메모리가 필요한가”에서 “가중치 공급을 로컬 실행 메모리와 분리하는 구조는 어떤 조건에서 이득인가”로 바꾸었다.

제안 후보는 K26의 연산·제어와 Memory FPGA의 다채널 가중치 공급을 분리한다. K26에는 네 연산 클러스터와 독립 대기열을 두고, 외부 쪽에는 네 DDR3L x16 채널과 네 논리 링크를 둔다. 정적 배정이 데이터 지역성을 지키더라도 작업이 한쪽에 몰리면 일부 클러스터가 놀 수 있다. 이때만 유휴 클러스터가 다른 대기열의 작업을 가져오며, 이미 배치된 가중치와 활성값을 옮기는 비용을 함께 계산한다.

본 연구의 기여는 다음과 같다. 첫째, 로컬 실행 메모리와 외부 가중치 공급 메모리의 역할을 분리한 온디바이스 확장 후보를 제시하고 K26 로컬 기준선과 비교했다. 둘째, 원격 복사 시간을 실제 링크 서비스에 부과해 초기 배치와 작업 재분배의 효과를 분리했다. 셋째, 실제 Gemma 그래프의 형상에서 TileJob을 만들고, 제한된 실제 가중치 타일이 DMA 명령·메모리 응답 경계· 논리 링크·MatVec까지 통과하는 재현 가능한 흐름을 구현했다.

그림 1. K26의 연산·제어와 Memory FPGA의 가중치 공급을 분리한 후보 구조. 굵은 실선은 연결된 논리 RTL 경로이며, 점선의 GTH·MIG는 후속 물리 구현 범위다.

그림 1. K26의 연산·제어와 Memory FPGA의 가중치 공급을 분리한 후보 구조. 굵은 실선은 연결된 논리 RTL 경로이며, 점선의 GTH·MIG는 후속 물리 구현 범위다.

## II. 관련 연구와 연구 공백

PagedAttention[1]은 KV cache의 페이지 관리 문제를, FlashAttention[2]은 attention 연산의 데이터 이동을 줄이는 방법을 다룬다. GPTQ[3], SmoothQuant[4], AWQ[5]는 모델 크기와 양자화 정확도의 균형을 연구한다. 이 연구들은 메모리 이동이 중요하다는 근거를 제공하지만, 여러 로컬 대기열과 외부 가중치 공급 링크를 함께 가진 소형 FPGA 구조의 초기 배치 문제를 직접 다루지 않는다.

FTRANS[6], DFX[7], FlightLLM[8]은 Transformer의 FPGA 매핑과 다중 FPGA 실행 구조를 제시했다. 이들은 완성된 매핑 흐름이나 처리량을 중심으로 평가한다. 본 연구는 최고 처리량 경쟁보다 설계 조건 규명에 초점을 둔다. K26 로컬 메모리와 외부 다채널 메모리 후보를 같은 작업 형상에서 비교하고, 작업 재분배가 가중치 복사 비용을 감수할 조건을 찾는다.

고전적 작업 훔치기[15]는 의존 작업의 부하 균형을 설명하고, LAWS[16]는 NUMA 환경에서 원격 메모리 비용을 고려한다. 본 연구의 정책은 이들보다 이론적으로 새롭다고 주장하지 않는다. 연구 공백은 실제 sLLM 투영 형상, FPGA 메모리 분리 구조, 초기 배치, 비지역 전송 비용을 하나의 공개 설계 흐름에서 비교한 자료가 부족하다는 점이다.

## III. 온디바이스 가속기의 설계 목표

대상은 3B 이하 sLLM을 향한 확장형 후보이며, 이번 평가는 Gemma 3 1B를 사용한다. K26 로컬 4GB는 운영체제와 실행 환경, 활성값, KV cache, 자주 쓰는 데이터를 담당한다. 외부 메모리는 상주 가중치, 다음 층 사전 적재, 용량 확장을 담당하도록 역할을 나눈다.

표 1. 설계 목표와 이번 평가의 범위

항목 | 목표 | 이번 평가
연산 | K26의 다중 연산 클러스터 | 부호 있는 INT8 MatVec 클러스터 4개
로컬 메모리 | 실행 환경·활성값·KV cache | 4.8–14.4 GB/s 유효 대역폭 민감도
외부 메모리 | 8GB 이상, 채널·랭크 확장 | 4×DDR3L x16, 3.2–12.8 GB/s 분석
링크 | Memory FPGA→K26 가중치 전송 | 논리 링크 4개, 64–256비트 민감도
작업 배치 | 지역성과 부하 균형 | 정적·라운드로빈·크기 균형·채널 친화
물리 검증 | GTH·MIG·전원·보드 계측 | 논리 RTL과 라우팅 쿠폰까지만 수행

외부 8GB는 Gemma 1B가 4GB에 들어가지 않아서 선택한 것이 아니다. 더 큰 모델과 긴 문맥으로 확장하거나, 로컬 실행 메모리의 경합을 줄이고, 여러 클러스터에 독립적인 가중치 공급 경로를 제공하기 위한 후보이다. 따라서 외부 구조는 K26 로컬 기준선보다 나은 조건을 보여야 채택할 수 있다.
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

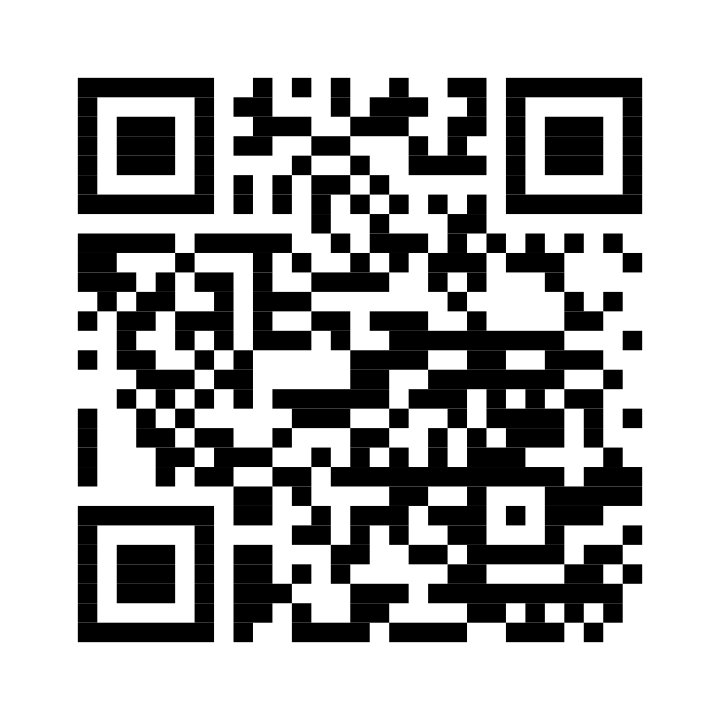
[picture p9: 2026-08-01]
presentation/final/assets/repository_qr.png

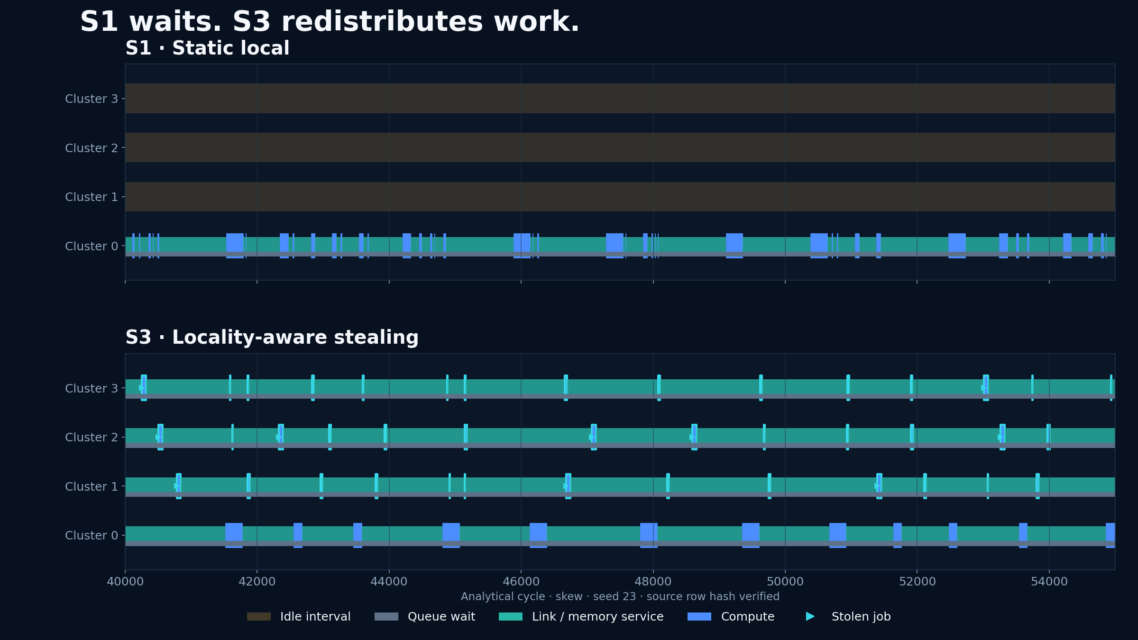
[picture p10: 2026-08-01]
presentation/final/assets/s1_s3_execution_timeline.png

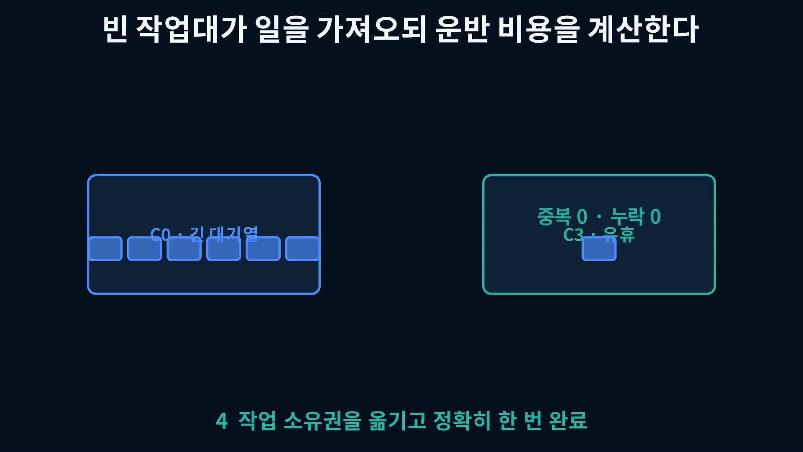
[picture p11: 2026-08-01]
presentation/final/assets/work_stealing_sequence_frame.png

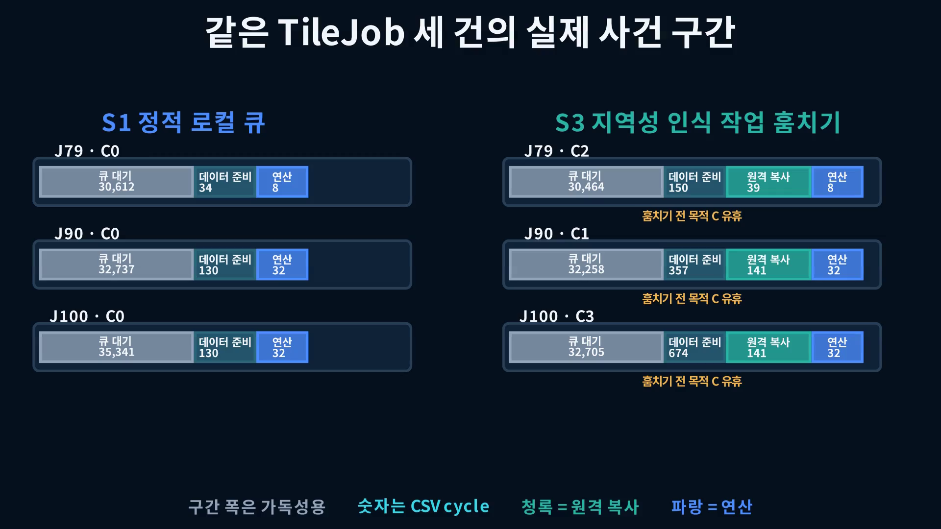
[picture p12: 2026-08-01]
presentation/final/assets/scheduler_timeline_frame.png

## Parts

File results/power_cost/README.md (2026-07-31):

# Bounded power and energy evidence

This directory contains energy **models**, not power measurements.

- `energy_category_model.csv` separates compute, serialized-link, and DDR3L
  command/background categories across low, central, and high scenarios.
- `dramsim3_energy_breakdown.csv` preserves the existing four-channel DRAMsim3
  run's simulated breakdown. DRAMsim3 does not report PRE as an independent
  energy bucket, so PRE is blank rather than fabricated.
- `gemma3_1b_energy_join.csv` joins graph-derived projection/MAC/byte counts
  and hybrid latency to low/central/high energy inputs. Its memory column is
  dynamic READ+ACT+PRE only; refresh, idle, controller, PHY, and board power
  remain excluded. Its link column includes the base modeled transport plus
  scheduler-specific remote-weight, activation-retransmission, and partial-sum
  steal overhead.
- `energy_model_metadata.json` records formula inputs, sources, evidence types,
  and blocked metrics.

Compute is normalized per billion INT8 MACs and link energy per GiB transported.
DRAM categories are normalized per command per x8 die or per idle clock. The
Gemma join supplies MAC, transported-byte, weight-byte, and hybrid elapsed-time
counts. It therefore reports an explicitly estimated dynamic J/token,
J/projection, and energy-delay range. A refresh/idle-inclusive memory or board
J/token remains blocked because the scheduler replay is not a DRAM command
trace.

Vivado, device files, and licensing are absent. There is no synthesis,
place-and-route, SAIF/VCD-based Vivado power analysis, or `report_power`.
Every modeled number must retain the `estimated`, `modeled`, or
`analytical-range` label.

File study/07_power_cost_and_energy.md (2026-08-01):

# 전력·비용·채택 조건

저비용·저전력은 설계 목표다. 현재 전체 BOM, K26/FPGA/전원/PCB/조립 가격과 보드
전력 측정이 없으므로 달성을 주장하지 않는다.

K26 로컬 4.8/9.6/14.4 GB/s와 외부 네 채널 3.2/6.4/12.8 GB/s는 실측이 아니라
민감도 입력이다. 시험 범위에서는 외부 후보가 로컬 기준선을 이기지 못했다.

외부 후보를 다시 볼 조건은 더 큰 모델, 더 긴 문맥, 실제 K26 로컬 경합, 여러
클러스터에 독립 공급 경로가 필요한 경우다. 이후 동일 작업의 처리시간·보드 전력·
전체 BOM을 함께 측정해야 한다.

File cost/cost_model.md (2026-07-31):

# DRAM-die-only cost model

Snapshot date: 2026-07-31

## Scope

The price boundary contains only DDR3L memory components. It excludes the K26
SOM, Memory FPGA, PCB, connectors, regulators, assembly, freight, tax, engineering
labor, and every other system cost. Therefore none of the tables can be called an
accelerator price, product BOM, or system price.

The purchasable comparison part is Alliance Memory
`AS4C1G8D3LA-10BCN`: 8 Gb, 1G×8, 1.35 V DDR3L in a 78-ball dual-die package.
The [manufacturer product page](https://www.alliancememory.com/as4c1g8d3la/)
still lists the commercial, industrial, and automotive variants. The
[manufacturer datasheet](https://www.alliancememory.com/wp-content/uploads/pdf/ddr3/AllianceMemory_DDR3L_8G_AS4C1G8D3LA-10BCN-BIN-BAN_Feb2019_v1.0.pdf)
defines organization and electrical behavior. Listing is evidence of current
catalog presence, not a longevity guarantee.

Two authorized-distributor quantity-1 observations are retained:

- [DigiKey](https://www.digikey.com/en/products/detail/alliance-memory-inc/AS4C1G8D3LA-10BCN/10222124):
  USD 97.10, 667 units shown, Active, manufacturer lead time 40 weeks.
- [Mouser](https://www.mouser.com/ProductDetail/Alliance-Memory/AS4C1G8D3LA-10BCN?qs=unwgFEO1A6tj9PoTtfUwww%3D%3D):
  USD 39.32, 425 units shown, estimated factory lead time 8 weeks. The page did
  not expose a distinct lifecycle field.

Price and stock are volatile snapshots. Recheck immediately before procurement.
`MT41K1G8TRF-125:E` remains an explicitly obsolete Micron topology reference and
is excluded from every cost result.

The distributor price is for one packaged component, not for a bare silicon die.
The Alliance 8 Gb package contains two physical 4 Gb dies. Accordingly, the CSV
retains both package price and an imputed physical-die price (package price ÷ 2).
The latter is normalization arithmetic, not a separately purchasable die quote.
The manufacturer datasheet identifies the two stacked dies as x4 devices that
jointly expose one x8 interface and one package-level chip-select; the package is
therefore modeled as one rank, not two independently selectable ranks.

## Topologies

The 8 GiB baseline (8.590 decimal GB) uses four x16 channels. Each channel has
two 8 Gb ×8 devices
forming one x16 rank: eight packages and sixteen physical dies total. The
16 GiB (17.180 decimal GB) capacity option adds a second such rank to each
channel: sixteen packages and
thirty-two physical dies total. The second rank adds
capacity, not channels or pin bandwidth. Both topologies remain conditional
until four MIG instances, rank control, pin placement, and timing close in
Vivado.

The 6.4 GB/s number is an arithmetic pin-rate ceiling:

`4 channels × 16 bits × 800 MT/s ÷ 8 = 6.4 GB/s`.

It is neither measured nor an effective payload bandwidth. The sensitivity file
applies 0.50/0.70/0.85 delivery factors only to expose the denominator's effect;
these are analytical assumptions, not measured efficiencies.

## Price sensitivity

`cost_sensitivity.csv` independently crosses:

- low/midpoint/high package prices (two observations plus their midpoint); and
- 0.50/0.70/0.85 assumed payload-delivery efficiencies.

The reported metrics include both binary GiB and decimal GB per DRAM-die dollar,
plus modeled effective GB/s per DRAM-die dollar.
`gemma3_1b_cost_normalized.csv` additionally divides the hybrid-modeled Gemma
token rate by the low/midpoint/high 8 GiB DRAM-package cost. The delivery-factor
dimension is intentionally omitted from that table because the current hybrid
latency does not depend on the assumed effective-bandwidth sensitivity; keeping
it would duplicate each token-rate row three times. This is a
hybrid-modeled-token/s per DRAM-package-dollar denominator, not measured
throughput, energy efficiency, accelerator price, or total cost/benefit.

## Claim boundary

The topology tables are `analytical-cost-sensitivity`; the Gemma-normalized table
is `hybrid-modeled+dram-die-cost-sensitivity`. They are not quotes, purchase
orders, total BOMs, or measured cost/benefit. FPGA pricing is absent by design.

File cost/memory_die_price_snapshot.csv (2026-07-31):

snapshot_id | access_date_utc | manufacturer | mpn | description | density_gbit | width_bits | package | physical_dies_per_package | distributor | distributor_sku | quantity | unit_package_price_usd | imputed_unit_physical_die_price_usd | stock_packages | lifecycle_distributor | lifecycle_manufacturer | evidence_type | source_url | source_note | included_in_cost_model
2026-07-31-digikey-q1 | 2026-07-31 | Alliance Memory | AS4C1G8D3LA-10BCN | DDR3L 8Gb 1Gx8 1.35V 933MHz | 8 | 8 | 78-FBGA (9x10.5) dual-die package | 2 | DigiKey | 1450-1485-ND | 1 | 97.10 | 48.55 | 667 | Active | listed in current manufacturer catalog | distributor_snapshot | https://www.digikey.com/en/products/detail/alliance-memory-inc/AS4C1G8D3LA-10BCN/10222124 | USD quantity-1 package price; manufacturer lead time shown as 40 weeks; physical-die price is package price divided by two and is not a separately orderable quote | true
2026-07-31-mouser-q1 | 2026-07-31 | Alliance Memory | AS4C1G8D3LA-10BCN | DDR3L 8Gb 1Gx8 1.35V 933MHz | 8 | 8 | 78-ball FBGA dual-die package | 2 | Mouser | 913-AS4C1G8D3LA10BCN | 1 | 39.32 | 19.66 | 425 | In stock; lifecycle field not exposed on page | listed in current manufacturer catalog | distributor_snapshot | https://www.mouser.com/ProductDetail/Alliance-Memory/AS4C1G8D3LA-10BCN?qs=unwgFEO1A6tj9PoTtfUwww%3D%3D | USD quantity-1 package price; estimated factory lead time 8 weeks; physical-die price is package price divided by two and is not a separately orderable quote | true
2026-07-31-micron-obsolete | 2026-07-31 | Micron | MT41K1G8TRF-125:E | DDR3L 8Gb 1Gx8 1.35V 1600MT/s topology reference | 8 | 8 | 78-TFBGA twin-die package | 2 | not_priced | not_applicable |  |  |  |  | Obsolete | Obsolete | manufacturer_lifecycle | https://www.micron.com/products/obsolete/obsolete-ddr3-sdram/part-catalog | Topology reference only; not a production BOM selection and excluded from every cost calculation | false

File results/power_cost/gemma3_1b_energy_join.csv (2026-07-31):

scenario | scheduler | energy_case | projection_nodes_per_token | macs_per_token | weight_bytes_per_token | base_link_bytes_per_token | steal_overhead_bytes_per_token | link_bytes_per_token | estimated_compute_j_per_token | estimated_link_j_per_token | estimated_memory_dynamic_j_per_token | estimated_total_dynamic_j_per_token | estimated_j_per_projection | hybrid_latency_s_per_token | estimated_energy_delay_j_s | estimated_tokens_per_s | evidence_type | memory_boundary
batch1_decode1 | S0 | low | 183 | 999751680 | 999751680.000 | 1003000416.000 | 0.000 | 1003000416.000 | 0.000999752 | 0.192576080 | 0.081316716 | 0.274892548 | 0.001502145070 | 0.426406547 | 0.117215982028 | 2.345179753 | graph-derived-counts+hybrid-latency+analytical-energy | dynamic READ+ACT+PRE estimate only; refresh, idle, controller, PHY, and board power excluded; link term includes base stream plus scheduler steal overhead
batch1_decode1 | S0 | central | 183 | 999751680 | 999751680.000 | 1003000416.000 | 0.000 | 1003000416.000 | 0.004998758 | 0.410828970 | 0.101550948 | 0.517378677 | 0.002827205886 | 0.426406547 | 0.220613655051 | 2.345179753 | graph-derived-counts+hybrid-latency+analytical-energy | dynamic READ+ACT+PRE estimate only; refresh, idle, controller, PHY, and board power excluded; link term includes base stream plus scheduler steal overhead
batch1_decode1 | S0 | high | 183 | 999751680 | 999751680.000 | 1003000416.000 | 0.000 | 1003000416.000 | 0.014996275 | 0.962880399 | 0.121911126 | 1.099787800 | 0.006009769400 | 0.426406547 | 0.468956717985 | 2.345179753 | graph-derived-counts+hybrid-latency+analytical-energy | dynamic READ+ACT+PRE estimate only; refresh, idle, controller, PHY, and board power excluded; link term includes base stream plus scheduler steal overhead
batch1_decode1 | S0-physical | low | 183 | 999751680 | 999751680.000 | 1003000416.000 | 0.000 | 1003000416.000 | 0.000999752 | 0.192576080 | 0.081316716 | 0.274892548 | 0.001502145070 | 0.426407492 | 0.117216241801 | 2.345174556 | graph-derived-counts+hybrid-latency+analytical-energy | dynamic READ+ACT+PRE estimate only; refresh, idle, controller, PHY, and board power excluded; link term includes base stream plus scheduler steal overhead
batch1_decode1 | S0-physical | central | 183 | 999751680 | 999751680.000 | 1003000416.000 | 0.000 | 1003000416.000 | 0.004998758 | 0.410828970 | 0.101550948 | 0.517378677 | 0.002827205886 | 0.426407492 | 0.220614143974 | 2.345174556 | graph-derived-counts+hybrid-latency+analytical-energy | dynamic READ+ACT+PRE estimate only; refresh, idle, controller, PHY, and board power excluded; link term includes base stream plus scheduler steal overhead
batch1_decode1 | S0-physical | high | 183 | 999751680 | 999751680.000 | 1003000416.000 | 0.000 | 1003000416.000 | 0.014996275 | 0.962880399 | 0.121911126 | 1.099787800 | 0.006009769400 | 0.426407492 | 0.468957757284 | 2.345174556 | graph-derived-counts+hybrid-latency+analytical-energy | dynamic READ+ACT+PRE estimate only; refresh, idle, controller, PHY, and board power excluded; link term includes base stream plus scheduler steal overhead
batch1_decode1 | S1 | low | 183 | 999751680 | 999751680.000 | 1003000416.000 | 0.000 | 1003000416.000 | 0.000999752 | 0.192576080 | 0.081316716 | 0.274892548 | 0.001502145070 | 0.424826817 | 0.116781726023 | 2.353900368 | graph-derived-counts+hybrid-latency+analytical-energy | dynamic READ+ACT+PRE estimate only; refresh, idle, controller, PHY, and board power excluded; link term includes base stream plus scheduler steal overhead
batch1_decode1 | S1 | central | 183 | 999751680 | 999751680.000 | 1003000416.000 | 0.000 | 1003000416.000 | 0.004998758 | 0.410828970 | 0.101550948 | 0.517378677 | 0.002827205886 | 0.424826817 | 0.219796336434 | 2.353900368 | graph-derived-counts+hybrid-latency+analytical-energy | dynamic READ+ACT+PRE estimate only; refresh, idle, controller, PHY, and board power excluded; link term includes base stream plus scheduler steal overhead
batch1_decode1 | S1 | high | 183 | 999751680 | 999751680.000 | 1003000416.000 | 0.000 | 1003000416.000 | 0.014996275 | 0.962880399 | 0.121911126 | 1.099787800 | 0.006009769400 | 0.424826817 | 0.467219350203 | 2.353900368 | graph-derived-counts+hybrid-latency+analytical-energy | dynamic READ+ACT+PRE estimate only; refresh, idle, controller, PHY, and board power excluded; link term includes base stream plus scheduler steal overhead
batch1_decode1 | S2 | low | 183 | 999751680 | 999751680.000 | 1003000416.000 | 93777152.000 | 1096777568.000 | 0.000999752 | 0.210581293 | 0.081316716 | 0.292897761 | 0.001600534213 | 0.426815047 | 0.125013171531 | 2.342935208 | graph-derived-counts+hybrid-latency+analytical-energy | dynamic READ+ACT+PRE estimate only; refresh, idle, controller, PHY, and board power excluded; link term includes base stream plus scheduler steal overhead
batch1_decode1 | S2 | central | 183 | 999751680 | 999751680.000 | 1003000416.000 | 93777152.000 | 1096777568.000 | 0.004998758 | 0.449240092 | 0.101550948 | 0.555789799 | 0.003037102725 | 0.426815047 | 0.237219448835 | 2.342935208 | graph-derived-counts+hybrid-latency+analytical-energy | dynamic READ+ACT+PRE estimate only; refresh, idle, controller, PHY, and board power excluded; link term includes base stream plus scheduler steal overhead
batch1_decode1 | S2 | high | 183 | 999751680 | 999751680.000 | 1003000416.000 | 93777152.000 | 1096777568.000 | 0.014996275 | 1.052906465 | 0.121911126 | 1.189813866 | 0.006501715116 | 0.426815047 | 0.507830460827 | 2.342935208 | graph-derived-counts+hybrid-latency+analytical-energy | dynamic READ+ACT+PRE estimate only; refresh, idle, controller, PHY, and board power excluded; link term includes base stream plus scheduler steal overhead
batch1_decode1 | S3 | low | 183 | 999751680 | 999751680.000 | 1003000416.000 | 68958848.000 | 1071959264.000 | 0.000999752 | 0.205816178 | 0.081316716 | 0.288132647 | 0.001574495337 | 0.425563997 | 0.122618880675 | 2.349822842 | graph-derived-counts+hybrid-latency+analytical-energy | dynamic READ+ACT+PRE estimate only; refresh, idle, controller, PHY, and board power excluded; link term includes base stream plus scheduler steal overhead
batch1_decode1 | S3 | central | 183 | 999751680 | 999751680.000 | 1003000416.000 | 68958848.000 | 1071959264.000 | 0.004998758 | 0.439074514 | 0.101550948 | 0.545624221 | 0.002981553122 | 0.425563997 | 0.232198024297 | 2.349822842 | graph-derived-counts+hybrid-latency+analytical-energy | dynamic READ+ACT+PRE estimate only; refresh, idle, controller, PHY, and board power excluded; link term includes base stream plus scheduler steal overhead
batch1_decode1 | S3 | high | 183 | 999751680 | 999751680.000 | 1003000416.000 | 68958848.000 | 1071959264.000 | 0.014996275 | 1.029080893 | 0.121911126 | 1.165988294 | 0.006371520734 | 0.425563997 | 0.496202638615 | 2.349822842 | graph-derived-counts+hybrid-latency+analytical-energy | dynamic READ+ACT+PRE estimate only; refresh, idle, controller, PHY, and board power excluded; link term includes base stream plus scheduler steal overhead
batch1_decode1 | Oracle | low | 183 | 999751680 | 999751680.000 | 1003000416.000 | 0.000 | 1003000416.000 | 0.000999752 | 0.192576080 | 0.081316716 | 0.274892548 | 0.001502145070 | 0.391898522 | 0.107729983115 | 2.551680970 | graph-derived-counts+hybrid-latency+analytical-energy | dynamic READ+ACT+PRE estimate only; refresh, idle, controller, PHY, and board power excluded; link term includes base stream plus scheduler steal overhead
batch1_decode1 | Oracle | central | 183 | 999751680 | 999751680.000 | 1003000416.000 | 0.000 | 1003000416.000 | 0.004998758 | 0.410828970 | 0.101550948 | 0.517378677 | 0.002827205886 | 0.391898522 | 0.202759938725 | 2.551680970 | graph-derived-counts+hybrid-latency+analytical-energy | dynamic READ+ACT+PRE estimate only; refresh, idle, controller, PHY, and board power excluded; link term includes base stream plus scheduler steal overhead
batch1_decode1 | Oracle | high | 183 | 999751680 | 999751680.000 | 1003000416.000 | 0.000 | 1003000416.000 | 0.014996275 | 0.962880399 | 0.121911126 | 1.099787800 | 0.006009769400 | 0.391898522 | 0.431005213078 | 2.551680970 | graph-derived-counts+hybrid-latency+analytical-energy | dynamic READ+ACT+PRE estimate only; refresh, idle, controller, PHY, and board power excluded; link term includes base stream plus scheduler steal overhead
batch1_decode32 | S0 | low | 183 | 999751680 | 999751680.000 | 1003000416.000 | 0.000 | 1003000416.000 | 0.000999752 | 0.192576080 | 0.081316716 | 0.274892548 | 0.001502145070 | 0.403688313 | 0.110970908870 | 2.477158659 | graph-derived-counts+hybrid-latency+analytical-energy | dynamic READ+ACT+PRE estimate only; refresh, idle, controller, PHY, and board power excluded; link term includes base stream plus scheduler steal overhead
batch1_decode32 | S0 | central | 183 | 999751680 | 999751680.000 | 1003000416.000 | 0.000 | 1003000416.000 | 0.004998758 | 0.410828970 | 0.101550948 | 0.517378677 | 0.002827205886 | 0.403688313 | 0.208859725326 | 2.477158659 | graph-derived-counts+hybrid-latency+analytical-energy | dynamic READ+ACT+PRE estimate only; refresh, idle, controller, PHY, and board power excluded; link term includes base stream plus scheduler steal overhead
batch1_decode32 | S0 | high | 183 | 999751680 | 999751680.000 | 1003000416.000 | 0.000 | 1003000416.000 | 0.014996275 | 0.962880399 | 0.121911126 | 1.099787800 | 0.006009769400 | 0.403688313 | 0.443971481662 | 2.477158659 | graph-derived-counts+hybrid-latency+analytical-energy | dynamic READ+ACT+PRE estimate only; refresh, idle, controller, PHY, and board power excluded; link term includes base stream plus scheduler steal overhead
batch1_decode32 | S0-physical | low | 183 | 999751680 | 999751680.000 | 1003000416.000 | 0.000 | 1003000416.000 | 0.000999752 | 0.192576080 | 0.081316716 | 0.274892548 | 0.001502145070 | 0.403689054 | 0.110971112720 | 2.477154109 | graph-derived-counts+hybrid-latency+analytical-energy | dynamic READ+ACT+PRE estimate only; refresh, idle, controller, PHY, and board power excluded; link term includes base stream plus scheduler steal overhead
batch1_decode32 | S0-physical | central | 183 | 999751680 | 999751680.000 | 1003000416.000 | 0.000 | 1003000416.000 | 0.004998758 | 0.410828970 | 0.101550948 | 0.517378677 | 0.002827205886 | 0.403689054 | 0.208860108995 | 2.477154109 | graph-derived-counts+hybrid-latency+analytical-energy | dynamic READ+ACT+PRE estimate only; refresh, idle, controller, PHY, and board power excluded; link term includes base stream plus scheduler steal overhead
batch1_decode32 | S0-physical | high | 183 | 999751680 | 999751680.000 | 1003000416.000 | 0.000 | 1003000416.000 | 0.014996275 | 0.962880399 | 0.121911126 | 1.099787800 | 0.006009769400 | 0.403689054 | 0.443972297224 | 2.477154109 | graph-derived-counts+hybrid-latency+analytical-energy | dynamic READ+ACT+PRE estimate only; refresh, idle, controller, PHY, and board power excluded; link term includes base stream plus scheduler steal overhead
batch1_decode32 | S1 | low | 183 | 999751680 | 999751680.000 | 1003000416.000 | 0.000 | 1003000416.000 | 0.000999752 | 0.192576080 | 0.081316716 | 0.274892548 | 0.001502145070 | 0.434095253 | 0.119329549993 | 2.303641871 | graph-derived-counts+hybrid-latency+analytical-energy | dynamic READ+ACT+PRE estimate only; refresh, idle, controller, PHY, and board power excluded; link term includes base stream plus scheduler steal overhead
batch1_decode32 | S1 | central | 183 | 999751680 | 999751680.000 | 1003000416.000 | 0.000 | 1003000416.000 | 0.004998758 | 0.410828970 | 0.101550948 | 0.517378677 | 0.002827205886 | 0.434095253 | 0.224591627558 | 2.303641871 | graph-derived-counts+hybrid-latency+analytical-energy | dynamic READ+ACT+PRE estimate only; refresh, idle, controller, PHY, and board power excluded; link term includes base stream plus scheduler steal overhead
batch1_decode32 | S1 | high | 183 | 999751680 | 999751680.000 | 1003000416.000 | 0.000 | 1003000416.000 | 0.014996275 | 0.962880399 | 0.121911126 | 1.099787800 | 0.006009769400 | 0.434095253 | 0.477412662975 | 2.303641871 | graph-derived-counts+hybrid-latency+analytical-energy | dynamic READ+ACT+PRE estimate only; refresh, idle, controller, PHY, and board power excluded; link term includes base stream plus scheduler steal overhead
batch1_decode32 | S2 | low | 183 | 999751680 | 999751680.000 | 1003000416.000 | 152268756.000 | 1155269172.000 | 0.000999752 | 0.221811681 | 0.081316716 | 0.304128149 | 0.001661902453 | 0.408103690 | 0.124115819760 | 2.450357654 | graph-derived-counts+hybrid-latency+analytical-energy | dynamic READ+ACT+PRE estimate only; refresh, idle, controller, PHY, and board power excluded; link term includes base stream plus scheduler steal overhead
batch1_decode32 | S2 | central | 183 | 999751680 | 999751680.000 | 1003000416.000 | 152268756.000 | 1155269172.000 | 0.004998758 | 0.473198253 | 0.101550948 | 0.579747960 | 0.003168021637 | 0.408103690 | 0.236597281467 | 2.450357654 | graph-derived-counts+hybrid-latency+analytical-energy | dynamic READ+ACT+PRE estimate only; refresh, idle, controller, PHY, and board power excluded; link term includes base stream plus scheduler steal overhead
batch1_decode32 | S2 | high | 183 | 999751680 | 999751680.000 | 1003000416.000 | 152268756.000 | 1155269172.000 | 0.014996275 | 1.109058405 | 0.121911126 | 1.245965806 | 0.006808556317 | 0.408103690 | 0.508483242798 | 2.450357654 | graph-derived-counts+hybrid-latency+analytical-energy | dynamic READ+ACT+PRE estimate only; refresh, idle, controller, PHY, and board power excluded; link term includes base stream plus scheduler steal overhead
batch1_decode32 | S3 | low | 183 | 999751680 | 999751680.000 | 1003000416.000 | 88806088.000 | 1091806504.000 | 0.000999752 | 0.209626849 | 0.081316716 | 0.291943317 | 0.001595318671 | 0.402658253 | 0.117553385951 | 2.483495600 | graph-derived-counts+hybrid-latency+analytical-energy | dynamic READ+ACT+PRE estimate only; refresh, idle, controller, PHY, and board power excluded; link term includes base stream plus scheduler steal overhead
batch1_decode32 | S3 | central | 183 | 999751680 | 999751680.000 | 1003000416.000 | 88806088.000 | 1091806504.000 | 0.004998758 | 0.447203944 | 0.101550948 | 0.553753651 | 0.003025976234 | 0.402658253 | 0.222973477753 | 2.483495600 | graph-derived-counts+hybrid-latency+analytical-energy | dynamic READ+ACT+PRE estimate only; refresh, idle, controller, PHY, and board power excluded; link term includes base stream plus scheduler steal overhead
batch1_decode32 | S3 | high | 183 | 999751680 | 999751680.000 | 1003000416.000 | 88806088.000 | 1091806504.000 | 0.014996275 | 1.048134244 | 0.121911126 | 1.185041645 | 0.006475637403 | 0.402658253 | 0.477166798683 | 2.483495600 | graph-derived-counts+hybrid-latency+analytical-energy | dynamic READ+ACT+PRE estimate only; refresh, idle, controller, PHY, and board power excluded; link term includes base stream plus scheduler steal overhead
batch1_decode32 | Oracle | low | 183 | 999751680 | 999751680.000 | 1003000416.000 | 0.000 | 1003000416.000 | 0.000999752 | 0.192576080 | 0.081316716 | 0.274892548 | 0.001502145070 | 0.369347206 | 0.101530794377 | 2.707479534 | graph-derived-counts+hybrid-latency+analytical-energy | dynamic READ+ACT+PRE estimate only; refresh, idle, controller, PHY, and board power excluded; link term includes base stream plus scheduler steal overhead
batch1_decode32 | Oracle | central | 183 | 999751680 | 999751680.000 | 1003000416.000 | 0.000 | 1003000416.000 | 0.004998758 | 0.410828970 | 0.101550948 | 0.517378677 | 0.002827205886 | 0.369347206 | 0.191092368636 | 2.707479534 | graph-derived-counts+hybrid-latency+analytical-energy | dynamic READ+ACT+PRE estimate only; refresh, idle, controller, PHY, and board power excluded; link term includes base stream plus scheduler steal overhead
batch1_decode32 | Oracle | high | 183 | 999751680 | 999751680.000 | 1003000416.000 | 0.000 | 1003000416.000 | 0.014996275 | 0.962880399 | 0.121911126 | 1.099787800 | 0.006009769400 | 0.369347206 | 0.406203550758 | 2.707479534 | graph-derived-counts+hybrid-latency+analytical-energy | dynamic READ+ACT+PRE estimate only; refresh, idle, controller, PHY, and board power excluded; link term includes base stream plus scheduler steal overhead

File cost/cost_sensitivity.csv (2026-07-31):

architecture | capacity_gib_binary | capacity_gb_decimal | channels | ranks_per_channel | 8gbit_x8_package_count | 4gbit_physical_die_count | price_case | delivery_case | unit_package_price_usd | imputed_physical_die_price_usd | total_dram_package_cost_usd | total_imputed_physical_die_cost_usd | capacity_gib_per_dram_die_dollar | capacity_gb_decimal_per_dram_die_dollar | pin_rate_ceiling_gbs | assumed_delivery_efficiency | modeled_effective_gbs | effective_gbs_per_dram_die_dollar | evidence_type
8GB_4ch_x16_1rank | 8 | 8.590 | 4 | 1 | 8 | 16 | low_snapshot | low_delivery | 39.32 | 19.66 | 314.56 | 314.56 | 0.025432 | 0.027308 | 6.400 | 0.50 | 3.200 | 0.010173 | analytical-cost-sensitivity
8GB_4ch_x16_1rank | 8 | 8.590 | 4 | 1 | 8 | 16 | low_snapshot | central_delivery | 39.32 | 19.66 | 314.56 | 314.56 | 0.025432 | 0.027308 | 6.400 | 0.70 | 4.480 | 0.014242 | analytical-cost-sensitivity
8GB_4ch_x16_1rank | 8 | 8.590 | 4 | 1 | 8 | 16 | low_snapshot | high_delivery | 39.32 | 19.66 | 314.56 | 314.56 | 0.025432 | 0.027308 | 6.400 | 0.85 | 5.440 | 0.017294 | analytical-cost-sensitivity
8GB_4ch_x16_1rank | 8 | 8.590 | 4 | 1 | 8 | 16 | midpoint_sensitivity | low_delivery | 68.21 | 34.10 | 545.68 | 545.68 | 0.014661 | 0.015742 | 6.400 | 0.50 | 3.200 | 0.005864 | analytical-cost-sensitivity
8GB_4ch_x16_1rank | 8 | 8.590 | 4 | 1 | 8 | 16 | midpoint_sensitivity | central_delivery | 68.21 | 34.10 | 545.68 | 545.68 | 0.014661 | 0.015742 | 6.400 | 0.70 | 4.480 | 0.008210 | analytical-cost-sensitivity
8GB_4ch_x16_1rank | 8 | 8.590 | 4 | 1 | 8 | 16 | midpoint_sensitivity | high_delivery | 68.21 | 34.10 | 545.68 | 545.68 | 0.014661 | 0.015742 | 6.400 | 0.85 | 5.440 | 0.009969 | analytical-cost-sensitivity
8GB_4ch_x16_1rank | 8 | 8.590 | 4 | 1 | 8 | 16 | high_snapshot | low_delivery | 97.10 | 48.55 | 776.80 | 776.80 | 0.010299 | 0.011058 | 6.400 | 0.50 | 3.200 | 0.004119 | analytical-cost-sensitivity
8GB_4ch_x16_1rank | 8 | 8.590 | 4 | 1 | 8 | 16 | high_snapshot | central_delivery | 97.10 | 48.55 | 776.80 | 776.80 | 0.010299 | 0.011058 | 6.400 | 0.70 | 4.480 | 0.005767 | analytical-cost-sensitivity
8GB_4ch_x16_1rank | 8 | 8.590 | 4 | 1 | 8 | 16 | high_snapshot | high_delivery | 97.10 | 48.55 | 776.80 | 776.80 | 0.010299 | 0.011058 | 6.400 | 0.85 | 5.440 | 0.007003 | analytical-cost-sensitivity
16GB_4ch_x16_2rank | 16 | 17.180 | 4 | 2 | 16 | 32 | low_snapshot | low_delivery | 39.32 | 19.66 | 629.12 | 629.12 | 0.025432 | 0.027308 | 6.400 | 0.50 | 3.200 | 0.005086 | analytical-cost-sensitivity
16GB_4ch_x16_2rank | 16 | 17.180 | 4 | 2 | 16 | 32 | low_snapshot | central_delivery | 39.32 | 19.66 | 629.12 | 629.12 | 0.025432 | 0.027308 | 6.400 | 0.70 | 4.480 | 0.007121 | analytical-cost-sensitivity
16GB_4ch_x16_2rank | 16 | 17.180 | 4 | 2 | 16 | 32 | low_snapshot | high_delivery | 39.32 | 19.66 | 629.12 | 629.12 | 0.025432 | 0.027308 | 6.400 | 0.85 | 5.440 | 0.008647 | analytical-cost-sensitivity
16GB_4ch_x16_2rank | 16 | 17.180 | 4 | 2 | 16 | 32 | midpoint_sensitivity | low_delivery | 68.21 | 34.10 | 1091.36 | 1091.36 | 0.014661 | 0.015742 | 6.400 | 0.50 | 3.200 | 0.002932 | analytical-cost-sensitivity
16GB_4ch_x16_2rank | 16 | 17.180 | 4 | 2 | 16 | 32 | midpoint_sensitivity | central_delivery | 68.21 | 34.10 | 1091.36 | 1091.36 | 0.014661 | 0.015742 | 6.400 | 0.70 | 4.480 | 0.004105 | analytical-cost-sensitivity
16GB_4ch_x16_2rank | 16 | 17.180 | 4 | 2 | 16 | 32 | midpoint_sensitivity | high_delivery | 68.21 | 34.10 | 1091.36 | 1091.36 | 0.014661 | 0.015742 | 6.400 | 0.85 | 5.440 | 0.004985 | analytical-cost-sensitivity
16GB_4ch_x16_2rank | 16 | 17.180 | 4 | 2 | 16 | 32 | high_snapshot | low_delivery | 97.10 | 48.55 | 1553.60 | 1553.60 | 0.010299 | 0.011058 | 6.400 | 0.50 | 3.200 | 0.002060 | analytical-cost-sensitivity
16GB_4ch_x16_2rank | 16 | 17.180 | 4 | 2 | 16 | 32 | high_snapshot | central_delivery | 97.10 | 48.55 | 1553.60 | 1553.60 | 0.010299 | 0.011058 | 6.400 | 0.70 | 4.480 | 0.002884 | analytical-cost-sensitivity
16GB_4ch_x16_2rank | 16 | 17.180 | 4 | 2 | 16 | 32 | high_snapshot | high_delivery | 97.10 | 48.55 | 1553.60 | 1553.60 | 0.010299 | 0.011058 | 6.400 | 0.85 | 5.440 | 0.003502 | analytical-cost-sensitivity

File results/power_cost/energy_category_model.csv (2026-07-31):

scenario | domain | category | unit | input_value | input_unit | energy_j | evidence_type | source_or_formula
low | compute | INT8_MAC | per_1e9_MAC | 1.000 | pJ/MAC | 0.001000000 | analytical-range | 1e9 MAC * scenario pJ/MAC; no Vivado power result
low | link | serialized_payload | per_GiB_transport | 24.000 | pJ/bit | 0.206158430 | analytical-range | GiB*8*pJ/bit; coding/idle/retry must be added by trace
low | DRAM | ACT | per_command_per_x8_die | 0.800 | corner_multiplier | 0.000000000643 | analytical-command-model | VDD*incremental_IDD*command_cycles*tCK; configs/dram/ddr3l_4gb_x8_1600.ini
low | DRAM | PRE | per_command_per_x8_die | 0.800 | corner_multiplier | 0.000000000342 | analytical-command-model | VDD*incremental_IDD*command_cycles*tCK; configs/dram/ddr3l_4gb_x8_1600.ini
low | DRAM | READ | per_command_per_x8_die | 0.800 | corner_multiplier | 0.000000000643 | analytical-command-model | VDD*incremental_IDD*command_cycles*tCK; configs/dram/ddr3l_4gb_x8_1600.ini
low | DRAM | WRITE | per_command_per_x8_die | 0.800 | corner_multiplier | 0.000000000470 | analytical-command-model | VDD*incremental_IDD*command_cycles*tCK; configs/dram/ddr3l_4gb_x8_1600.ini
low | DRAM | REFRESH | per_command_per_x8_die | 0.800 | corner_multiplier | 0.000000057002 | analytical-command-model | VDD*incremental_IDD*command_cycles*tCK; configs/dram/ddr3l_4gb_x8_1600.ini
low | DRAM | idle_precharged | per_cycle_per_x8_die | 0.800 | corner_multiplier | 0.000000000043 | analytical-command-model | VDD*incremental_IDD*command_cycles*tCK; configs/dram/ddr3l_4gb_x8_1600.ini
low | DRAM | idle_active | per_cycle_per_x8_die | 0.800 | corner_multiplier | 0.000000000051 | analytical-command-model | VDD*incremental_IDD*command_cycles*tCK; configs/dram/ddr3l_4gb_x8_1600.ini
central | compute | INT8_MAC | per_1e9_MAC | 5.000 | pJ/MAC | 0.005000000 | analytical-range | 1e9 MAC * scenario pJ/MAC; no Vivado power result
central | link | serialized_payload | per_GiB_transport | 51.200 | pJ/bit | 0.439804651 | analytical-range | GiB*8*pJ/bit; coding/idle/retry must be added by trace
central | DRAM | ACT | per_command_per_x8_die | 1.000 | corner_multiplier | 0.000000000803 | analytical-command-model | VDD*incremental_IDD*command_cycles*tCK; configs/dram/ddr3l_4gb_x8_1600.ini
central | DRAM | PRE | per_command_per_x8_die | 1.000 | corner_multiplier | 0.000000000427 | analytical-command-model | VDD*incremental_IDD*command_cycles*tCK; configs/dram/ddr3l_4gb_x8_1600.ini
central | DRAM | READ | per_command_per_x8_die | 1.000 | corner_multiplier | 0.000000000803 | analytical-command-model | VDD*incremental_IDD*command_cycles*tCK; configs/dram/ddr3l_4gb_x8_1600.ini
central | DRAM | WRITE | per_command_per_x8_die | 1.000 | corner_multiplier | 0.000000000587 | analytical-command-model | VDD*incremental_IDD*command_cycles*tCK; configs/dram/ddr3l_4gb_x8_1600.ini
central | DRAM | REFRESH | per_command_per_x8_die | 1.000 | corner_multiplier | 0.000000071253 | analytical-command-model | VDD*incremental_IDD*command_cycles*tCK; configs/dram/ddr3l_4gb_x8_1600.ini
central | DRAM | idle_precharged | per_cycle_per_x8_die | 1.000 | corner_multiplier | 0.000000000054 | analytical-command-model | VDD*incremental_IDD*command_cycles*tCK; configs/dram/ddr3l_4gb_x8_1600.ini
central | DRAM | idle_active | per_cycle_per_x8_die | 1.000 | corner_multiplier | 0.000000000064 | analytical-command-model | VDD*incremental_IDD*command_cycles*tCK; configs/dram/ddr3l_4gb_x8_1600.ini
high | compute | INT8_MAC | per_1e9_MAC | 15.000 | pJ/MAC | 0.015000000 | analytical-range | 1e9 MAC * scenario pJ/MAC; no Vivado power result
high | link | serialized_payload | per_GiB_transport | 120.000 | pJ/bit | 1.030792151 | analytical-range | GiB*8*pJ/bit; coding/idle/retry must be added by trace
high | DRAM | ACT | per_command_per_x8_die | 1.200 | corner_multiplier | 0.000000000964 | analytical-command-model | VDD*incremental_IDD*command_cycles*tCK; configs/dram/ddr3l_4gb_x8_1600.ini
high | DRAM | PRE | per_command_per_x8_die | 1.200 | corner_multiplier | 0.000000000512 | analytical-command-model | VDD*incremental_IDD*command_cycles*tCK; configs/dram/ddr3l_4gb_x8_1600.ini
high | DRAM | READ | per_command_per_x8_die | 1.200 | corner_multiplier | 0.000000000964 | analytical-command-model | VDD*incremental_IDD*command_cycles*tCK; configs/dram/ddr3l_4gb_x8_1600.ini
high | DRAM | WRITE | per_command_per_x8_die | 1.200 | corner_multiplier | 0.000000000705 | analytical-command-model | VDD*incremental_IDD*command_cycles*tCK; configs/dram/ddr3l_4gb_x8_1600.ini
high | DRAM | REFRESH | per_command_per_x8_die | 1.200 | corner_multiplier | 0.000000085504 | analytical-command-model | VDD*incremental_IDD*command_cycles*tCK; configs/dram/ddr3l_4gb_x8_1600.ini
high | DRAM | idle_precharged | per_cycle_per_x8_die | 1.200 | corner_multiplier | 0.000000000065 | analytical-command-model | VDD*incremental_IDD*command_cycles*tCK; configs/dram/ddr3l_4gb_x8_1600.ini
high | DRAM | idle_active | per_cycle_per_x8_die | 1.200 | corner_multiplier | 0.000000000077 | analytical-command-model | VDD*incremental_IDD*command_cycles*tCK; configs/dram/ddr3l_4gb_x8_1600.ini

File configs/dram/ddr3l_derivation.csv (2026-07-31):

rate_mtps | section | key | result_value | resulting_ini_line | source_kind | source_identity | source_reference | source_column | source_value | source_unit | derivation
800 | dram_structure | protocol | DDR3 | protocol = DDR3 | datasheet | aa71e4a25901da402147abc017818e5d52fa214c88d73f6090c229edd558be7b | Description p.1 | DDR3L SDRAM | device family | declared | direct protocol family; result DDR3
800 | dram_structure | bankgroups | 1 | bankgroups = 1 | dramsim3 | 29817593b3389f1337235d63cac515024ab8fd6e | pinned DRAMsim3 DDR3 configuration semantics | DDR3 bankgroups representation | configured | declared | DDR3 has no bank-group address; encode one group; result 1
800 | dram_structure | banks_per_group | 8 | banks_per_group = 8 | datasheet | aa71e4a25901da402147abc017818e5d52fa214c88d73f6090c229edd558be7b | Micron Table 2, Bank address row | 512 Meg x 8 | 8 banks | declared | direct x8 bank count; result 8
800 | dram_structure | rows | 65536 | rows = 65536 | datasheet | aa71e4a25901da402147abc017818e5d52fa214c88d73f6090c229edd558be7b | Micron Table 2, Row address row | 512 Meg x 8 | 64K (A[15:0]) | declared | 64K = 65536 rows; result 65536
800 | dram_structure | columns | 1024 | columns = 1024 | datasheet | aa71e4a25901da402147abc017818e5d52fa214c88d73f6090c229edd558be7b | Micron Table 2, Column address row | 512 Meg x 8 | 1K (A[9:0]) | declared | 1K = 1024 columns; result 1024
800 | dram_structure | device_width | 8 | device_width = 8 | datasheet | aa71e4a25901da402147abc017818e5d52fa214c88d73f6090c229edd558be7b | Micron Table 2, Configuration row | 512 Meg x 8 | 64 Meg x 8 x 8 banks | declared | direct x8 device width; result 8
800 | dram_structure | BL | 8 | BL = 8 | datasheet | aa71e4a25901da402147abc017818e5d52fa214c88d73f6090c229edd558be7b | Features p.1, fixed burst length bullet | all configurations | fixed burst length (BL) of 8 | declared | direct BL8 feature; result 8
800 | timing | tCK | 2.5 | tCK = 2.5 | datasheet | aa71e4a25901da402147abc017818e5d52fa214c88d73f6090c229edd558be7b | Micron Table 9 (p.33), tCK row | DDR3L-800 non-E timing point | 2.5 | ns | direct selected table value
800 | timing | AL | 0 | AL = 0 | scientific_contract | 4a57c1278e4ff074cba471dd401669e07f1e9d50c8c94f42318a61d9336a52ff | controlled DDR3L geometry/profile controls | all rates | 0 | configured | locked additive latency
800 | timing | CL | 6 | CL = 6 | datasheet | aa71e4a25901da402147abc017818e5d52fa214c88d73f6090c229edd558be7b | Micron Table 9 (p.33), CL row | DDR3L-800 non-E timing point | 6 | CK | direct selected table value
800 | timing | CWL | 5 | CWL = 5 | datasheet | aa71e4a25901da402147abc017818e5d52fa214c88d73f6090c229edd558be7b | Micron Table 53 backward-compatible 800 point (pp.78–80), CWL row | DDR3L-800 | 5 | CK | direct supported CWL at selected CL/tCK
800 | timing | tRCD | 6 | tRCD = 6 | datasheet | aa71e4a25901da402147abc017818e5d52fa214c88d73f6090c229edd558be7b | Micron Table 9 (p.33), tRCD row | DDR3L-800 non-E timing point | 6 | CK | direct selected table value
800 | timing | tRP | 6 | tRP = 6 | datasheet | aa71e4a25901da402147abc017818e5d52fa214c88d73f6090c229edd558be7b | Micron Table 9 (p.33), tRP row | DDR3L-800 non-E timing point | 6 | CK | direct selected table value
800 | timing | tRAS | 15 | tRAS = 15 | datasheet | aa71e4a25901da402147abc017818e5d52fa214c88d73f6090c229edd558be7b | Micron Table 9 (p.33), tRAS row | DDR3L-800 non-E timing point | 15 | CK | direct selected table value
800 | timing | tRFC | 104 | tRFC = 104 | datasheet | aa71e4a25901da402147abc017818e5d52fa214c88d73f6090c229edd558be7b | Micron Table 9 (p.33), tRFC 4Gb row | DDR3L-800 non-E timing point | 104 | CK | direct selected table value
800 | timing | tRFC2 | 104 | tRFC2 = 104 | dramsim3 | 29817593b3389f1337235d63cac515024ab8fd6e | pinned DRAMsim3 DDR3 configuration semantics | timing | 104 | configured | DDR3 has no fine-granularity refresh; copy tRFC
800 | timing | tRFC4 | 104 | tRFC4 = 104 | dramsim3 | 29817593b3389f1337235d63cac515024ab8fd6e | pinned DRAMsim3 DDR3 configuration semantics | timing | 104 | configured | DDR3 has no fine-granularity refresh; copy tRFC
800 | timing | REFI | 3120 | REFI = 3120 | datasheet | aa71e4a25901da402147abc017818e5d52fa214c88d73f6090c229edd558be7b | Micron Table 58 (pp.83–91), REFI row | DDR3L-800 | 7.8 | us | 7800 ns / tCK; exact integer for locked rational tCK = 3120 CK
800 | timing | tRPRE | 0 | tRPRE = 0 | dramsim3 | 29817593b3389f1337235d63cac515024ab8fd6e | pinned DRAMsim3 DDR3 configuration semantics | timing | 0 | configured | DDR3 parser-required non-DDR4 placeholder
800 | timing | tWPRE | 0 | tWPRE = 0 | dramsim3 | 29817593b3389f1337235d63cac515024ab8fd6e | pinned DRAMsim3 DDR3 configuration semantics | timing | 0 | configured | DDR3 parser-required non-DDR4 placeholder
800 | timing | tRRD_S | 4 | tRRD_S = 4 | datasheet | aa71e4a25901da402147abc017818e5d52fa214c88d73f6090c229edd558be7b | Micron Table 9 (p.33), tRRD x4/x8 row | DDR3L-800 non-E timing point | 4 | CK | direct selected table value
800 | timing | tRRD_L | 4 | tRRD_L = 4 | datasheet | aa71e4a25901da402147abc017818e5d52fa214c88d73f6090c229edd558be7b | Micron Table 9 (p.33), tRRD x4/x8 row | DDR3L-800 non-E timing point | 4 | CK | direct selected table value
800 | timing | tWTR_S | 4 | tWTR_S = 4 | datasheet | aa71e4a25901da402147abc017818e5d52fa214c88d73f6090c229edd558be7b | Micron Table 58 (pp.83–91), tWTR_S row | DDR3L-800 | greater of 4 CK or 7.5 ns | CK/ns | max(4 CK, ceil(7.5 ns / tCK)) = 4 CK
800 | timing | tWTR_L | 4 | tWTR_L = 4 | datasheet | aa71e4a25901da402147abc017818e5d52fa214c88d73f6090c229edd558be7b | Micron Table 58 (pp.83–91), tWTR_L row | DDR3L-800 | greater of 4 CK or 7.5 ns | CK/ns | max(4 CK, ceil(7.5 ns / tCK)) = 4 CK
800 | timing | tFAW | 16 | tFAW = 16 | datasheet | aa71e4a25901da402147abc017818e5d52fa214c88d73f6090c229edd558be7b | Micron Table 9 (p.33), tFAW x4/x8 row | DDR3L-800 non-E timing point | 16 | CK | direct selected table value
800 | timing | tWR | 6 | tWR = 6 | datasheet | aa71e4a25901da402147abc017818e5d52fa214c88d73f6090c229edd558be7b | Micron Table 58 (pp.83–91), tWR row | DDR3L-800 | 15 | ns | ceil(15 ns / tCK) = 6 CK
800 | timing | tWR2 | 6 | tWR2 = 6 | datasheet | aa71e4a25901da402147abc017818e5d52fa214c88d73f6090c229edd558be7b | Micron Table 58 (pp.83–91), tWR2 row | DDR3L-800 | 15 | ns | ceil(15 ns / tCK) = 6 CK
800 | timing | tRTP | 4 | tRTP = 4 | datasheet | aa71e4a25901da402147abc017818e5d52fa214c88d73f6090c229edd558be7b | Micron Table 58 (pp.83–91), tRTP row | DDR3L-800 | greater of 4 CK or 7.5 ns | CK/ns | max(4 CK, ceil(7.5 ns / tCK)) = 4 CK
800 | timing | tCCD_S | 4 | tCCD_S = 4 | datasheet | aa71e4a25901da402147abc017818e5d52fa214c88d73f6090c229edd558be7b | Micron Table 58 (pp.83–91), tCCD_S row | DDR3L-800 | 4 | CK | 4 CK = 4 CK
800 | timing | tCCD_L | 4 | tCCD_L = 4 | datasheet | aa71e4a25901da402147abc017818e5d52fa214c88d73f6090c229edd558be7b | Micron Table 58 (pp.83–91), tCCD_L row | DDR3L-800 | 4 | CK | 4 CK = 4 CK
800 | timing | tCKE | 3 | tCKE = 3 | datasheet | aa71e4a25901da402147abc017818e5d52fa214c88d73f6090c229edd558be7b | Micron Table 58 (pp.83–91), tCKE row | DDR3L-800 | greater of 3 CK or 7.5 ns | CK/ns | max(3 CK, ceil(rate-specific ns minimum / tCK)) = 3 CK
800 | timing | tCKESR | 4 | tCKESR = 4 | datasheet | aa71e4a25901da402147abc017818e5d52fa214c88d73f6090c229edd558be7b | Micron Table 58 (pp.83–91), tCKESR row | DDR3L-800 | tCKE (MIN) + 1 CK | CK | tCKE + 1 CK = 4 CK
800 | timing | tXS | 108 | tXS = 108 | datasheet | aa71e4a25901da402147abc017818e5d52fa214c88d73f6090c229edd558be7b | Micron Table 58 (pp.83–91), tXS row | DDR3L-800 | greater of 5 CK or tRFC + 10 ns | CK/ns | contract-conservative componentwise conversion: max(5 CK, ceil(260 ns / tCK) + ceil(10 ns / tCK)) = 108 CK
800 | timing | tXP | 3 | tXP = 3 | datasheet | aa71e4a25901da402147abc017818e5d52fa214c88d73f6090c229edd558be7b | Micron Table 58 (pp.83–91), tXP row | DDR3L-800 | greater of 3 CK or 7.5 ns | CK/ns | max(3 CK, ceil(7.5 ns / tCK)) = 3 CK
800 | timing | tRTRS | 1 | tRTRS = 1 | dramsim3 | 29817593b3389f1337235d63cac515024ab8fd6e | pinned DRAMsim3 DDR3 configuration semantics | timing | 1 | configured | DRAMsim3 DDR3 rank-to-rank switch default
800 | power | VDD | 1.35 | VDD = 1.35 | datasheet | aa71e4a25901da402147abc017818e5d52fa214c88d73f6090c229edd558be7b | Micron Table 20 (p.44), x8 IDD maximum-limits row | DDR3L-1066 x8 | 1.35 | V | direct value; the 800 operating point uses the documented 1066-device limits
800 | power | IDD0 | 44 | IDD0 = 44 | datasheet | aa71e4a25901da402147abc017818e5d52fa214c88d73f6090c229edd558be7b | Micron Table 20 (p.44), x8 IDD maximum-limits row | DDR3L-1066 x8 | 44 | mA | direct value; the 800 operating point uses the documented 1066-device limits
800 | power | IPP0 | 0.0 | IPP0 = 0.0 | dramsim3 | 29817593b3389f1337235d63cac515024ab8fd6e | pinned DRAMsim3 DDR3 configuration semantics | power | 0.0 | configured | DDR3 power-model placeholder unused by DDR3L IDD model
800 | power | IDD2P | 18 | IDD2P = 18 | datasheet | aa71e4a25901da402147abc017818e5d52fa214c88d73f6090c229edd558be7b | Micron Table 20 (p.44), x8 IDD maximum-limits row | DDR3L-1066 x8 | 18 | mA | direct value; the 800 operating point uses the documented 1066-device limits
800 | power | IDD2N | 28 | IDD2N = 28 | datasheet | aa71e4a25901da402147abc017818e5d52fa214c88d73f6090c229edd558be7b | Micron Table 20 (p.44), x8 IDD maximum-limits row | DDR3L-1066 x8 | 28 | mA | direct value; the 800 operating point uses the documented 1066-device limits
800 | power | IDD3P | 32 | IDD3P = 32 | datasheet | aa71e4a25901da402147abc017818e5d52fa214c88d73f6090c229edd558be7b | Micron Table 20 (p.44), x8 IDD maximum-limits row | DDR3L-1066 x8 | 32 | mA | direct value; the 800 operating point uses the documented 1066-device limits
800 | power | IDD3N | 32 | IDD3N = 32 | datasheet | aa71e4a25901da402147abc017818e5d52fa214c88d73f6090c229edd558be7b | Micron Table 20 (p.44), x8 IDD maximum-limits row | DDR3L-1066 x8 | 32 | mA | direct value; the 800 operating point uses the documented 1066-device limits
800 | power | IDD4W | 95 | IDD4W = 95 | datasheet | aa71e4a25901da402147abc017818e5d52fa214c88d73f6090c229edd558be7b | Micron Table 20 (p.44), x8 IDD maximum-limits row | DDR3L-1066 x8 | 95 | mA | direct value; the 800 operating point uses the documented 1066-device limits
800 | power | IDD4R | 123 | IDD4R = 123 | datasheet | aa71e4a25901da402147abc017818e5d52fa214c88d73f6090c229edd558be7b | Micron Table 20 (p.44), x8 IDD maximum-limits row | DDR3L-1066 x8 | 123 | mA | direct value; the 800 operating point uses the documented 1066-device limits
800 | power | IDD5AB | 224 | IDD5AB = 224 | datasheet | aa71e4a25901da402147abc017818e5d52fa214c88d73f6090c229edd558be7b | Micron Table 20 (p.44), x8 IDD maximum-limits row | DDR3L-1066 x8 | 224 | mA | direct value; the 800 operating point uses the documented 1066-device limits
800 | power | IDD6x | 20 | IDD6x = 20 | datasheet | aa71e4a25901da402147abc017818e5d52fa214c88d73f6090c229edd558be7b | Micron Table 20 (p.44), x8 IDD maximum-limits row | DDR3L-1066 x8 | 20 | mA | direct value; the 800 operating point uses the documented 1066-device limits
800 | system | channel_size | 8192 | channel_size = 8192 | scientific_contract | 4a57c1278e4ff074cba471dd401669e07f1e9d50c8c94f42318a61d9336a52ff | controlled DDR3L geometry/profile controls | all rates | 8192 | configured | 4Gb x8 * 8 devices per 64-bit rank * 2 ranks / 8 = 8192 MiB
800 | system | channels | 1 | channels = 1 | scientific_contract | 4a57c1278e4ff074cba471dd401669e07f1e9d50c8c94f42318a61d9336a52ff | controlled DDR3L geometry/profile controls | all rates | 1 | configured | one isolated DRAMsim3 instance per RTL channel
800 | system | bus_width | 64 | bus_width = 64 | scientific_contract | 4a57c1278e4ff074cba471dd401669e07f1e9d50c8c94f42318a61d9336a52ff | controlled DDR3L geometry/profile controls | all rates | 64 | configured | locked 64-bit channel bus
800 | system | address_mapping | rochrababgco | address_mapping = rochrababgco | scientific_contract | 4a57c1278e4ff074cba471dd401669e07f1e9d50c8c94f42318a61d9336a52ff | controlled DDR3L geometry/profile controls | all rates | rochrababgco | configured | locked DRAMsim3 mapping; RTL mapping is independently traced
800 | system | queue_structure | PER_BANK | queue_structure = PER_BANK | scientific_contract | 4a57c1278e4ff074cba471dd401669e07f1e9d50c8c94f42318a61d9336a52ff | controlled DDR3L geometry/profile controls | all rates | PER_BANK | configured | locked per-bank command queues
800 | system | refresh_policy | RANK_LEVEL_STAGGERED | refresh_policy = RANK_LEVEL_STAGGERED | scientific_contract | 4a57c1278e4ff074cba471dd401669e07f1e9d50c8c94f42318a61d9336a52ff | controlled DDR3L geometry/profile controls | all rates | RANK_LEVEL_STAGGERED | configured | locked rank-level staggered refresh
800 | system | row_buf_policy | OPEN_PAGE | row_buf_policy = OPEN_PAGE | scientific_contract | 4a57c1278e4ff074cba471dd401669e07f1e9d50c8c94f42318a61d9336a52ff | controlled DDR3L geometry/profile controls | all rates | OPEN_PAGE | configured | locked open-page policy
800 | system | cmd_queue_size | 8 | cmd_queue_size = 8 | scientific_contract | 4a57c1278e4ff074cba471dd401669e07f1e9d50c8c94f42318a61d9336a52ff | controlled DDR3L geometry/profile controls | all rates | 8 | configured | locked command queue capacity
800 | system | trans_queue_size | 32 | trans_queue_size = 32 | scientific_contract | 4a57c1278e4ff074cba471dd401669e07f1e9d50c8c94f42318a61d9336a52ff | controlled DDR3L geometry/profile controls | all rates | 32 | configured | locked transaction queue capacity
800 | other | epoch_period | 400000 | epoch_period = 400000 | dramsim3 | 29817593b3389f1337235d63cac515024ab8fd6e | pinned DRAMsim3 DDR3 configuration semantics | other | 400000 | configured | floor(1,000,000 ns / tCK) for diagnostic epochs only
800 | other | output_level | 1 | output_level = 1 | dramsim3 | 29817593b3389f1337235d63cac515024ab8fd6e | pinned DRAMsim3 DDR3 configuration semantics | other | 1 | configured | locked summary output level
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

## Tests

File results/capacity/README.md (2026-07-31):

# 8 GB / 16 GB capacity analysis

`model_capacity_budget.csv` is a capacity model. It is not execution evidence.

The Gemma 3 1B row uses the nominal 1B parameter class and the official 32K
context limit. The KV upper bound uses the inspected text configuration
(26 layers, one KV head, 256 head dimension, BF16 K and V):

`26 × 1 × 256 × 2 bytes × 2(K,V) = 26 KiB/token`.

The generic 2B and 3B rows are deliberately named capacity cases. Their 32 and
48 KiB/token values are engineering sensitivities, not attributes of a selected
or executed model. INT8 and INT4 weight bytes are nominal parameter-count
arithmetic. Runtime headroom is 20% of weight storage plus 512 MiB.

`memory_scaling_options.csv` compares four-channel x16 topologies. The 8 GiB
(8.590 decimal GB) option uses eight 8Gb x8 dual-die packages; the 16 GiB
(17.180 decimal GB) option uses sixteen.
Their physical 4Gb die counts are therefore 16 and 32. A second rank doubles
capacity but does not increase the four-channel 6.4 GB/s arithmetic pin-rate
ceiling. Four-MIG and two-rank placement/timing remain blocked without Vivado.
The manufacturer's dual-die package uses two stacked x4 dies to expose one x8
package interface with one chip-select, so each package is one rank for this
capacity arithmetic.

Gemma 3 1B is the only actual target. No row claims a 2B or 3B run.

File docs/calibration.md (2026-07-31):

# Compute-cycle calibration

The controlled analytical runs use `compute_mac_per_cycle = 64`, i.e. an
abstract 64 MAC/cycle issue rate. The current
`DecodeMatVecInt8` demo has `inputDim=16`, `outputDim=4`, and `tileDim=1`.
`LegacyMatVecSpec` directly checks its 65 request-to-done cycles boundary.

| Quantity | Analytical default | RTL demo | Ratio |
|---|---:|---:|---:|
| MACs per job | 64 | 64 | 1× |
| Accounted cycles per job | 1 | 65 | 65× |
| Effective MAC/cycle | 64.000 | 0.985 | 65× issue-rate gap |

This is a disclosure/calibration point, not a post-hoc rescaling of the
published scheduler tables. Existing reported analytical cycles retain their
original abstract issue-rate semantics. A physically meaningful latency claim
requires rerunning the model with a calibrated compute service and integrating
the currently absent memory/link response path.

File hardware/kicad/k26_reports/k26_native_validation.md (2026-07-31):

# K26 / XC7K160T KiCad conditional-reference validation

> **NOT FOR FABRICATION — proposal_only**

**Date:** 2026-07-31  
**Tool:** KiCad CLI 9.0.9  
**Decision:** `XC7K160T-2FFG676I — conditionally_feasible`

## Outcome

The native KiCad sources are internally consistent within their declared
coupon scope:

| Native check | Result |
|---|---:|
| Coupon ERC | 0 errors, 0 warnings |
| Hierarchical reference ERC | 0 errors, 0 warnings |
| Coupon PCB DRC | 0 violations |
| Schematic/PCB parity | 0 issues |
| Unconnected pads reported by native DRC | 0 |

This is not a ready-to-fabricate result. The coupon intentionally replaces the
K26 SOM and XC7K160T BGA with connector/bank boundaries and ignores incomplete
ratsnest connectivity outside the explicitly routed subset. `via_dangling` is
also disabled because the source contains an unfilled internal GND-zone intent;
short, clearance, track-width, drill, outline, and parity rules remain active.

## Native source counts

| Item | Count |
|---|---:|
| Hierarchical modern schematic files | 8 |
| Coupon schematic components | 29 |
| Coupon schematic nets | 116 |
| Coupon PCB footprints | 29 |
| Coupon PCB nets including net 0 | 117 |
| Routed track segments | 65 |
| Vias | 50 |
| Zones | 1 |
| Routed GTH/refclock nets | 20 |
| Generated Gerber files | 26 |
| Drill files | 1 |
| Total exported files | 36 |

The 20 routed GTH-family nets comprise four full-duplex lanes (16
single-ended P/N nets) plus two reference-clock differential pairs (4 nets).
They are geometric connectivity routes only; no impedance, insertion loss,
skew, jitter, or eye-opening claim is made.

## Implemented hierarchy

1. K26 SOM240_2 / PL GTH bank 224 connector boundary.
2. XC7K160T-2FFG676I SelectIO/GTX bank boundary.
3. Four independent DDR3L x16 channel topology, 2GB/channel proposal.
4. Four-lane full-duplex K26-to-XC7K160T link and two refclock pairs.
5. Clock, reset, and configuration boundary.
6. Power and decoupling boundary.
7. JTAG/debug boundary.

The coupon instantiates one KiCad-library Micron 96-ball DDR3L x16 component
as a representative electrical/routing slice, DDR VREF/ZQ support, +1.35V and
+3.3V decoupling subsets, link/refclock routes, and reset/JTAG boundaries.
That representative device is not asserted to be the final 2GB-channel BOM.

## Feasibility and evidence boundary

- AMD DS987 identifies the K26 device as `XCK26-SFVC784-2LV-C/I` and exposes
  four PL-GTH TX/RX lanes plus two refclock inputs through SOM240_2:
  <https://docs.amd.com/r/en-US/ds987-k26-som/SOM240_2-Connector-Pinout>.
- AMD UG475/package files show XC7K160T FFG676 has eight 50-pin SelectIO banks
  and eight GTX lanes. The official package archive is
  <https://download.amd.com/adaptive-socs-and-fpgas/developer/adaptive-socs-and-fpgas/package-pinout-files/k7packages/k7all.zip>.
- AMD UG586 permits multiple independent memory controllers but forbids bank
  sharing between controllers:
  <https://docs.amd.com/r/en-US/ug586_7Series_MIS/Bank-Sharing-Among-Controllers>.
- A four-controller placement is not proven until the exact memory
  organization is generated and placed by Vivado MIG for
  `XC7K160T-2FFG676I`.

No BGA ball, DQS byte group, VREF pin, address/control pin, GTX quad pin, or
MIG-generated constraint was invented in these files.

## Analyzer results and triage

The following analyzers were run: `analyze_schematic.py`,
`analyze_pcb.py --full`, `analyze_gerbers.py`, `cross_analysis.py`,
`analyze_emc.py`, and `analyze_thermal.py`.

- Schematic analyzer: 29 components, 116 nets. Its sourcing blocker and
  missing-datasheet warning are accepted blockers for a fabrication release;
  most entries are intentionally generic boundaries or proposal passives.
- PCB analyzer: reports 55 unrouted/error-class findings because the source
  contains a complete logical pin accounting while the PCB is deliberately a
  routed subset. These do not contradict native DRC because
  `unconnected_items` is explicitly outside coupon scope.
- Cross analysis: reports DDR/refclock return-path gaps and absent stitching.
  These remain genuine production-layout blockers. The internal plane is only
  a zone intent and no stackup-aware return-path design was performed.
- EMC analysis: score 67/100, with outer-layer refclock, connector filtering,
  stitching, and decoupling-via warnings. These are expected for the coupon
  but must not be waived on a carrier-board release.
- Gerber analyzer: two extent/alignment warnings result from exporting all
  auxiliary/user layers with different drawn extents. Native Edge.Cuts is a
  closed 140mm × 110mm outline and native DRC reports no geometry violation.
- Thermal analysis: skipped automatically because there is no complete
  production MPN/power dataset.

## Unresolved release gates

1. Generate four exact DDR3L x16 MIG instances and obtain a legal placed XDC.
2. Freeze a production-available DDR3L organization and MPN. Micron 8Gb x8
   `MT41K1G8` examples are obsolete; the clean 2×x8 single-rank topology is
   therefore not a frozen BOM.
3. Freeze GTX lane/quad/refclock assignments and verify K26 connector pins
   against the released DS987 revision.
4. Define data rate, encoding, AC coupling, refclock jitter, reset/training,
   link budget, stackup, 100-ohm routing, loss, skew, and eye-mask targets.
5. Complete every XC7K160T core/aux/I/O/GT rail, K26 carrier rail, sequencing,
   regulator, decoupling, thermal, and PDN requirement.
6. Complete configuration flash, JTAG chain, voltage domains, pull resistors,
   test points, protection, ESD, and manufacturing test strategy.
7. Replace every boundary placeholder with datasheet-checked symbols,
   footprints, manufacturer part numbers, and generated pin constraints.
8. Route the full board, refill planes, add stitching, rerun ERC/DRC/parity,
   SI/PI, timing closure, thermal, lifecycle, DFM, and physical validation.

## Not performed / review limits

- Vivado/MIG generation and placement: Vivado is unavailable on this host.
- SPICE: no `ngspice`, `xyce`, or `ltspice` executable is installed.
- Datasheet extraction: no project datasheet cache; pin-level correctness is
  not claimed beyond the cited AMD connector/package resource boundaries.
- Lifecycle audit: final MPNs do not exist, so a lifecycle result would be
  misleading.
- Prior-review delta: this is the first run of this new isolated reference.
- Field solver, SI/PI simulation, timing closure, fabrication review,
  assembly review, and laboratory measurement were not performed.

## Final verdict

The hierarchy and coupon are suitable as a reproducible **architectural
reference and routing experiment**. They are not a schematic release, PCB
release, or evidence that four MIG controllers place successfully.

**Fabrication readiness: blocked.  
Architecture status: conditionally feasible.**

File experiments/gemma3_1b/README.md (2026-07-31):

# Gemma 3 1B graph-derived evidence

This directory is generated from the hashed, read-only Gemma 3 1B ONNX
artifact recorded in `models/gemma3_1b_manifest.yaml`.

## Evidence layers

- `graph_inventory.csv`: all 7,837 ONNX nodes in execution order. Projection
  shape, initializer, dtype, external-data offset, and byte count are directly
  graph-derived.
- `projection_trace.csv`: the 183 dense projection nodes executed per decode
  token: 26 layers × (q, k, v, o, gate, up, down) plus `lm_head`.
- `token_trace.jsonl`: 32 deterministic tokenizer-derived input IDs linked to
  the projection-order hash. It is not generated text or an ORT timing trace.
- `scheduler_replay.csv`: the same projection ledger replayed for S0,
  S0-physical, S1–S3, and the offline Oracle list scheduler at decode lengths
  1 and 32. Each projection is one coarse analytical INT8 job. The Oracle row
  also carries a resource-load lower bound; its list-schedule completion time
  is not mislabeled as a mathematical optimum.
- `representative_weight_tiles.json`: bounded 16×4 reads from actual
  float32 external-data offsets for attention output, MLP gate, and `lm_head`,
  with deterministic symmetric INT8 quantization, explicit weight values, and
  software references. `representative_weight_tiles_int8.csv` is the exact
  fixture consumed by the RTL parity test.
- `trace_manifest.json`: hashes, counts, functional-reference provenance, and
  the claim boundary.

Model-level outputs are under `results/model_level/`.

## Reproduce

```bash
export GEMMA3_1B_ONNX_DIR=/authorized/read-only/path/gemma3-1B-onnx
python3 experiments/gemma3_1b/generate_trace.py
```

The committed snapshot was generated with:

```bash
python3 experiments/gemma3_1b/generate_trace.py \
  --model-dir ${GEMMA3_1B_ONNX_DIR}
```

Tests:

```bash
python3 -m pytest -q \
  experiments/gemma3_1b/tests/test_trace_generator.py
sbt -batch "testOnly varp.GemmaWeightTileRtlParitySpec"
```

## Interpretation boundary

The ONNX graph, tokenizer output, file hashes, and bounded weight bytes are
directly observed. Placement and scheduler replay are analytical. The hybrid
total combines those analytical projection cycles with the pre-existing Y700
CPU-EP non-projection measurement; it is neither a board measurement nor a
product-latency prediction. The three bounded 16×4 tiles are injected into the
actual `ComputeCluster`/`DecodeMatVecInt8` path and compared with their INT32
software references. That bounded parity result is not full-model RTL
inference or validation of the model-wide quantization policy.

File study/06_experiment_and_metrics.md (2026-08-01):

# 실험과 지표

합성 부하는 균형·편향·채널 집중·순간 집중·혼합 각 1,000개 작업과 시드
19/23/29/31/43을 사용한다. 같은 시드의 S1/S2/S3는 같은 작업 목록 해시를 가진다.

Gemma 평가는 토큰당 802개 TileJob, 보수적 단계 장벽과 토큰 직렬화를 사용한다.
기존 산술·라운드로빈·크기 균형·채널 친화 초기 배치를 비교한다.

p95와 p99는 의존성 해제 시점부터 TileJob 완료까지의 분포다. 사용자 요청 지연이나
기능적 텍스트 생성 시간이 아니다. 완료시간, 추가 링크 바이트, 원격 가중치와 함께
읽는다.

정상성 조건은 입력 ID와 완료 ID 집합 동일, duplicate 0, timeout false다.

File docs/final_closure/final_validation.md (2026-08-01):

# v11 최종 검증 기록

검증일: 2026-08-01  
브랜치: `conference-final`  
검증 기준: `v11-conference-final` 공개 기준선은 불변으로 보존하고, 16장 발표 개정은 `conference-final` 최신 커밋에서 검증

## 판정

연구 모델, 논리 RTL 경로, KiCad 제한 쿠폰, 논문, 발표, 학습자료와 공식 소스
아카이브의 로컬 품질 Gate는 **PASS**다. 과거 PDF의 GitHub 경보 #1도 저장소
소유자가 `false_positive`로 해소했고 현재 패키지 재귀 검사를 통과했다.

## 실행한 Gate

| 명령·검사 | 결과 |
|---|---|
| `make test` | PASS — Python 38개, archive 전용 1개 skip |
| `make rtl-test` 경로 | PASS — Scala/RTL 19개 |
| `make publication-index` | PASS — Figure 10개, flow 5개, 최소 환산 11.04 pt |
| `make paper` | PASS — 제출본 8쪽, 기술보고서 10쪽, 최소 Figure 글자 8.102 pt, PDF 텍스트 감사 |
| `make presentation` | PASS — 16장, 내장 영상 4개, notes 16개, 목표 590초·낭독 추정 578.0초, 최소 12 pt |
| 본선 심사 기준 Gate | PASS — 주제 이해도·전달성·질의응답·참여도 매핑, 슬라이드별 그림 순서·예상 질문·답변·주의 표현 16개 |
| `make reproduce` | PASS — 연구 동결·KiCad·논문 포함, `source_clean_gate=PASS` |
| `make release` | PASS — 공식 패키지 5종 생성 |
| `sha256sum -c release/checksums.sha256` | PASS — 5종 모두 일치 |
| `make source-archive-test` | PASS — 실제 `release/VARP_K26_Source.zip` 내부 38개 테스트·Figure 재생성·manifest 무결성 |
| `make github-archive-test` | PASS — GitHub 자동 소스 ZIP 등가 경로 |
| 독립 검토 | PASS — 가속기 기여, 인과, 한국어 가독성, 하드웨어 시각, 발표/Q&A, 최종 언어 6회 |

## 핵심 산출물

- 논문: `paper/final/submission_manuscript.pdf`
- 발표: `presentation/final/presentation.pptx`, `presentation/final/presentation.pdf`
- 발표자 노트·출처: `presentation/final/speaker_notes.md`,
  `presentation/final/slide_source_index.md`
- 연구 동결: `research/v11_research_freeze.md`
- 논리 RTL 추적: `evidence/model/gemma3_1b_closed_loop_trace.csv`
- KiCad 범위: `hardware/kicad/k26_reports/k26_scope_manifest.json`
- 학습자료: `study/study_pack.pdf`, `study/10_qna_bank.md`,
  `study/15_final_round_scoring_strategy.md`
- Release checksum: `release/checksums.sha256`

## 보안 최종 판정

현재 작업 트리·논문/PPTX/PDF와 중첩 Release 자산 949개에서 고신뢰 자격증명
패턴은 0건이다. 과거 커밋 `730a05b`의 PDF를 가리키던 GitHub 경보 #1은
2026-08-01 09:32 KST에 저장소 소유자 `snowman0919`가 `false_positive`로
해소했다. 토큰으로 표시됐던 문자열은 읽거나 문서화하지 않았다. Git 이력
force-push 없이 기존 `v11-conference-final` Release를 보존하고, 후속 발표 개정은 브랜치의 새 커밋으로만 추가한다.

## 원격 게시 감사

- Release 내용 커밋: `fe65fd6157a66e305486d8704a0da4b6eae21af2`
- Annotated tag: `v11-conference-final` — peeled commit이 내용 커밋과 일치
- 공개 Release: <https://github.com/snowman0919/varp-k26-memory-fpga/releases/tag/v11-conference-final>
- 공개 자산: 17개, GitHub SHA-256 digest와 로컬 파일 17/17 일치
- PR: <https://github.com/snowman0919/varp-k26-memory-fpga/pull/3>, Draft·mergeable
- GitHub Actions workflow: 0개
- 경보 #1: `resolved / false_positive`, resolved by `snowman0919`

`v11-conference-final`은 공개 당시의 불변 기준선이다. 이후 요청된 16장 발표 개정은
tag를 이동하지 않고 `conference-final` 브랜치에 후속 커밋으로 게시한다.

이 절은 공개 후 기록이므로 Release tag의 내용 커밋 다음 사후 감사 커밋에 보존한다.

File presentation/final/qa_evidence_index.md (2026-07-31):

# Presentation QA Evidence Index

슬라이드별 claim/source/허용·금지 해석은 [`slide_source_index.md`](slide_source_index.md)를 따른다. 객체 경계·가로/세로 overflow·텍스트 박스 교차 검사는 [`layout_audit.json`](layout_audit.json), 세 역할의 최종 검토는 [`independent_review.md`](independent_review.md), 발표 질의응답은 [`../../study/10_qna_bank.md`](../../study/10_qna_bank.md)를 사용한다.

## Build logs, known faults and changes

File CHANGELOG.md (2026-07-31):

# Changelog

## v10-submission-ready — 2026-08-01

### Release closure

- Corrected public metadata and added a reviewer-oriented landing page.
- Added GitHub auto-ZIP fallback testing alongside checksum-bound Source ZIP
  reproduction.
- Added a 10-minute presentation, Manim animations, Korean study pack, and
  claim-to-evidence release index.
- Kept analytical, hybrid, estimated, RTL, and KiCad-native evidence labels
  explicit throughout all public materials.

## 2.0.0 — public-repository cleanup

- Preserved the complete v10 evidence snapshot on `v10-final` and
  `archive/v10-full-evidence`.
- Removed revision history, rendered publication variants, raw VCD, fabrication
  exports, GUI/plugin code, and G00–G10 legacy paths from the main line.
- Restored canonical publication CSV inputs and moved all rendered output to
  ignored `build/` directories.
- Added a real `make reproduce`, deterministic release target, CI, and public
  repository contract tests.
- Documented the three independent RTL planes, absent end-to-end DDR/link data
  loop, Python/RTL scheduling mismatch, 65-cycle MatVec calibration, and
  non-runnable DRAMsim3 boundary.

## v10-final — 2026-07-31

- Added graph-derived Gemma 3 1B projection and deterministic token traces.
- Added S0-physical and offline Oracle analytical comparisons.
- Added bounded actual-weight RTL parity for three representative projections.
- Added scheduler-to-real-MatVec temporal waveform evidence.
- Added bounded power, DRAM energy, capacity, and memory-die cost models.
- Added a controlled KiCad/native/EMC/thermal evidence review.
- Added publication figures, editable flows, animation, paper, report, and
  presentation packages.
- Added evidence manifests, deterministic release archives, and clean-clone
  reproduction gates.

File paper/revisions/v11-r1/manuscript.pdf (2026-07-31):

## 온디바이스 LLM 외부 가속기를 위한 K26–Memory FPGA 다채널 메모리·Work Stealing 구조의 설계 및 가상 시제품 평가

Design and Virtual-Prototype Evaluation of a K26–Memory FPGA Multi-channel Memory and Work Stealing Architecture for On-device LLM Acceleration

최윤혁 (CHOI YUNHYUK) · 한국디지털미디어고등학교 · ORCID 0009-0006-3537-0249 2026-07-31

초록

온디바이스 LLM 복호화는 투영 가중치를 반복해서 읽으므로 정적 작업 소유권에서 생긴 큐·메모리 불균형이 꼬리 지연을 지배할 수 있다. 본 연구는 실제 Gemma 3 1B 그래프에서 작업 목록을 만들고, K26 연산 소유권과 외부 Memory FPGA의 채널 친화도를 분리한 후보 구조에서 정적 S1과 지역성 인지 워크 스틸링 S3를 동일 조건으로 감사한다. 실제 graph-derived decode-32 replay에서 S3는 S1보다 p95와 p99를 각각 15.07%와 14.61% 낮췄다. 이 replay와 분리한 1,000-job synthetic stress의 완전 중첩 서비스 모델에서는 skew와 mixed의 p95가 18.12%와 17.59% 낮아지고 S2 대비 원격 가중치 전송량이 37.84%와 22.16% 줄었지만, 순차 서비스에서는 skew의 S2/S3 순위가 뒤집혔다. Gemma 3 1B의 context-32K 용량 모델 2.4301 GiB는 명목 K26 로컬 4 GB에도 들어가므로 외부 8 GiB 채택은 용량이 아니라 로컬 메모리 대역폭· 경합·전력 검증에 달려 있으며, 본 방법은 그 채택 조건과 다음 실험을 명확히 선택하게 한다.

핵심어: Gemma 3 1B, Kria K26, Memory FPGA, 다채널 DDR3L, Work Stealing, SpinalHDL, KiCad

Abstract

On-device LLM decoding repeatedly streams projection weights, so queue and memory imbalance under static ownership can dominate tail latency. We derive a job ledger from the actual Gemma 3 1B graph and audit static S1 against locality-aware work stealing S3 on a
candidate | architecture | that | separates | K26
compute ownership from external Memory FPGA channel affinity. In the graph-derived decode-32 replay, S3 reduces p95 and p99 against S1 by 15.07% and 14.61%. In a separate 1,000-job synthetic stress under a full-overlap service model, S3 reduces p95 by 18.12% and 17.59% on skew and mixed workloads and reduces remote-weight bytes against S2 by 37.84% and 22.16%, while a sequential service boundary reverses the skew S2/S3 ordering. Because the 2.4301-GiB context-32K capacity model fits nominal K26 local 4 GB, external 8 GiB remains conditional on local-memory bandwidth, contention, and power validation; the method identifies the adoption gates and next experiments.

Keywords: Gemma 3 1B, Kria K26, Memory FPGA, multi-channel DDR3L, work stealing, SpinalHDL

I. 서론

작은 배치의 LLM 복호화는 같은 투영 가중치를 토큰마다 다시 사용한다. 이때 연산 클러스터를 여러 개 두어도 작업이 특정 클러스터나 메모리 채널에 몰리면 일부 클러스터는 놀고 다른 큐의 p95와 p99는 길어진다. 유휴 클러스터가 다른 큐의 작업을 가져오는 워크 스틸링 (work stealing)은 이를 줄일 수 있지만, 가중치와 활성값의 원격 이동을 만든다. 따라서 핵심 질문은 “스틸링이 빠른가”가 아니라 “어떤 작업을 언제 옮기면 꼬리 지연 감소가 이동 비용보다 큰가”이다.

본 연구는 이 질문을 K26–Memory FPGA 후보 구조의 채택 조건 평가로 구체화한다. K26 대상 기능 RTL은 네 연산 클러스터와 signed-INT8 MatVec primitive를 수행한다. Memory command와 link routing은 compute payload와 연결되지 않은 독립 입력 평면으로 구현되어 있다. 스케줄러는 큐 소유권을 보존하면서 작업 나이와 지역성 벌점을 계산하지만, 실제 DDR 응답을 받아 MatVec에 주입하는 end-to-end 경로는 없다.

그림 1은 구현과 제안의 경계를 포함한 현재 구조를 먼저
보여준다. | TileScheduler, | payload | store,
ComputeClusterArray와 | DecodeMatVecInt8의
compute | path는 | 연결되어 | 있다. | 반면
memoryRequest→memoryCommands와 linkInput→linkBundles는 외부 입력으로 시작하는 별도 command/routing plane이며 response, DMA sequencing, PHY 또는 compute payload store 연결이 없다. 세부 증거 등급과 허용 주장은 표 3에서 고정한다.

## Figure · Implemented RTL planes and missing end-to-end loop

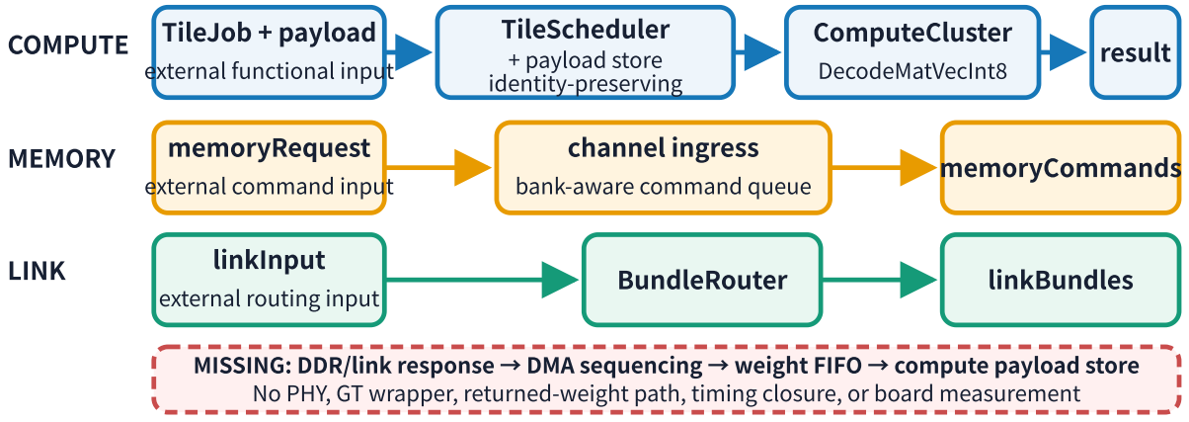
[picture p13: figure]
COMPUTE; TileJob + payload; external functional input; TileScheduler + payload store identity-preserving; ComputeCluster; DecodeMatVecInt; result; MEMORY; memoryRequest; external command input; channel ingress; bank-aware command queue; memoryCommands; LINK; linkInput; external routing input; BundleRouter; linkBundles

MISSING: DDR/link response → DMA sequencing → weight FIFO → compute payload store No PHY, GT wrapper, returned-weight path, timing closure, or board measurement

그림 1. K26 연산 RTL, 분석 서비스와 미통합 DMA/link/DDR 경계를 분리한 후보 데이터 경로. 상세 composite는 publication asset F01이다.

의사결정 사슬은 다음과 같다. 문제는 정적 home
ownership의 | 큐·채널 | 쏠림이 | 꼬리 | 지연을
만드는가이다. 후보는 K26 연산 소유권과 외부 4-channel Memory FPGA 친화도를 분리한 조건부 설계다. 정책 사다리는 S1(static local)→S2(oldest eligible steal)→S3(age+locality steal)이고, S0는 이상적 중앙 기준선이다. 결정은 S3의 조건부 꼬리 지연· 전송량 이득은 관측하되, 외부 Memory FPGA 채택과 중앙·분산 큐의 물리 우열은 로컬 메모리 및 물리 구현 기준선이 생길 때까지 보류하는 것이다.

기여는 세 가지다. (1) 실제 ONNX graph-derived 작업 목록, (2) 동일 작업 목록에서 꼬리 지연·완료 시간·원격 전송량을 함께 보는 정책 감사, (3) 제한된 RTL·물리 검증 관문과 주장 경계의 연결이다. S3 알고리즘 자체의 신규성이나 보드 성능은 주장하지 않는다.

II. 관련 연구와 차별점

PagedAttention은 | serving | 환경의 | KV-cache
paging과 | fragmentation을 | 다루고[1],
FlashAttention은 IO-aware tiling으로 attention의
memory | movement를 | 줄인다[2]. | GPTQ,
SmoothQuant와 AWQ는 저비트 양자화에서 모델
크기와 | 정확도의 | 균형을 | 연구한다[3–5]. | 이들은

memory traffic이 중요한 이유를 설명하지만, K26
cluster의 | local | queue에서 | Memory | FPGA
channel로 이동하는 TileJob의 ownership과 stealing traffic을 직접 다루지 않는다.

FTRANS, DFX와 FlightLLM은 Transformer의 FPGA mapping, multi-FPGA 확장과 end-to-end 실행을 제시했다[6–8]. 본 연구는 이들과 최고 처리량을 경쟁하지 않는다. 차별점은 실제 ONNX graph를 scheduler ledger로 연결하고, queue policy의 p95·p99, remote-weight byte, actual MatVec parity와 제한된 PCB coupon을 동일한 evidence chain에서 감사한다는 데 있다. Scheduler 결과는
physical | throughput이 | 아니라 | architecture
decision을 위한 event-driven model이다.
고전적 | work | stealing은 | dependency가 | 있는
multithreaded computation의 load balance와 이론적 bound를 제공한다[15]. LAWS는 multisocket
NUMA에서 | shared-cache와 | remote-memory
locality를 online profiling으로 조정한다[16]. 본 연구의 S3는 이 계열보다 새롭다고 주장하지 않는다. 표 1은 알고리즘 우월성이 아니라 실제 LLM 그래프→ 스케줄러→제한된 RTL·물리 관문의 추적 가능성을 비교한다.

표 1. 가장 가까운 연구와 contract-level evidence 비교

연구 | Work ownership | Data locality | Remote-byte 회계 | 실제 LLM graph | RTL 시간 증거 | Physical gate
Classic work stealing[15] | deque/task | 고려 안 함 | 통신 bound | 아니오 | 아니오 | 아니오
LAWS NUMA scheduler[16] | socket queue | profiling 기반 | remote access 최적화 | 아니오 | 아니오 | 아니오
DFX[7] | multi-FPGA static mapping | partition 기반 | inter-FPGA 설계 | 실제 model | hardware system | 본 연구와 다른 appliance
FlightLLM[8] | compiled dataflow | mapping 기반 | memory/dataflow 평가 | 실제 model | FPGA mapping | 구현 flow
본 연구 | TileJob identity | age/locality score | policy별 modeled byte | Gemma graph-derived | 세 steal→MatVec | bounded KiCad gate

표의 차이는 우월성 순위가 아니다. 본 연구는 actual
graph와 제한된 temporal/physical evidence를 하나의 claim audit에 연결하지만, non-stealing
dynamic | placement와 | 기존 | locality-aware
stealing을 동일 ledger에서 비교하지 않았다.
DRAMsim3는 | channel, | bank, | row와 | timing
constraint를 cycle 수준에서 계산한다[9]. 이 공개
저장소에는 | runnable | adapter가 | 없고
results/runs/dramsim3-
snapshot/dramsim_stats_ch4.json의 | 과거 | 4-
channel 통계 snapshot과 설정만 보존한다. 이 snapshot은 Gemma scheduler replay와 cycle-by-
cycle로 | 결합되지 | 않았고 | make | reproduce가
재생성하지 않으므로 Gemma J/token에 합산하지 않는다. KiCad ERC/DRC도 선언한 전기 규칙만 검사한다[14]. 각 산출물의 허용 범위는 표 3을 따른다.

III. 실제 Gemma 3 1B workload와 설계 목표

A. Graph-derived trace
입력 artifact는 로컬 read-only Gemma 3 1B ONNX model과 external-data file이다. ONNX와 external
data의 | SHA-256은 | 각각
e63d7c5e59f8c54a17cb7302529350a186b173701c 4809db1b4eb1fd43602ad2와
c10ce493923725d45cae3c299ba2f8b9b6fe9183d9 3e88992595dd70db4b47e5다. Graph inventory는 7,837개 node를 순서대로 보존한다. Decode token당 dense projection은 attention의 q, k, v, o 104개, MLP gate, up, down 78개, lm_head 1개로 총 183개다.

원본 float32 projection initializer는 3,999,006,720 byte다. 본 평가의 coarse INT8 배치는 이를 999,751,680 byte로 모델링한다. 여기서 context-32는 KV 과거 길이 32를 뜻하며 float32 KV cache 산술은 1,703,936 byte다. 뒤의 context-32K는 용량 모델의 KV 문맥 길이 32,768로, 32개의 생성 토큰을 뜻하는 decode-32와도 다르다.

그래프 추출 경로와 ONNX Runtime 실행 경로는
분리한다. | 전자는 | onnx.checker.check_model과
external tensor를 적재하지 않는 protobuf graph load로 node 이름·연산·shape·initializer·external-data offset을 읽는다. 후자는 Y700의 ONNX Runtime Android CPU Execution Provider에서 batch 1, sequence length 1, artificial past length 1 조건으로 측정한 세 번의 기능 참조이며 평균 wall clock은 408.445 ms였다. 이 ORT 세션은 본 평가의 decode-32 token_trace.jsonl이나 183×32 TileJob ledger를 재실행하지 않았고 RTL·DRAMsim3·가속기 시간도 아니다. 혼합 결과는 이 Y700 실행에서 분리한 비투영 시간을 투영 분석 모델과 합친 값이다. 그림 2는 hash-
bound | ONNX | artifact가 | graph | inventory와
projection ledger로 변환되는 경로, 그리고 별도 ORT 기능 참조의 경계를 함께 나타낸다.

## Figure · ONNX graph and Runtime evidence boundary

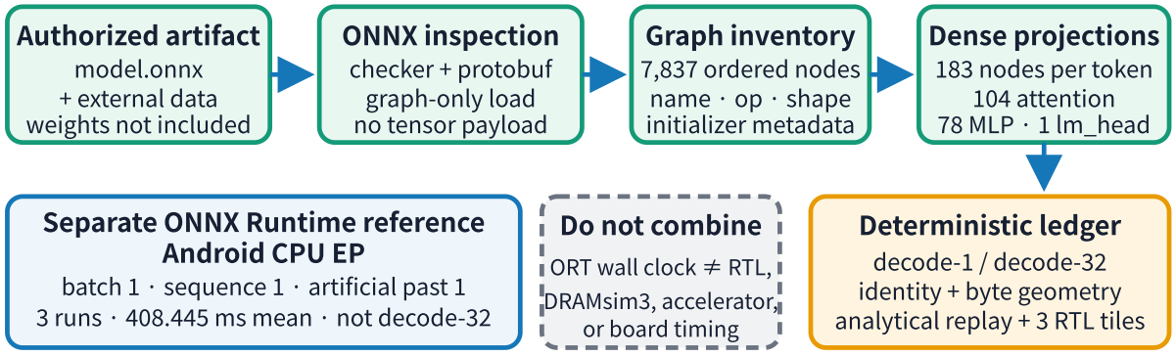
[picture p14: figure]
Authorized artifact; model.onnx + external data weights not included; ONNX inspection; checker + protobuf graph-only load no tensor payload; Graph inventory; , ordered nodes name · op · shape initializer metadata; Dense projections;  nodes per token  attention  MLP ·  lm_head; Deterministic ledger; decode- / decode- identity + byte geometry analytical replay +  RTL tiles; Separate ONNX Runtime reference Android CPU EP; Do not combine; ORT wall clock ≠ RTL,; DRAMsim, accelerator, or board timing

batch · sequence · artificial past runs · . ms mean · not decode-

Green = graph-derived · blue = host functional reference
Orange = analytical/RTL ledger boundary · gray = forbidden combination

그림 2. ONNX checker/protobuf graph inspection으로 7,837-node inventory와 token당 183개 projection ledger를 만들고, 별도의 ONNX Runtime Android CPU EP 기능 참조가 decode-32·RTL·보드 시간과 결합되지 않음을 표시한 전체 흐름.

B. 실제 weight tile과 RTL parity
Attention | output, | MLP | gate와 | lm_head
initializer에서 각각 연속된 16×4 float32 tile을 external-data offset으로 읽었다. 각 tile은 최대 절댓값을 127에 대응시키는 대칭 per-tile INT8 양자화를 적용하고 zero point를 0으로 고정했다. 입력 vector, scale, source offset과 tile hash를 fixture에
기록했다. | 세 | | fixture는 | 실제
ComputeCluster/DecodeMatVecInt8 | 경로에
주입되었고 INT32 software reference와 정확히 일치했다.

이 parity는 중요한 최소 연결 증거다. Graph의 실제 weight byte가 accelerator의 실제 signed INT8 multiplier 경로까지 도달한다. 그러나 세 개 16×4
tile만 | 검증했으므로 | model-wide | quantization
accuracy, 모든 projection의 layout, full-model inference 또는 K26 timing을 증명하지 않는다.

표 2는 실제 그래프에서 직접 얻은 값과 용량 산술·RTL 결과를 분리한다.

표 2. Gemma workload와 증거 경계

항목 | 값 | 증거 유형 | 허용되는 해석
ONNX graph node | 7,837 | graph-derived | 실제 artifact의 graph inventory
Projection/token | 183 | graph-derived | q/k/v/o, MLP 3종, lm_head 순서
Float32 projection weight | 3,999,006,720 B | graph-derived | initializer byte 합
Modeled INT8 projection weight | 999,751,680 B | capacity arithmetic | coarse resident/traffic model
실제 weight tile parity | 3/3 | RTL-simulated | 제한된 16×4 MatVec 정확성
Y700 기능 참조 | 408.445 ms 평균 | host-measured | 과거 단일-token CPU EP 조건

IV. K26–Memory FPGA 시스템

K26는 control, activation과 hot working set을 담당하고 네 compute cluster로 TileJob을 분배한다. 용량만 보면 Gemma 3 1B의 INT8 context-32K budget 2.4301 GiB는 명목 K26 local 4 GB 후보에 들어가므로 외부 8 GiB의 필요성은 capacity로 입증되지 않는다. 본 연구는 external capacity expansion, independent channel bandwidth와 weight-service isolation을 서로 다른 가설로 분리하며, K26 localmemory의 effective bandwidth·경합·전력 baseline 없이 외부 memory가 필요하다고 주장하지 않는다.

분석 모델의 TileJob은 명시적 home cluster를 가지지만 RTL TileJob은 job ID, arrival, layer/op, activation ID, weight/output address, K/N 범위,
preferred | channel·bundle, reduction | owner,
priority와 | stealable | flag를 | 가지며 jobId | %
clusterCount로 home queue를 정한다. Scheduler가 queue 간에 job을 이동해도 identity는 바뀌지 않는다. Input ID set, dispatch ID set과 completion ID set이 같고 duplicate completion이 0이어야 정상이다.

네 논리 link bundle은 serializer, credit, CDC, outstanding table, response serializer와 consumer FIFO wait를 분리해서 센다. TileJob queue와

transport | FIFO도 | 별도 | 경계다. | 전자는 | “누가
실행할지”, 후자는 “byte가 언제 이동할지”를 결정한다.
이 | 둘을 | 합치면 | queue | imbalance와 | link
backpressure의 원인을 구분할 수 없다.

표 3은 이후 모든 수치에 적용할 증거 등급, 정의와 허용 주장을 한곳에 고정한다.

표 3. 증거 등급과 허용 주장

등급 | 정의와 대표 산출물 | 허용 주장 | 금지·보류 주장
Direct | 원본 ONNX/external-data hash, host 측정, native KiCad 결과 | 해당 산출물의 node·byte·측정 조건·검사 결과 | 다른 장치 성능, 완성 보드 동작
RTL-simulated | actual Gemma tile→MatVec 3/3 parity; synthetic scheduler→payload→MatVec exact-once | 각 독립 경로의 제한된 기능·시간 동작 | 실제 Gemma가 scheduler·DMA/DDR를 통과한 end-to-end 실행
Graph-derived | graph inventory와 decode-1/decode-32 projection order·shape·byte | 실제 모델에서 유도한 작업 순서와 크기 | 실제 decode-32 ORT execution trace 또는 물리 배치
Modeled | S0–S3 event model, overlap 경계, energy·DRAM-die cost | 명시한 식 안의 p95·전송량· 민감도·정규화 | 물리 protocol timing, 전체 보드 J/token·가격; S0 0 B와 +7 cycle은 정의·한 점 민감도
Blocked | dispatch→DMA/link/DDR→MatVec release, Vivado·SI/PI·board | 다음 검증 관문 식별 | 중앙/분산 큐의 물리 우열, 제작· 실측 성능

표 4는 외부 8 GiB 후보를 용량·대역폭·격리·확장
질문으로 나눠 채택 근거의 현재 상태를 보여준다.
표 4. 외부 8 GiB 후보 설계의 가설과 판정 | 가설 | 본
논문 evidence | 판정 | |—|—|—| | Gemma 1B
capacity expansion | 2.4301 GiB at INT8 context-
32K | 불필요; nominal local 4 GB에도 fit | |
Independent channel bandwidth | 4×x16 pin-rate
산술과 analytical service | local-memory 실효
bandwidth baseline 부재 | | Weight-service
isolation | queue/channel analytical counters |
host/local contention 측정 부재 | | 3B·long-context
확장 | generic capacity arithmetic | 실행 증거 아님 |
외부 메모리 baseline은 네 개의 x16 channel이다. 각 channel은 8 Gb x8 package 두 개로 2 GiB를 구성하고 전체 8 GiB가 된다. 분석 부품 AS4C1G8D3LA-10BCN은 package 내부에 두 개의 4 Gb x4 die가 적층되어 하나의 x8 rank로 보인다. 800 MT/s 가정의 산술 pin-rate 상한은 4×16×800/8 = 6.4 GB/s다.
Effective | payload는 | controller, | refresh,
turnaround와 protocol overhead 때문에 더 낮다.
V. Multi-Queue FCFS와 지역성 인지 Work Stealing

S0는 idealized global FIFO다. 빈 cluster가 central queue에서 다음 job을 가져가므로 imbalance의 낮은 기준을 주지만 global arbitration, fanout과 crossbar 비용을 단순화한다. S0-physical은 central control cycle을 추가한 분석 모델이다. S1은 home cluster의 local FIFO에서만 실행한다. S2는 idle cluster가 oldest eligible job을 훔친다. S3는 age에서 remote
weight, | activation | residency, | reduction
ownership과 bundle mismatch penalty를 뺀 locality score가 양수인 job을 선택한다. Oracle은 전체 ledger를 미리 아는 offline list scheduler이며 수학적으로 증명된 optimum이 아니다.
그림 | 3은 | S3의 | victim | 탐색부터 | exact-once
completion까지 | 정책 | 순서를 | 보여준다. | 유휴
클러스터는 local queue가 빈 것을 확인하고 victim을
탐색한다. | 작업이 | stealable하고 | dependency가
준비되었는지 검사한 다음 age/locality score를 계산한다. 분석 모델에서는 선택된 작업을 원격 요청과 전송량으로 회계하며, 계측 RTL에서는 dispatch identity가 actual MatVec까지 보존된다.

## Figure · S → S → S policy ladder and evidence boundary

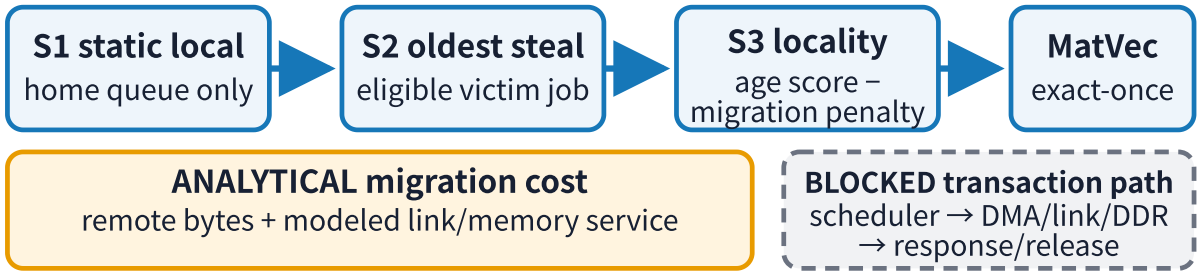
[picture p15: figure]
S static local; home queue only; S oldest steal; eligible victim job; S locality age score − migration penalty; MatVec; exact-once; ANALYTICAL migration cost; BLOCKED transaction path scheduler → DMA/link/DDR → response/release

remote bytes + modeled link/memory service

Blue = RTL decision/dispatch/MatVec · orange = analytical migration cost Gray dashed = remote-weight transaction path not integrated

그림 3. S1→S2→S3 정책 사다리와 RTL dispatch, 분석 migration cost, 미통합 DMA/link/DDR 경계. 상세 composite는 publication asset F02다.

S3는 | 보편적으로 | 우월하도록 | 설계되지 | 않았다.
Balanced workload에서는 이동할 필요가 없고,
hotspot은 memory channel 자체가 병목일 수 있다. Remote weight가 큰 job은 S2보다 덜 옮겨 traffic을 줄이지만, 그 선택 때문에 completion이 늦어질 수 있다. 본 평가의 핵심은 이 trade-off를 p95·p99와 byte 양쪽에서 정량화하는 것이다.

S3 score의 age/locality 계수와 양수 threshold는 calibration이나 exhaustive sensitivity를 거치지 않은 한 design point다. Dynamic least-loaded, join-
shortest-queue | 또는 | affinity-aware | initial
placement 같은 non-stealing online baseline도 실행하지 않았다. 따라서 S3는 static ownership에서 tail을 줄이는 한 방법이며 구조적으로 필요하다는 결론은 보류한다.

VI. RTL, 분석 모델, 전력·비용 평가 방법

A. 실제 RTL 시간 증거
WorkStealingEvidenceTop은 | production
TileScheduler S3, payload identity store와 실제 ComputeClusterArray를 연결한 계측 harness다. Victim queue에 job 1, 5, 9를 넣고 cluster 0을 idle하게 둔 skew case에서 cycle 16–18에 세 번의 steal이 발생했다. 이후 실제 MatVec start와 result를 관측하고 accepted=dispatched=completed=3, successfulSteals=3을 확인했다. 그림 4는 이 세 dispatch와 MatVec start/result의 시간 관계를 보존한다.

## Figure · RTL-simulated job identity and exact-once timeline

cycle | 16‒18 | 85‒86 | 153‒154 |

### Dispatch

| job jobs ,

### MatVec

| | result job | result job | result job

### accepted = dispatched = completed

그림 4. Cycle 16–18의 job 1/5/9 dispatch와 MatVec result identity, 3 accepted=3 dispatched=3 completed를 표시한 RTL-simulated 요약.

이 harness는 synthetic 정책과 소비자 사이의 시간적
연결을 직접 지지한다. 실제 Gemma weight parity
test와의 관계 및 미통합 구간은 표 3의 RTL-simulated/blocked 경계를 따른다. 3-job fixture의 latency를 Gemma projection 성능으로 사용하지 않으며 S0–S3 비교와 Gemma 5,856-job replay는 event-driven analytical model이다.

Python event model과 RTL scheduler는 동일 구현이 아니다. Python은 명시적 home_cluster를 사용하고 victim queue의 모든 eligible job을

탐색하며 | byte/service-dependent | locality
penalty를 적용하고 같은 event time에 여러 cluster를 dispatch할 수 있다. RTL은 jobId % clusterCount ownership, victim head-only FCFS, 고정 정수 penalty와 clock edge당 최대 한 dispatch를 사용한다. 또한 분석 기본값은 64 MAC/cycle이지만 실제 16×4, tileDim=1 MatVec는 64 MAC의 request-to-done에 65 cycle이 걸린다. 따라서 분석 cycle은 RTL cycle 예측이 아니며 현재 issue-rate 차이는 65배다. 이 보정은 공개 저장소의 docs/calibration.md와 RTL test로 고정한다.
계약 항목 | Python 분석 모델 | 현재 RTL
Home queue | 명시적 home_cluster | jobId % clusterCount
Victim 후보 | queue 내부 전체 eligible job | victim queue head만
Locality cost | byte/service-dependent | 고정 정수 penalty
Dispatch 폭 | event time당 복수 가능 | edge당 최대 1
64 MAC service | 기본 1 analytical cycle | 65 request-to-done cycle
B. 공정한 scheduler 비교
Synthetic scheduler subset은 balanced, skew, hotspot, bursty, mixed 각 1,000 job을 seed 19, 23, 29, 31, 43으로 생성한다. 모든 정책은 동일 job stream, 네 cluster, 네 channel, 네 bundle과 128-bit link를 사용한다. Process repetition 3회는 동일 seed의 deterministic 복원을 검사하며 표본 수로 세지 않는다. 결과는 repetition 0의 seed 5개 중앙값으로 요약한다. 780개 전체 row는 factor sweep을 포함하지만 본문 scheduler 비교는 subset=scheduler만 사용한다.

모델은 arrival, cluster, link와 channel availability의 다음 event로 진행한다. Weight byte는 K×N, activation byte는 K, output byte는 4N으로 계산한다. 기본 full-overlap mode는 같은 dispatchready 시점에서 link와 memory service를 시작하고 data-ready=max(link-end, memory-end)로 둔다.
Sequential | sensitivity는 | data-ready=link-
end+memory-service로 | 직렬화한다. | 둘 | 다
transaction-level DMA/PHY를 재현한 물리 timing이 아니라 경계 가정이다. DRAM bank timing, physical PHY와 FPGA clock closure도 포함하지 않는다. 모든 정상 row는 1,000 input/completed ID 일치, duplicate 0, timeout false를 통과해야 한다.

클러스터 지표는 아래 두 용어로 고정한다. unreserved
idle은 | 예약되지 | 않은 | cluster-cycle | count이며
compute-idle과 다르다.
지표 | 고정 정의
compute duty | compute-cycle 합 ÷ (cluster 수 ×completion time)
reservation occupancy | dispatch부터 link/memory wait와 compute 완료까지의 예약 구간 합 ÷ (cluster 수×completion time)

reservation occupancy가 0.99에 가까워도 MAC array가 99% 계산했다는 뜻은 아니다.

Baseline traffic 회계는 대칭이 아니다. S2/S3는 stolen job의 home cluster와 dispatch cluster가 다를 때
remote | weight·activation·partial | sum을 | 센다.
S0/S0-physical은 global queue에서 어느 cluster로 보내도 remote traffic을 정의상 0으로 둔다. 따라서 표의 S0 0 B는 관측이 아니라 중앙 공유 storage를 암묵적으로 가정한 baseline 정의다. S0-physical도 synthesis에서 얻은 비용이 아니라 arbitration 2, fanout 2, crossbar 3을 합한 임의의 +7 cycle/job sensitivity 한 점이다. 0/수십/수백 cycle이나 crossbar bandwidth sweep을 실행하지 않았으므로 중앙·분산 queue의 물리 비교는 미결정이다.

Gemma replay는 graph 순서의 183 projection을 token당 한 coarse job으로 변환한다. decode-1은 생성 토큰 1개의 183 job, decode-32는 생성 토큰 32개의 5,856 job이다. 이는 KV 길이 context-32K와
별개다. | 배치는 | graph-derived지만 | timing,
placement, scheduler와 link byte는 분석 모델이다. 한 개 deterministic 작업 목록만 사용했으므로 synthetic seed sensitivity를 대체하지 않는다.
C. Power, energy와 memory-die cost
Vivado, device file과 license가 없어 synthesis, place-and-route, SAIF/VCD 기반 report_power는 수행하지 않았다. Compute energy는 1/5/15 pJ per INT8 MAC, serialized link는 24/51.2/120 pJ per bit의 low/central/high 범위를 둔다. DDR3L은 ACT, PRE, READ, WRITE, REFRESH와 idle state의
command/background | 식을 | 분리한다. | 기존
DRAMsim3 breakdown은 Gemma replay와 cycle-by-cycle로 결합되지 않았다. Energy join의 link 항은 base projection stream과 scheduler별 stealoverhead byte를 합친다. Graph-derived MAC·byte count와 analytical dynamic READ+ACT+PRE 단위를 결합하되 refresh, idle, controller, PHY와 board power는 제외한다.

가격 경계는 DRAM package와 그 내부 physical die뿐이다. K26, Memory FPGA, PCB, regulator,
connector, | 조립비는 | 제외한다. | 2026-07-31의
AS4C1G8D3LA-10BCN | quantity-1 | snapshot은
Mouser 39.32 USD와 DigiKey 97.10 USD다. 이

가격은 변동 가능한 시점 자료이므로 조달 전에 갱신해야 한다. Package에 두 die가 있으므로 physical-die dollar는 package 가격을 2로 나눈 정규화 산술이지 구매 가능한 bare-die quote가 아니다.

VII. 질문별 결과와 설계 결정

A. Q1 — Stealing은 언제 tail을 줄이는가?
답: 정적 소유권의 큐 불균형이 큰 skew와 mixed에서는 줄지만, balanced와 channel-hotspot에서는 줄지 않는다. Balanced의 S0–S3 p95는 모두 19,524 cycle이고 successful steal은 0이다. Hotspot에서도 S1과 S3의 p95가 159,940 cycle로 같다.

Full-overlap mode에서 skew S1 p95는 285,333
cycle, S3는 | 233,625 | cycle로 | 18.12% | 낮다.
Mixed에서는 478,553에서 394,375 cycle로 17.59%
낮다. | Skew | S1→S3의 | compute | duty는
0.057097→0.068999, | reservation | occupancy는
0.336200→0.994864, | unreserved | idle은
811,713→5,137 | cycle이다. | Mixed는 | 각각
0.068345→0.080889, | 0.413076→0.996291,
1,210,683→6,432 cycle이다. 그림 5는 workload별 percentile을 같은 축에서 비교한다.
같은 | full-overlap 고정 | row의 | p99는 | skew
S1/S2/S3가 | 302,186.41/249,379.73/247,296.42
cycle, mixed가 506,354.73/426,120.83/422,255.59 cycle이다. 이는 분석 모델의 repetition 0, seed 5개 중앙값이며 physical timing이 아니다. S3의 S2 대비 p99 차이는 각각 −0.84%, −0.91%로 작다.

## Figure · Full-overlap p: static S versus locality-aware S

skew | mixed
S | | | ,
S | ,
S | ,
S | ,
.% lower p | .% lower p

Analytical model cycles · five-seed median · not physical protocol timing

그림 5. 동일 synthetic ledger의 skew/mixed에서 S1과 S3 p95를 비교한 분석 모델 결과.

현재 비용 정의에서 S0는 synthetic p95 하한을 제공한다. Skew의 S0 p95는 226,611 cycle이고 mixed는 378,232 cycle이다. S0-physical의 단일 +7 cycle/job도 순위를 바꾸지 않는다. 판정: S3는 정적 큐 불균형이 큰 조건의 후보로 유지하고, 범용 정책 채택은 보류한다.

B. Q2 — S3는 S2보다 무엇을 얻고 잃는가?
답: 지역성 벌점은 원격 가중치 전송량과 p95를 줄이지만 마지막 작업 완료를 늦출 수 있다. Skew에서 S2→S3
remote | weight는 | 2,443,776→1,519,104 | B로
37.84%, mixed에서는 3,799,040→2,957,312 B로 22.16% 감소한다. 동시에 S3 p95는 S2보다 skew 1.23%, mixed 2.33% 낮다.
Completion | time은 | 반대 | trade-off를 | 보인다.
Skew에서 S2 253,424 cycle에 비해 S3는 255,897 cycle로 0.98% 길고, mixed에서는 432,283 대비 434,075 cycle로 0.41% 길다. Tail이 짧아져도 마지막 큰 job이 늦어질 수 있음을 뜻한다. 따라서 정책 선택은 p95만이 아니라 completion과 traffic을 함께 보아야 한다.

그림 6은 이 p95·steal·전송량 trade-off를 비교하고, 표 5는 compute duty, reservation occupancy, unreserved idle을 축약 없이 함께 제시한다.

## Figure · S locality trade-off against oldest-steal S

skew | mixed
remote weight −.% ,, → ,, B | remote weight −.% ,, → ,, B
p −.% · completion +.% tail improves; last job can finish later | p −.% · completion +.% tail improves; last job can finish later

Orange = modeled migration bytes · blue = modeled latency · neither is board measurement

그림 6. S2 대비 S3의 p95·completion·remote-weight byte trade-off를 함께 표시한 분석 결과.

표 5. Full-overlap synthetic 결과의 seed 5개 중앙값

Workload | Policy | p95 cycle | Completion | compute duty | reservation occupancy | unreserved idle | Remote weight
Skew | S0 | 226,611 | 241,560 | 0.073365 | 0.997976 | 1,914 | 0 B
Skew | S1 | 285,333 | 306,837 | 0.057097 | 0.336200 | 811,713 | 0 B
Skew | S2 | 236,528 | 253,424 | 0.069318 | 0.998086 | 1,914 | 2,443,776 B
Skew | S3 | 233,625 | 255,897 | 0.068999 | 0.994864 | 5,137 | 1,519,104 B
Mixed | S0 | 378,232 | 396,401 | 0.087726 | 0.998087 | 3,034 | 0 B
Mixed | S1 | 478,553 | 513,745 | 0.068345 | 0.413076 | 1,210,683 | 0 B
Mixed | S2 | 403,766 | 432,283 | 0.081225 | 0.998245 | 3,034 | 3,799,040 B
Mixed | S3 | 394,375 | 434,075 | 0.080889 | 0.996291 | 6,432 | 2,957,312 B

S0의 remote weight 0 B는 표 3의 modeled 정의다.
표 6은 서비스 경계를 바꾸면 S2/S3 순위가 얼마나
민감한지 보여준다.

표 6. Link/memory service overlap sensitivity의 p95 중앙값

Workload | Service mode | S1 | S2 | S3 | S2↔︎S3 순위
Skew | Full overlap | 285,333.05 | 236,527.85 | 233,625.15 | S3가 1.23% 낮음
Skew | Sequential | 499,243.85 | 260,052.10 | 264,294.60 | S2가 1.63% 낮음
Mixed | Full overlap | 478,553.05 | 403,766.25 | 394,375.45 | S3가 2.33% 낮음
Mixed | Sequential | 825,278.25 | 471,918.25 | 463,867.20 | S3가 1.71% 낮음

Sequential sensitivity에서도 S3는 S1보다 낮지만 S2와의 p95 순위는 skew에서 뒤집히고 mixed에서 유지된다. 판정: S3는 전송량을 줄이는 후보이지만 S2

대비 tail 우위는 service composition에 의존하므로 물리 통합 전에는 보류한다.

C. Q3 — Actual Gemma ledger에서도 같은 방향인가? 답: decode-1에서는 아니지만 decode-32 분석 모델에서는 같은 tail·전송량 방향이 나타난다. Decode-1에서 S1 projection은 220.126 ms, S3는 220.863 ms로 S3가 0.34% 길다. Decode-32에서는 S1 7.341 s, S3 6.335 s로 S3가 13.70% 짧다. S3 p95 job latency는 1.223×10⁹→1.039×10⁹ cycle로 15.07% 낮고, remote weight는 S2 4.855 GB에서 S3 2.830 GB로 41.72% 감소한다.

Host non-projection fallback 6.550 s를 선형 외삽해 합친 decode-32 hybrid total은 S1 13.891 s, S3 12.885 s, Oracle 11.819 s다. 표 7은 decode-1과 decode-32를 context-32K 용량 조건과 구별해 비교한다.

표 7. Gemma 3 1B graph-derived decode-1/decode-32 coarse replay

Decode tokens | Policy | Projection time | Hybrid total | p95 job cycle | reservation occupancy† | Remote weight
1 | S0 | 221.706 ms | 426.407 ms | 19,750,965 | 0.605 | 0 B‡
1 | S0-physical | 221.707 ms | 426.407 ms | 19,751,147 | 0.605 | 0 B‡
1 | S1 | 220.126 ms | 424.827 ms | 19,755,052 | 0.635 | 0 B
1 | S3 | 220.863 ms | 425.564 ms | 19,064,335 | 0.597 | 68,714,496 B
32 | S0 | 6.368 s | 12.918 s | 1,197,759,773 | 0.986 | 0 B‡
32 | S0-physical | 6.368 s | 12.918 s | 1,197,764,260 | 0.986 | 0 B‡
32 | S1 | 7.341 s | 13.891 s | 1,223,259,980 | 0.713 | 0 B
32 | S2 | 6.509 s | 13.059 s | 1,219,938,210 | 0.986 | 4,855,431,168 B
32 | S3 | 6.335 s | 12.885 s | 1,038,875,850 | 0.986 | 2,829,975,552 B
32 | Oracle | 5.269 s | 11.819 s | 399,092,134 | 0.973 | 0 B

† reservation occupancy는 VI-B의 고정 정의를 따른다. ‡ S0/S0-physical 0 B는 baseline 정의다. 판정: decode-32는 실제 graph-derived 규모에서도 S3 후속 검증의 우선순위를 지지하지만, 표 3의 modeled 범위를 넘어 채택을 확정하지 않는다.

D. Q4 — 외부 8 GiB와 energy/cost는 채택을 정당화하는가?
답: 아니다. 8 GiB topology는 8개 x8 package, 16개 physical 4 Gb die를 사용하고 low/high package snapshot에서 DRAM component 합은 314.56–

776.80 USD다. 16 GiB는 두 번째 rank를 추가해 package와 cost를 두 배로 만들지만 pin-rate 상한은 6.4 GB/s로 같다.

Gemma 3 1B INT8의 context-32K capacity model은 weight 0.9313 GiB, KV 0.8125 GiB, runtime headroom 0.6863 GiB, 합계 2.4301 GiB다. Generic 3B INT8 context-32K case도 5.3528 GiB로 8 GiB 안에 들어가지만 이는 실행 증거가 아니다. context-131K 3B case는 9.8528 GiB로 8 GiB를 넘고 16 GiB에 들어간다. 표 8은 이 후보의 DRAM-die-only 비용 민감도를 보인다.

표 8. Memory-die-only 비용 민감도

Capacity | Package / physical die | Package snapshot | DRAM component sum | 70% effective GB/s | Effective GB/s per die-dollar
8 GiB | 8 / 16 | 39.32 USD | 314.56 USD | 4.48 | 0.014242
8 GiB | 8 / 16 | 68.21 USD | 545.68 USD | 4.48 | 0.008210
8 GiB | 8 / 16 | 97.10 USD | 776.80 USD | 4.48 | 0.005767
16 GiB | 16 / 32 | 39.32 USD | 629.12 USD | 4.48 | 0.007121
16 GiB | 16 / 32 | 97.10 USD | 1,553.60 USD | 4.48 | 0.002884

Decode-32 S3 중앙값은 2.483495600 hybrid-
modeled | token/s | ÷ | 545.68 | USD | =
0.004551194106 hybrid-modeled token/s per DRAM-component-dollar이다. 분모는 8개 DDR3L
package의 | DRAM | component/die-only
midpoint뿐이며 | K26, | Memory | FPGA, | PCB,
controller, | regulator, | connector, | cooling,
assembly, tax, freight, software와 board power를 제외한다. 분자는 측정 throughput이 아니라 graph-derived projection 모델과 Y700 non-projection 선형 외삽을 결합한 값이므로 전체 accelerator performance/$ 또는 제품 가격이 아니다.

Energy join은 graph-derived MAC·weight·link
byte와 | hybrid | latency를 | low/central/high
analytical unit에 결합한다. S3 decode-32의 link는 base 1,003,000,416 B/token에 steal overhead
88,806,088 | B/token을 | 더한 | 1,091,806,504
B/token이다. | Estimated | dynamic | energy는
0.291943317/0.553753651/1.185041645 J/token이고 central energy-delay product는 약 0.223 J·s/token이다. 표 3의 modeled 경계에 따라 이는 전체 보드 J/token이 아니다. 판정: 외부 8 GiB는 용량·energy·cost만으로 채택하지 않고 로컬 메모리 대역폭·경합·전력 기준선이 이길 때만 유지한다.

VIII. KiCad 물리 참조 설계

KiCad hierarchy는 K26 SOM GTH boundary, XC7K160T bank boundary, 네 DDR3L x16
topology, | four-lane | link,
clock/reset/configuration, | power/decoupling과
JTAG/debug를 포함한다. Coupon은 29 footprint,

116 net, 65 track segment, 50 via, 한 zone과 140×110 mm outline을 가진다. 그림 7은 체크인된 k26_memory_coupon.kicad_pcb를 KiCad CLI의 고정 camera·quality 설정으로 직접 렌더링한 설계 모습이다. 장식용 생성 이미지가 아니라 native board source의 3D view지만, 부품 모델·배선 완성도·제조 가능성을 보증하지 않는다.

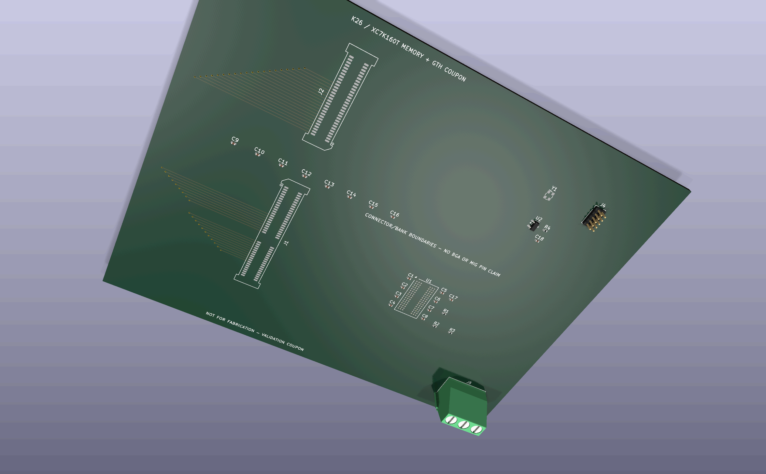
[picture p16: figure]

그림 7. KiCad native PCB source에서 직접 렌더링한 K26/XC7K160T memory+GTH validation coupon. Native gate는 제한된 proposal rule 범위에서 통과하지만 55 unrouted, 9 return-path crossings, no ground stitching, 0/116 test points와 provenance blocker가 남아 있다. NOT FOR FABRICATION.

Native 0건은 routing 완료를 뜻하지 않는다. 독립
분석기는 55개 unrouted net, 9개 high-speed
return-path crossing, ground stitching 부재, test-
point | 0/116과 | incomplete | MPN/datasheet
coverage를 | 찾았다. | Geometry에는 | 0.10 | mm
annular ring, 10개 untented via-in-pad, 27개 front fiducial 부재가 남아 있다. Thermal analyzer는 부품의 MPN, dissipation과 thermal parameter가 없어 0개 component만 평가했다.

따라서 coupon이 직접 지지하는 것은 “제한된
connector/bank | boundary | model이 | 선언한
ERC/DRC와 export를 재현한다”는 명제뿐이다. 실제 BGA pin, 네 MIG bank placement, impedance, insertion loss, skew, jitter, eye margin, PDN, temperature와 EMC는 inference 또는 blocker다. Vivado MIG와 post-route timing이 닫히기 전 XC7K160T-2FFG676I는 conditional candidate다.

IX. 논의와 다음 검증

결과를 바꿀 가능성이 가장 큰 미검증 가정은 세 가지다. 첫째, non-stealing dynamic placement와 S3 score sensitivity가 없어 Q1의 인과는 static S1 비교에 한정된다. 둘째, full-overlap과 sequential 경계
사이에서 | skew | S2/S3 | 순위가 | 바뀌므로 | 실제
DMA→DDR→response 순서가 Q2를 바꿀 수 있다. 셋째, 로컬 4 GB의 실효 대역폭·경합·전력과 외부 8 GiB의 전체 보드 비용이 없어 Q4의 구조 채택을 판정할 수 없다. 세 항목 모두 표 3의 modeled/blocked 등급에 해당한다.

따라서 다음 실험은 우선순위대로 진행한다. (1) actual Gemma tile stream과 scheduler dispatch를 RTL– DRAMsim3 command trace에 연결해 S2/S3 및 동적 non-stealing baseline을 비교한다. (2) Vivado에서 S0–S3와 1/2/4 cluster의 LUT, BRAM, Fmax, fanout, MIG placement와 SAIF 기반 power를 닫는다. (3) local 4 GB와 external 8 GiB를 동일 decode-32
조건에서 | 측정한 | 뒤에만 | exact
pin·stackup·SI/PI·thermal·CAM 및 board 제작으로 넘어간다.

X. 결론

관측. 실제 Gemma 3 1B ONNX graph에서 유도한 decode-32 작업 목록에서는 S3가 static S1보다 p95와 p99를 각각 15.07%와 14.61% 낮췄다. 같은 Gemma replay에서 S3는 S2보다 remote-weight byte를 41.72% 줄였고 completion도 2.68% 짧았다. 이 replay와 분리한 1,000-job synthetic stress에서는 skew와 mixed의 S1 대비 p95가 각각 18.12%와 17.59% 낮아졌고, skew에서 S3는 S2보다 remote-weight byte를 37.84% 줄이는 대신 completion이 0.98% 길었다. Balanced와 hotspot에서는 이득이 없었으며, synthetic 결과의 S2/S3 순위는 서비스 경계에 민감했다. 모든 시간 결과는 보드 측정이 아니라 분석 모델이다.

채택·보류. S3는 static ownership의 불균형을 완화할 후속 RTL 후보로 채택한다. 외부 Memory FPGA와 중앙
·분산 | queue의 | 물리 | 선택은 | 보류한다. | 실제
dispatch→DMA/DDR→MatVec 통합, 동적 non-stealing 비교, Vivado timing·power, local 4 GB 대비 대역폭·경합·전력 측정이 모두 통과하면 외부 Memory FPGA와 S3를 함께 채택할 수 있다.

참고문헌

[1] W. Kwon et al., “Efficient Memory Management for Large Language Model Serving with PagedAttention,” arXiv:2309.06180, 2023.
[2] T. Dao et al., “FlashAttention: Fast and Memory-
Efficient | Exact | Attention | with | IO-Awareness,”
arXiv:2205.14135, 2022.
[3] E. Frantar et al., “GPTQ: Accurate Post-Training Quantization for Generative Pre-trained Transformers,” arXiv:2210.17323, 2022.
[4] G. Xiao et al., “SmoothQuant: Accurate and Efficient Post-Training Quantization for LLMs,” arXiv:2211.10438, 2022.
[5] J. Lin et al., “AWQ: Activation-aware Weight Quantization for LLM Compression and Acceleration,” arXiv:2306.00978, 2023.
[6] B. Li et al., “FTRANS: Energy-Efficient Acceleration of Transformers using FPGA,” ISLPED, 2020.
[7] S. Hong et al., “DFX: A Low-latency Multi-FPGA Appliance for Accelerating Transformer-based Text Generation,” MICRO-55, 2022.
[8] S. Zeng et al., “FlightLLM: Efficient Large Language Model Inference with a Complete Mapping Flow on FPGAs,” arXiv:2401.03868, 2024.
[9] S. Li et al., “DRAMsim3: A Cycle-Accurate, Thermal-Capable DRAM Simulator,” IEEE Computer Architecture Letters, vol. 19, no. 2, 2020.
[10] AMD, Kria K26 SOM Data Sheet DS987.
[11] AMD, Kria SOM Carrier Card Design Guide UG1091.
[12] AMD, 7 Series FPGAs Packaging and Pinout UG475.
[13] AMD, 7 Series FPGAs Memory Interface Solutions UG586.
[14] KiCad Project, KiCad 9 Documentation, ERC and DRC reference.
[15] R. D. Blumofe and C. E. Leiserson, “Scheduling Multithreaded Computations by Work Stealing,” Journal of the ACM, vol. 46, no. 5, pp. 720–748, 1999.
[16] Q. Chen et al., “Locality-Aware Work Stealing Based on Online Profiling and Auto-Tuning for Multisocket
Multicore | Architectures,” | HPDC, | 2015,
doi:10.1145/2766450.

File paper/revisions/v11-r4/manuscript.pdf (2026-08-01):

## 온디바이스 sLLM을 위한 K26–Memory FPGA 후보 구조의 설계 공간 평가

Design-Space Evaluation of a K26–Memory FPGA Candidate Architecture for On-Device sLLMs

최윤혁 (CHOI YUNHYUK) · 한국디지털미디어고등학교 · ORCID 0009-0006-3537-0249 2026-08-01

초록

온디바이스 소형 언어 모델은 서버급 가속기를 사용하기 어려워 메모리 용량과 가중치 공급 대역폭을 제한된 전력 ·비용 안에서 함께 해결해야 한다. 본 연구는 Kria K26이 연산·제어를 맡고 외부 Memory FPGA가 다채널 가중치 공급을 맡는 확장형 후보 구조를 설계했다. 정적 작업 배정으로 일부 연산 클러스터가 유휴 상태에 빠질 때는 데이터 이동 비용을 고려한 작업 훔치기(Work Stealing) 를 선택적으로 사용한다. 실제 Gemma 3 1B 그래프의 7,837개 노드에서 토큰당 183개 투영 연산을 추출하고, 이를 의존성이 있는 802개 출력 타일로 변환해 네 가지 초기 배치와 세 가지 대기열 정책을 비교했다. 합성 불균형 부하에서 지역성 인식 정책은 정적 배정보다 TileJob p95를 19.13% 줄이고, 단순 작업 훔치기보다 비지역 가중치 이동량을 35.49% 줄였다. 그러나 Gemma 형상에서는 초기 배치에 따라 p95 변화가 +0.28%에서 −19.79%까지 달라졌으며, K26 로컬 메모리 기준선도 외부 6.4 GB/s 후보보다 짧았다. 따라서 외부 8GB와 작업 재분배는 Gemma 1B의 필수 구성요소가 아니라 더 큰 모델·긴 문맥·로컬 경합이 확인될 때 채택할 확장 수단이다. 결과는 제한된 RTL 시뮬레이션과 분석 모델에 근거하며 보드 실측값이 아니다.

핵심어: 온디바이스 sLLM, Kria K26, Memory FPGA, 다채널 메모리, 작업 훔치기, SpinalHDL

Abstract

On-device small language models must address memory capacity and weight-delivery bandwidth within tighter power and cost limits than server accelerators. This work evaluates an extensible candidate architecture in which a Kria K26 handles control and computation while an external Memory FPGA supplies weights through multiple memory channels. Locality-aware work stealing is enabled only when static placement leaves compute clusters idle and its expected benefit exceeds data-movement cost. From the 7,837-node Gemma 3 1B graph, 183 projections per token are mapped to 802 dependency-aware output tiles and evaluated under four initial placements and three queue policies. On a synthetic skew workload, the locality-aware policy reduces TileJob p95 by 19.13% against static placement and non-local weight movement by 35.49% against oldest-job stealing. On Gemma-shaped tiles, however, the p95 effect ranges from +0.28% to −19.79% depending on initial placement, and the modeled K26-local baseline remains shorter than the external 6.4-GB/s candidate. External 8GB memory and work stealing are therefore conditional expansion
mechanisms | rather | than | requirements | for
Gemma 1B. The results are based on bounded RTL simulation and analytical models, not board measurements.

Keywords: on-device sLLM, Kria K26, Memory FPGA, multi-channel memory, work stealing, SpinalHDL

I. 서론

온디바이스 환경에서는 서버급 GPU의 전력과 가격을 그대로 사용할 수 없다. 모델이 메모리에 들어가는지만 보는 것도 충분하지 않다. 연산부가 가중치를 기다리는 시간, 운영체제·활성값·KV cache가 쓰는 로컬 메모리와 가중치 공급의 경합, 여러 연산 클러스터 사이의 부하 균형이 함께 성능을 결정한다.

본 연구는 처음에 외부 메모리가 Gemma 3 1B의 용량 때문에 필요하다고 가정했다. 그러나 INT8 가중치와 32K 문맥의 용량을 계산한 결과 2.43 GiB로, 명목상 K26 로컬 4GB에 들어갔다. 이에 연구 질문을 “외부 메모리가 필요한가”에서 “가중치 공급을 로컬 실행 메모리와 분리하는 구조는 어떤 조건에서 이득인가”로 바꾸었다.

제안 후보는 K26의 연산·제어와 Memory FPGA의 다채널 가중치 공급을 분리한다. K26에는 네 연산 클러스터와 독립 대기열을 두고, 외부 쪽에는 네 DDR3L x16 채널과 네 논리 링크를 둔다. 정적 배정이 데이터 지역성을 지키더라도 작업이 한쪽에 몰리면 일부

클러스터가 놀 수 있다. 이때만 유휴 클러스터가 다른 대기열의 작업을 가져오며, 이미 배치된 가중치와 활성값을 옮기는 비용을 함께 계산한다.

본 연구의 기여는 다음과 같다. 첫째, 로컬 실행 메모리와 외부 가중치 공급 메모리의 역할을 분리한 온디바이스 확장 후보를 제시하고 K26 로컬 기준선과 비교했다.

둘째, 원격 복사 시간을 실제 링크 서비스에 부과해 초기 배치와 작업 재분배의 효과를 분리했다. 셋째, 실제 Gemma 그래프의 형상에서 TileJob을 만들고, 제한된 실제 가중치 타일이 DMA 명령·메모리 응답 경계·논리
링크·MatVec까지 | 통과하는 | 재현 | 가능한 | 흐름을
구현했다.

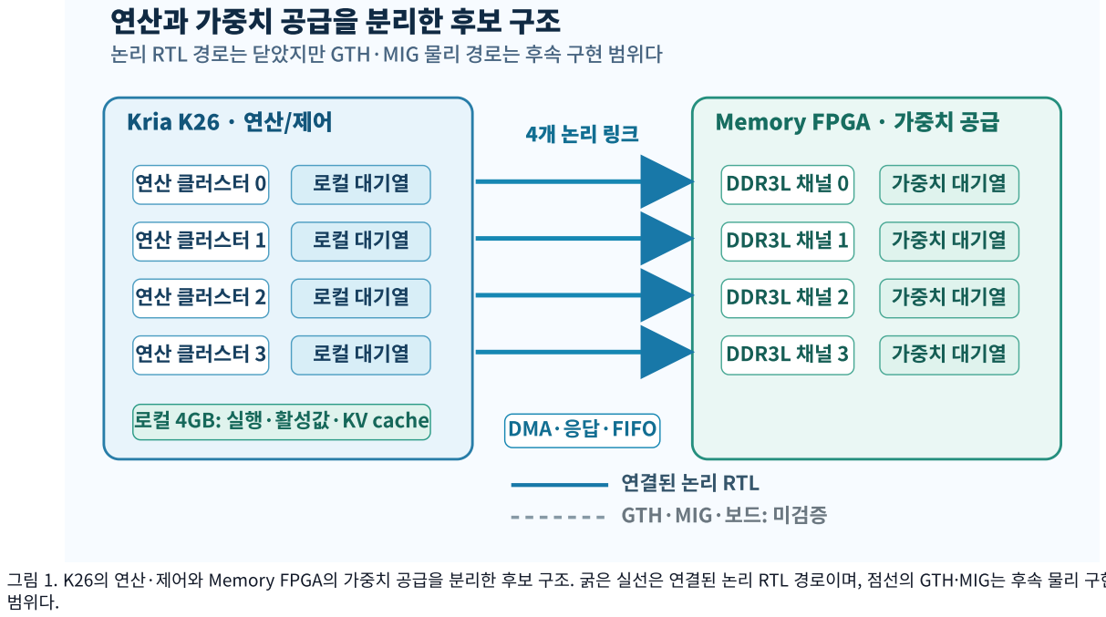
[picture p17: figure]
연산과 가중치 공급을 분리한 후보 구조; Kria K · 연산/제어; 연산 클러스터 0; 로컬 대기열; 연산 클러스터 1; 연산 클러스터 2; 연산 클러스터 3; 로컬 4GB: 실행·활성값·KV cache; Memory FPGA · 가중치 공급; DDRL 채널 0; 가중치 대기열; DDRL 채널 1; DDRL 채널 2; DDRL 채널 3; DMA·응답·FIFO; 연결된 논리 RTL; GTH·MIG·보드: 미검증; 범위다.

논리 RTL 경로는 닫았지만 GTH·MIG 물리 경로는 후속 구현 범위다

그림 1. K26의 연산·제어와 Memory FPGA의 가중치 공급을 분리한 후보 구조. 굵은 실선은 연결된 논리 RTL 경로이며, 점선의 GTH·MIG는 후속 물리 구현

II. 관련 연구와 연구 공백

PagedAttention[1]은 KV cache의 페이지 관리 문제를, FlashAttention[2]은 attention 연산의 데이터 이동을 줄이는 방법을 다룬다. GPTQ[3], SmoothQuant[4], AWQ[5]는 모델 크기와 양자화 정확도의 균형을 연구한다. 이 연구들은 메모리 이동이 중요하다는 근거를 제공하지만, 여러 로컬 대기열과 외부 가중치 공급 링크를 함께 가진 소형 FPGA 구조의 초기 배치 문제를 직접 다루지 않는다.

FTRANS[6], DFX[7], FlightLLM[8]은 Transformer의 FPGA 매핑과 다중 FPGA 실행 구조를 제시했다. 이들은 완성된 매핑 흐름이나 처리량을 중심으로 평가한다. 본 연구는 최고 처리량 경쟁보다 설계 조건 규명에 초점을 둔다. K26 로컬 메모리와 외부 다채널 메모리 후보를 같은 작업 형상에서 비교하고, 작업 재분배가 가중치 복사 비용을 감수할 조건을 찾는다.

고전적 작업 훔치기[15]는 의존 작업의 부하 균형을 설명하고, LAWS[16]는 NUMA 환경에서 원격 메모리 비용을 고려한다. 본 연구의 정책은 이들보다 이론적으로 새롭다고 주장하지 않는다. 연구 공백은 실제 sLLM 투영

형상, FPGA 메모리 분리 구조, 초기 배치, 비지역 전송 비용을 하나의 공개 설계 흐름에서 비교한 자료가 부족하다는 점이다.

III. 온디바이스 가속기의 설계 목표

대상은 3B 이하 sLLM을 향한 확장형 후보이며, 이번 평가는 Gemma 3 1B를 사용한다. K26 로컬 4GB는 운영체제와 실행 환경, 활성값, KV cache, 자주 쓰는 데이터를 담당한다. 외부 메모리는 상주 가중치, 다음 층 사전 적재, 용량 확장을 담당하도록 역할을 나눈다.

표 1. 설계 목표와 이번 평가의 범위

항목 | 목표 | 이번 평가
연산 | K26의 다중 연산 클러스터 | 4개 signed-INT8 MatVec 클러스터
로컬 메모리 | 실행 환경·활성값·KV cache | 4.8–14.4 GB/s 유효 대역폭 민감도
외부 메모리 | 8GB 이상, 채널·rank 확장 | 4×DDR3L x16, 3.2– 12.8 GB/s 분석
링크 | Memory FPGA→K26 가중치 전송 | 4개 논리 링크, 64–256 bit 민감도
작업 배치 | 지역성과 부하 균형 | 정적·라운드로빈·크기 균형·채널 친화
물리 검증 | GTH·MIG·전원·보드 계측 | 논리 RTL과 라우팅 쿠폰까지만 수행

외부 8GB는 Gemma 1B가 4GB에 들어가지 않아서 선택한 것이 아니다. 더 큰 모델과 긴 문맥으로 확장하거나, 로컬 실행 메모리의 경합을 줄이고, 여러 클러스터에 독립적인 가중치 공급 경로를 제공하기 위한 후보이다. 따라서 외부 구조는 K26 로컬 기준선보다 나은 조건을 보여야 채택할 수 있다.

IV. K26–Memory FPGA 시스템 구조

K26 측의 입력 명령은 작업 정보와 활성값만 포함한다. 명령은 DMA 요청 FIFO를 거쳐 외부 메모리 채널에 가중치를 요청한다. Memory FPGA 경계에서 돌아온 가중치 타일은 작업의 선호 링크에 따라 네 논리 FIFO 중 하나로 들어간다. K26은 작업 ID로 보관 중인 활성값과 응답 가중치를 결합하고, 대기열 정책이 선택한
클러스터에서 MatVec을 수행한다.

논리 가상 시제품은 작업 수락→DMA 요청→채널 스케줄러→DDR 응답 경계→논리 링크 FIFO→입력 결합 →MatVec 결과를 하나의 역압 흐름으로 연결한다. 가중치 응답이 없으면 연산 명령을 만들 수 없고, 동일 작업 ID의 응답은 한 번만 수락한다. 실제 Gemma 파일에서 제한적으로 추출한 세 개의 16×4 INT8 가중치 타일이 이 경로를 통과해 소프트웨어 INT32 결과와 모두 일치했다.

이 연결은 물리 링크가 완성되었다는 뜻이 아니다. 링크 FIFO는 넓은 논리 응답을 전달하며 GTH 직렬화, 레인 결합, CDC, 패킷 분할, CRC 재전송, 크레딧 반환은

포함하지 않는다. 메모리 응답도 MIG 경계에서 주입하므로 DDR3L PHY와 보정 과정을 검증하지 않는다. 그림 1은 이 차이를 실선과 점선으로 구분한다.

표 2. 결과를 해석할 때의 증거 구분

구분 | 포함 내용 | 허용되는 해석
직접 확인 | ONNX 노드·형상, 실제 타일 3개, KiCad 원본 | 해당 파일과 제한 경로의 사실
RTL 시뮬레이션 | 닫힌 논리 경로, 정확히 한 번 처리, MatVec 결과 | 논리 기능과 역압
분석 모델 | 대기열, 링크·메모리 서비스, 배치 민감도 | 명시한 가정 안의 상대 비교
미검증 | GTH·MIG 타이밍, 보드 전력, SI/PI, 전체 가격 | 후속 구현·계측 과제
V. Gemma 3 1B 작업의 하드웨어 매핑

로컬에 보관된 Gemma 3 1B ONNX 그래프는 7,837개 노드와 토큰당 183개 밀집 투영 연산을 가진다. Attention의 q, k, v, o가 104개, MLP의 gate, up, down이 78개, lm_head가 1개다. 원본 float32 투영 가중치는 약 4.0GB이며, 평가에서는 명시적인 INT8 변환을 가정해 약 1.0GB로 모델링했다. 모델 가중치 자체는 공개 저장소에 배포하지 않는다.

각 투영은 전체 K차원을 유지하고 N≤1024인 출력 타일로 나누어 토큰당 802개 TileJob을 만든다. q/k/v가 끝난 뒤 o, o가 끝난 뒤 gate/up, 이 둘이 끝난 뒤 down을 내보낸다. 다음 계층은 이전 down 뒤에 시작하고, 다음 토큰은 lm_head가 끝난 뒤에만 시작한다. 32토큰 조건은 이 의존성 인식 토큰을 중첩

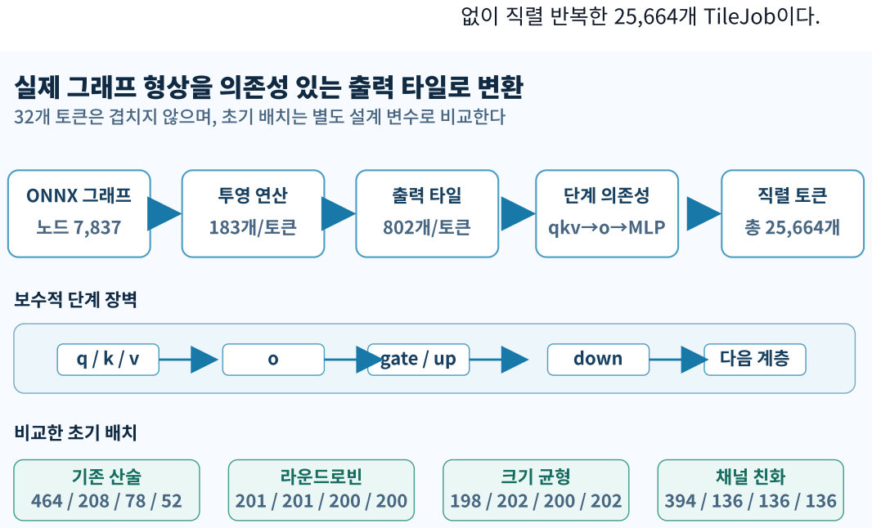
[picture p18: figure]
없이 직렬 반복한 25,664개 TileJob이다.; 실제 그래프 형상을 의존성 있는 출력 타일로 변환; 32개 토큰은 겹치지 않으며, 초기 배치는 별도 설계 변수로 비교한다; ONNX 그래프; 단계 의존성; qkv→o→MLP; 보수적 단계 장벽; gate / up; down; 비교한 초기 배치; 라운드로빈  /  /  / 

그림 2. 실제 Gemma 그래프의 투영 연산을 의존성이 있는 출력 TileJob으로 변환하는 과정. 배치 규칙은 그래프 사실이 아니라 별도 모델 변수다.

초기 배치는 네 가지다. 기존 산술 규칙은 토큰당 타일 수가 C0/C1/C2/C3에 464/208/78/52로 치우친다. 라운드로빈은 타일 수를 균등하게 나눈다. 크기 균형 배치는 누적 MAC 수가 가장 작은 클러스터에 다음 타일을 둔다. 채널 친화 배치는 가중치가 있는 채널과 같은 번호의 클러스터를 우선한다. 네 배치 모두 실제 컴파일러 결과가 아니라 설계 변수이며, 이 비교로 “초기 배치를 잘한 효과”와 “작업을 나중에 옮긴 효과”를

VI. 다중 대기열과 지역성 인식 작업 재분배

S1은 각 클러스터가 자기 대기열만 선착순으로 처리하는 정적 기준선이다. S2는 유휴 클러스터가 다른 대기열에서 가장 오래 기다린 작업을 가져온다. S3는 기다린 시간에서 가중치 크기, 활성값 이동, 부분합 반환, 링크 불일치 비용을 뺀 점수가 양수일 때만 작업을 가져온다.

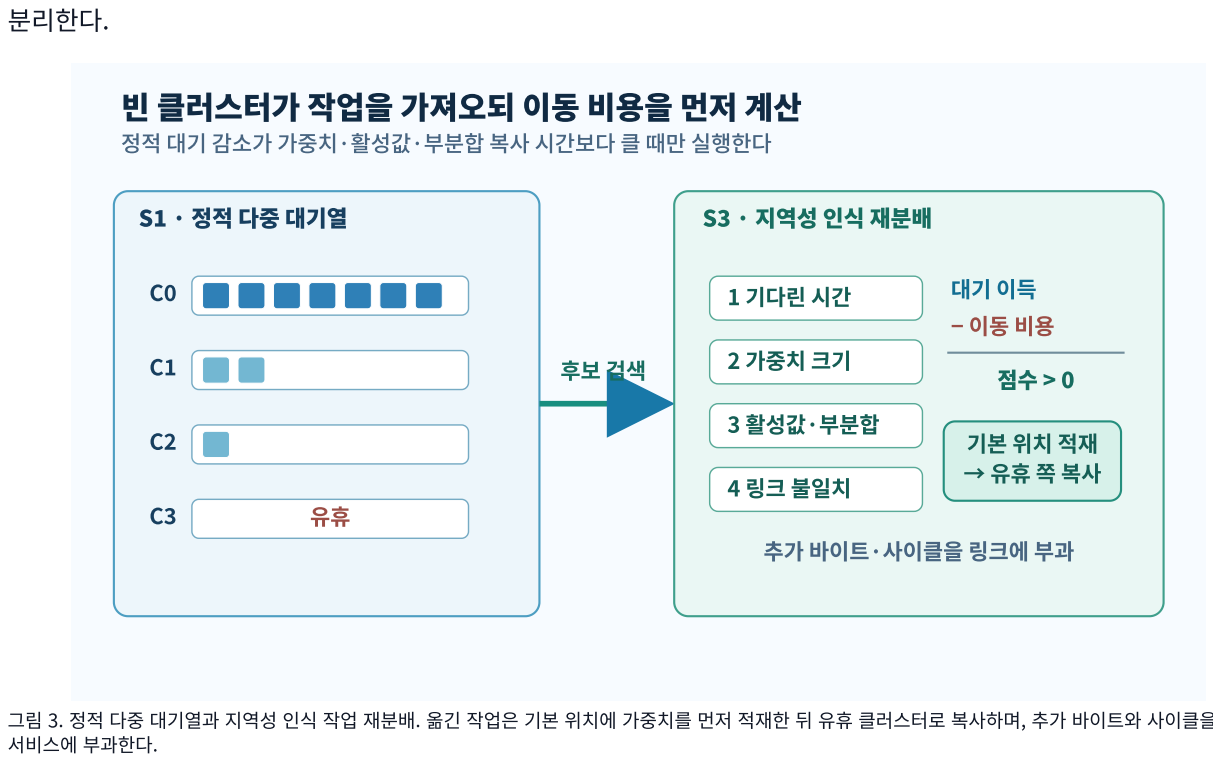
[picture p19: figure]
분리한다.; 빈 클러스터가 작업을 가져오되 이동 비용을 먼저 계산; 정적 대기 감소가 가중치·활성값·부분합 복사 시간보다 클 때만 실행한다; S · 정적 다중 대기열; S · 지역성 인식 재분배; 1 기다린 시간; 2 가중치 크기; 3 활성값·부분합; 4 링크 불일치; 추가 바이트·사이클을 링크에 부과; 서비스에 부과한다.

그림 3. 정적 다중 대기열과 지역성 인식 작업 재분배. 옮긴 작업은 기본 위치에 가중치를 먼저 적재한 뒤 유휴 클러스터로 복사하며, 추가 바이트와 사이클을 링크

이번 모델은 작업 훔치기의 비용을 사후 통계로만 세지
않는다. 정적 배치가 선호 링크로 가중치를 먼저
공급했다고 가정하고, 훔친 작업은 가중치·활성값· 부분합을 실행 클러스터 쪽 링크로 다시 복사한다. 기본 전송과 추가 전송의 바이트와 사이클을 분리해 저장한다. 따라서 S3가 더 작은 작업을 고르면 S2보다 비지역 전송량을 줄일 수 있지만, 복사 자체가 정적 S1보다 완료시간을 늘릴 수도 있다.

S3는 상시 정책이 아니다. 균형 배치에서는 옮길 이유가 없고, 메모리 채널 자체가 병목이면 빈 클러스터를 채워도 완료시간이 줄지 않는다. 정책을 켜는 조건은 예상 대기

감소가 추가 데이터 이동 시간보다 큰 경우이다.

VII. 구현과 평가 방법

RTL은 | SpinalHDL로 | 작성하고 | Verilator로
시뮬레이션했다. 직접 확인한 경로는 세 실제 가중치 타일의 작업 수락, DMA 명령, DDR 응답 경계, 링크 FIFO, MatVec 결과이다. 별도의 세 작업 합성 시험 입력은 S3 스케줄러가 작업 ID를 보존하며 세 작업을 훔치고 정확히 한 번 완료하는지 확인한다.

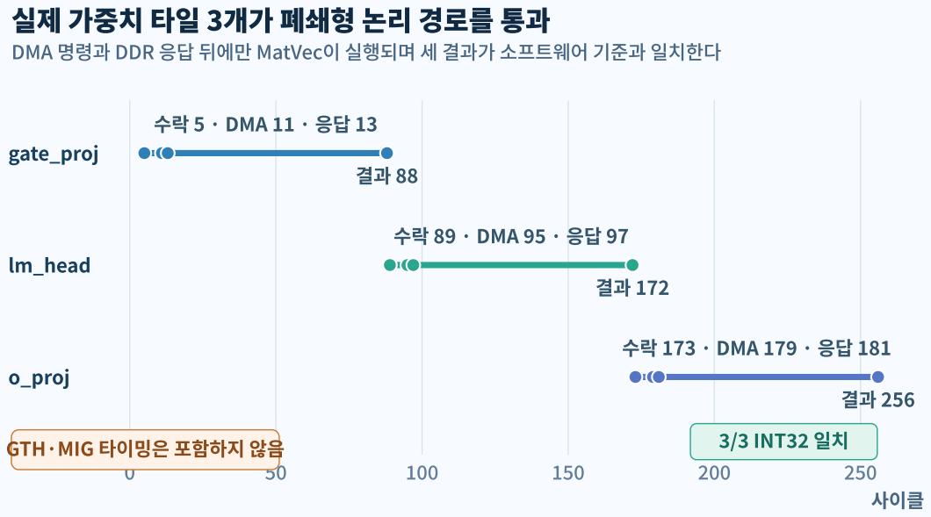
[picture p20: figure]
실제 가중치 타일 3개가 폐쇄형 논리 경로를 통과; 사이클; gate_proj; 수락 5 · DMA  · 응답 13; lm_head; 수락 89 · DMA  · 응답 97; o_proj; 수락 173 · DMA  · 응답 181; GTH·MIG 타이밍은 포함하지 않음; / INT 일치

DMA 명령과 DDR 응답 뒤에만 MatVec이 실행되며 세 결과가 소프트웨어 기준과 일치한다

그림 4. 실제 Gemma 대표 타일 세 개가 폐루프 논리 RTL 경로를 통과한 사이클 추적. 세 결과는 소프트웨어 INT32 기준과 일치한다.

분석 모델은 클러스터 4개, 메모리 채널 4개, 논리 링크
묶음 4개, 묶음당 128비트를 기본값으로 사용한다. 합성
부하는 균형, 편향, 채널 집중, 순간 집중, 혼합의 1,000개 작업을 5개 시드에서 생성한다. 같은 작업 부하와 시드의 모든 정책은 동일한 작업 목록 해시를 사용한다. 정책별 중앙값을 나누지 않고 시드별 변화율을 먼저 계산한 뒤 그 중앙값과 범위를 보고한다.

Gemma 평가는 모델에서 추출한 K/N 형상과 보수적 단계 의존성을 사용한다. p95와 p99는 개별 TileJob이 의존성에서 해제된 시점부터 완료될 때까지의 분포이다. 사용자 요청 단위의 꼬리 지연이 아니다. 32토큰 시간은 동일한 토큰 모델의 직렬 반복이며 기능적 텍스트 생성도 아니다.

K26 로컬 기준선은 외부 링크를 제거하고 공유 로컬 메모리의 유효 대역폭을 4.8, 9.6, 14.4 GB/s로 바꾼다. 외부 후보는 네 채널의 합을 3.2, 6.4, 12.8 GB/s로 바꾸고 링크 폭을 64, 128, 256비트로 비교한다. 이 값들은 측정값이 아니라 채택 임계값을 찾는 민감도이다.

VIII. 결과와 시스템 설계 결정

A. 합성 불균형 부하
합성 편향 부하에서 S3는 S1보다 TileJob p95를 19.13%, p99를 18.71% 줄였다. 전체 완료시간도 17.25% 짧았다. S2와 비교하면 비지역 가중치 이동량을 35.49% 줄였고 완료시간 중앙값 차이는 +0.01%로 거의 같았다. 혼합 부하에서도 S1 대비 p95가 17.70% 줄었다. 균형 부하에서는 변화가 없고 채널 집중 부하에서는 p95 변화가 0%였다.

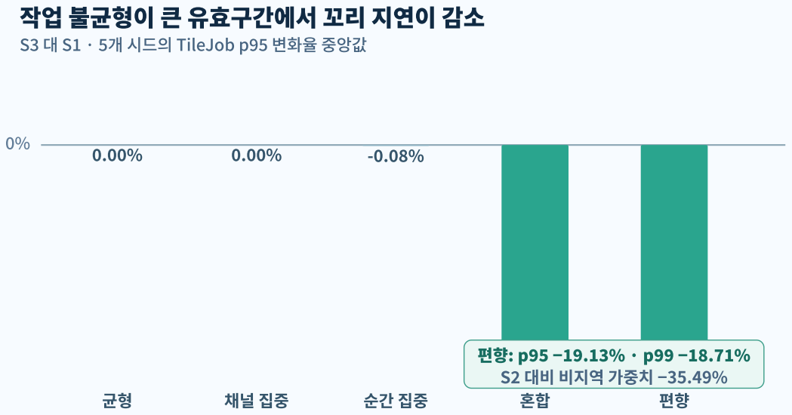
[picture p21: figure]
작업 불균형이 큰 유효구간에서 꼬리 지연이 감소; S 대 S · 개 시드의 TileJob p 변화율 중앙값; 편향: p −.% · p −.% S 대비 비지역 가중치 −35.49%

그림 5. 동일한 다섯 시드를 짝지어 비교한 합성 부하 결과. 작업 불균형이 큰 편향과 혼합 부하에서만 꼬리 지연 감소가 나타난다.

표 3. 합성 부하의 S3 효과, 동일 시드 쌍비교 중앙값

부하 | S1 대비 완료시간 | S1 대비 TileJob p95 | S1 대비 p99 | S2 대비 비지역 가중치
균형 | 0.00% | 0.00% | 0.00% | 해당 없음
채널 집중 | −0.06% | 0.00% | 0.00% | 0.00%
순간 집중 | −1.79% | −0.08% | −1.16% | −15.25%
혼합 | −15.91% | −17.70% | −16.92% | −22.60%
편향 | −17.25% | −19.13% | −18.71% | −35.49%

이 결과는 작업 불균형이 데이터 이동 비용보다 큰 조건에서만 작업 재분배가 유효하다는 가설을 지지한다. 합성 편향 부하의 수치를 실제 Gemma 실행 결과로

해석해서는 안 된다.

B. Gemma 형상과 초기 배치
Gemma 형상에서는 초기 배치가 결과를 지배했다. 기존 산술 배치에서 S3는 S1보다 완료시간이 4.80% 길고 p95도 0.28% 길었다. 원격 복사 비용을 부과하면 빈 클러스터를 채운 이득보다 이동 비용이 더 컸다. 라운드로빈과 크기 균형 배치에서는 p95가 변하지 않았고 완료시간만 1% 미만 줄었다. 채널 친화 배치에는 큰 작업 쏠림이 남아 S3가 완료시간을 7.56%, p95를 19.79% 줄였다.

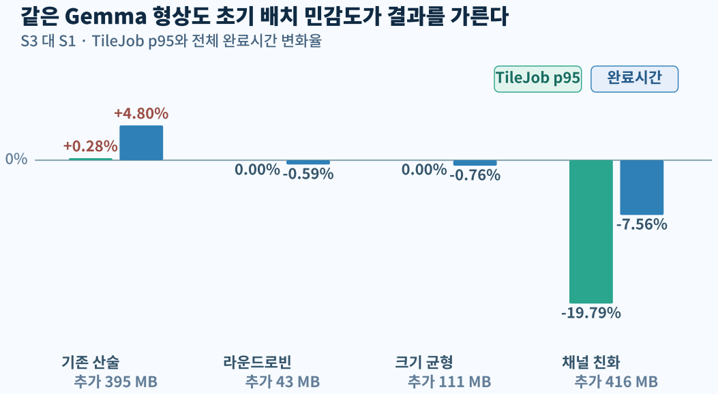
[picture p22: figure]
같은 Gemma 형상도 초기 배치 민감도가 결과를 가른다; S 대 S · TileJob p와 전체 완료시간 변화율; 라운드로빈; TileJob p; 완료시간

그림 6. 같은 Gemma 형상에서 초기 배치에 따라 S3의 효과가 바뀐다. 배치가 이미 균형이면 꼬리 지연 이득이 없다.

표 4. Gemma 의존성 인식 TileJob의 S3 효과

초기 배치 | 타일 수 C0/C1/C2/C3 | 완료시간 변화 | TileJob p95 변화 | 추가 링크 전송
기존 산술 규칙 | 464/208/78/52 | +4.80% | +0.28% | 395.2 MB/ 토큰
라운드로빈 | 201/201/200/200 | −0.59% | 0.00% | 43.3 MB/ 토큰
크기 균형 | 198/202/200/202 | −0.76% | 0.00% | 110.8 MB/ 토큰
채널 친화 | 394/136/136/136 | −7.56% | −19.79% | 416.4 MB/ 토큰

결론은 “Gemma에서 작업 훔치기가 빠르다”가 아니다. 초기 배치가 충분히 균형이면 작업을 옮길 필요가 없다. 채널 지역성을 우선해 큰 불균형이 남은 경우에만 선택적 재분배가 의미가 있다.

C. K26 로컬과 외부 메모리 후보
크기 균형 S1에서 K26 로컬 4.8/9.6/14.4 GB/s의 완료시간은 각각 45.0M/24.6M/17.8M 사이클이었다.
외부 | 4채널 | 3.2/6.4/12.8 | GB/s | 후보는
238.3M/120.6M/62.4M 사이클이었다. 외부 6.4 GB/s 조건은 링크 폭을 64비트에서 256비트로 넓혀도 거의 바뀌지 않아 메모리 공급이 병목이었다.

이 민감도에서는 외부 후보가 Gemma 1B의 성능 기준선을 이기지 못한다. 또한 INT8 문맥 길이 32K의 용량 2.43 GiB가 로컬 4GB 안에 들어가므로 용량 채택 근거도 없다. 외부 Memory FPGA는 3B·더 긴 문맥· 실제 로컬 경합을 평가할 다음 구조 후보이며, Gemma 1B의 기본 구성은 K26 로컬이다.

비용 자료는 DDR3L 부품 가격 조사 시점 자료만 포함하고 K26, FPGA, PCB, 전원, 냉각, 조립을
제외한다. | 에너지도 | MAC·링크·DRAM | 동적 | 항의
민감도일 뿐이다. 따라서 저비용·저전력은 설계 목표이지 이번 연구가 실물로 달성한 결과가 아니다.

IX. PCB 인터페이스 라우팅 쿠폰

KiCad 자료는 전체 Memory FPGA 보드가 아니라 인터페이스 배선의 공간을 검토한 쿠폰이다. J1은 XC7K160T의 DDR/GTH bank 경계를, J2는 K26 GTH 경계를 대신한 범용 Samtec 커넥터다. U1은 네 메모리 채널 중 DDR3L x16 한 슬라이스만 나타낸다. 실제 K26 SOM 커넥터 핀과 FPGA BGA ball, 네 MIG 채널, 전원 트리, 부트 회로는 포함하지 않는다.


그림 7. 실제 KiCad 원본에서 렌더링한 인터페이스 라우팅 쿠폰. 두 범용 경계 커넥터, 대표 DDR3L x16 슬라이스, GTH·refclk 배선을 표시한다. NOT FOR FABRICATION.

쿠폰은 29개 부품 배치와 20개 배선된 GTH/기준 클록
신호망을 포함하며 선언된 제한 범위의 ERC/DRC는
0건이다. 그러나 전체 116개 신호망 중 55개가 미배선이고, 고속 신호 귀환 경로와 접지 비아 배치, 시험점, 정확한 부품 출처가 완성되지 않았다. 이 자료가 지지하는 주장은 “대표 링크와 DDR 배선의 위치 관계를 KiCad 객체로 구체화했다”는 것뿐이다. 제작 가능성, SI/PI, 온도, 실제 대역폭은 검증하지 않았다.
X. 논의와 한계

첫째, Gemma 작업의 K/N 형상과 투영 순서는 실제 모델에서 얻었지만 초기 클러스터·채널·링크 배치는 모델 변수다. 실제 컴파일러나 실행 환경의 배치가 생기면 네 민감도 중 어느 조건에 가까운지 다시 확인해야 한다. 둘째, 단계 장벽은 잘못된 병렬 실행을 막는 보수적

모델이며 실제 연산자의 세부 중첩 실행을 재현하지 않는다. 셋째, p95와 p99는 TileJob 분포이지 사용자 요청 분포가 아니다.

넷째, 닫힌 RTL 경로는 논리 가상 시제품이다. GTH·MIG·CDC·패킷 프로토콜을 구현하고 Vivado 타이밍을 닫아야 물리 대역폭을 말할 수 있다. 다섯째, K26 로컬 대역폭과 전력은 민감도 입력이다. 실제 보드에서 같은 작업을 실행해 로컬 경합과 전체 전력을 측정해야 외부 메모리 채택을 결정할 수 있다.

후속 검증 순서는 명확하다. 먼저 실제 K26 로컬 대역폭· 경합·전력을 측정한다. 다음으로 논리 응답을 패킷 단위로 나누고 GTH·CDC·크레딧 경로를 구현한다. 그 뒤 MIG 타이밍과 한 채널의 정확한 핀·전원·배선을 닫고 SI/PI 검증을 진행한다. 이 관문을 통과하기 전에는 전체 보드를 제작 대상으로 취급하지 않는다.

XI. 결론

본 연구는 K26의 연산·제어와 외부 Memory FPGA의 가중치 공급을 분리한 온디바이스 sLLM 확장 후보를 설계하고, 실제 Gemma 형상에서 초기 배치와 작업 재분배의 조건을 평가했다. 합성 불균형 부하에서는 지역성 인식 작업 재분배가 TileJob p95와 비지역 가중치 이동을 함께 줄였다. 그러나 의존성과 이동 비용을 반영한 Gemma 형상에서는 배치에 따라 이득이 사라지거나 완료시간이 악화되었다.

따라서 작업 훔치기는 이 구조의 주인공이 아니라, 초기 배치 후 남은 불균형이 이동 비용보다 클 때만 켜는 수단이다. Gemma 1B는 K26 로컬을 우선하고, 외부 8GB는 더 큰 모델·긴 문맥·실제 로컬 경합이 확인될 때 채택한다. 실제 모델 그래프, 출력 TileJob, 폐루프 논리 RTL, 분석 결과, KiCad 쿠폰을 공개한 설계 흐름이 본 연구의 핵심 공학적 기여다.

코드와 자료 공개

SpinalHDL RTL, 실험 설정과 결과 CSV, Gemma 그래프 목록, 그림 원본, KiCad 원본, 논문과 발표자료는 다음 저장소에 공개한다.

Native KiCad 원본은 hardware/kicad/에 있으며 제작용 산출물이 아닌 참조 쿠폰이다.

Repository:
https://github.com/snowman0919/varp-k26-memory-fpga

Release: https://github.com/snowman0919/varp-k26-memory-fpga/releases/tag/v11-conference-final

모델 가중치는 라이선스와 용량 때문에 배포하지 않는다. 공개 압축 파일은 고정 해시의 그래프 목록과 제한된 타일 시험 입력만 포함한다.

참고문헌

[1] W. Kwon et al., “Efficient Memory Management for Large Language Model Serving with PagedAttention,” arXiv:2309.06180, 2023.
[2] T. Dao et al., “FlashAttention: Fast and Memory-
Efficient | Exact | Attention | with | IO-Awareness,”
arXiv:2205.14135, 2022.
[3] E. Frantar et al., “GPTQ: Accurate Post-Training Quantization for Generative Pre-trained Transformers,” arXiv:2210.17323, 2022.
[4] G. Xiao et al., “SmoothQuant: Accurate and Efficient Post-Training Quantization for LLMs,” arXiv:2211.10438, 2022.
[5] J. Lin et al., “AWQ: Activation-aware Weight Quantization for LLM Compression and Acceleration,” arXiv:2306.00978, 2023.
[6] B. Li et al., “FTRANS: Energy-Efficient Acceleration of Transformers using FPGA,” ISLPED, 2020.
[7] S. Hong et al., “DFX: A Low-latency Multi-FPGA Appliance for Accelerating Transformer-based Text Generation,” MICRO-55, 2022.
[8] S. Zeng et al., “FlightLLM: Efficient Large Language Model Inference with a Complete Mapping Flow on FPGAs,” arXiv:2401.03868, 2024.
[9] S. Li et al., “DRAMsim3: A Cycle-Accurate, Thermal-Capable DRAM Simulator,” IEEE Computer Architecture Letters, vol. 19, no. 2, 2020.
[10] AMD, Kria K26 SOM Data Sheet DS987.
[11] AMD, Kria SOM Carrier Card Design Guide UG1091.
[12] AMD, 7 Series FPGAs Packaging and Pinout UG475.
[13] AMD, 7 Series FPGAs Memory Interface Solutions UG586.
[14] KiCad Project, KiCad 9 Documentation, ERC and DRC reference.
[15] R. D. Blumofe and C. E. Leiserson, “Scheduling Multithreaded Computations by Work Stealing,” Journal of the ACM, vol. 46, no. 5, pp. 720–748, 1999.
[16] Q. Chen et al., “Locality-Aware Work Stealing Based on Online Profiling and Auto-Tuning for Multisocket Multicore Architectures,” HPDC, 2015.

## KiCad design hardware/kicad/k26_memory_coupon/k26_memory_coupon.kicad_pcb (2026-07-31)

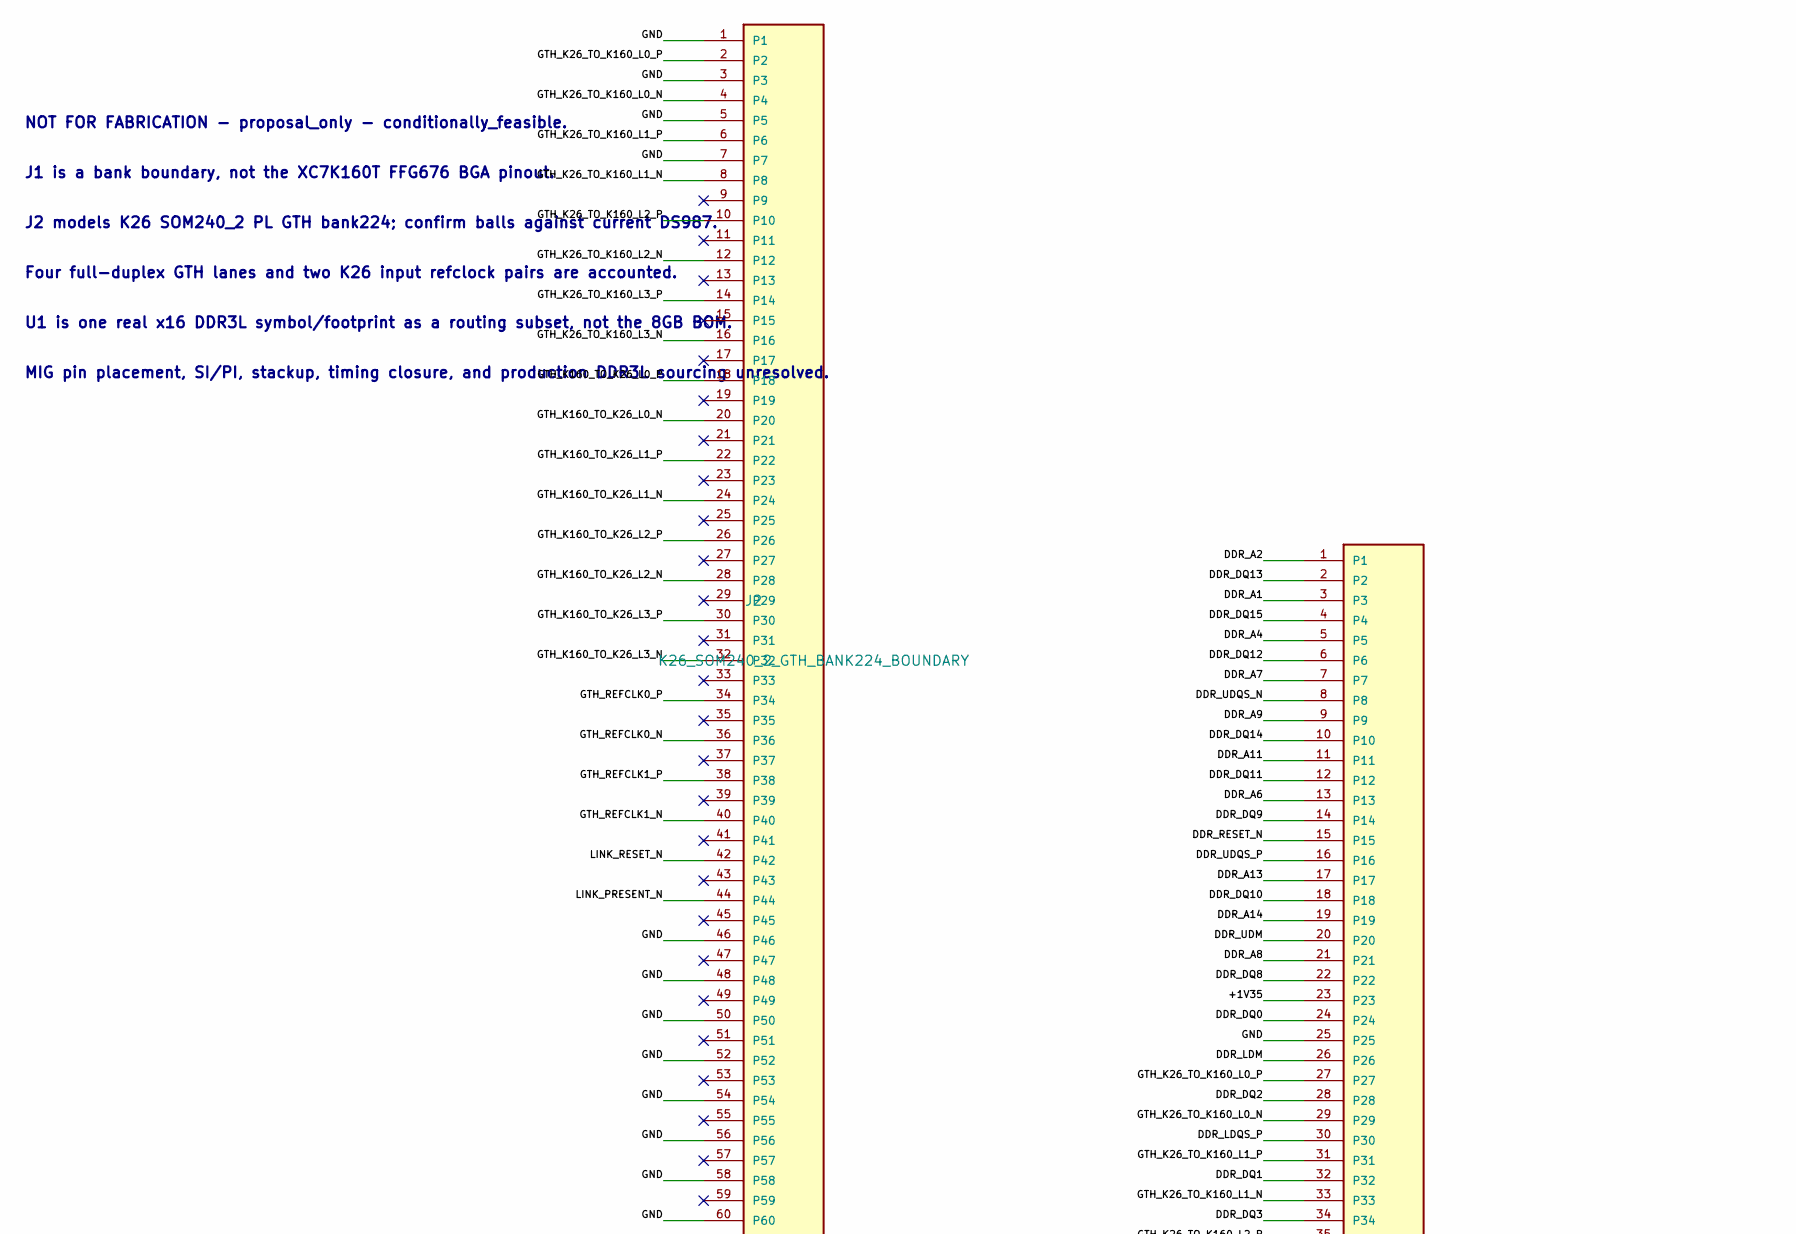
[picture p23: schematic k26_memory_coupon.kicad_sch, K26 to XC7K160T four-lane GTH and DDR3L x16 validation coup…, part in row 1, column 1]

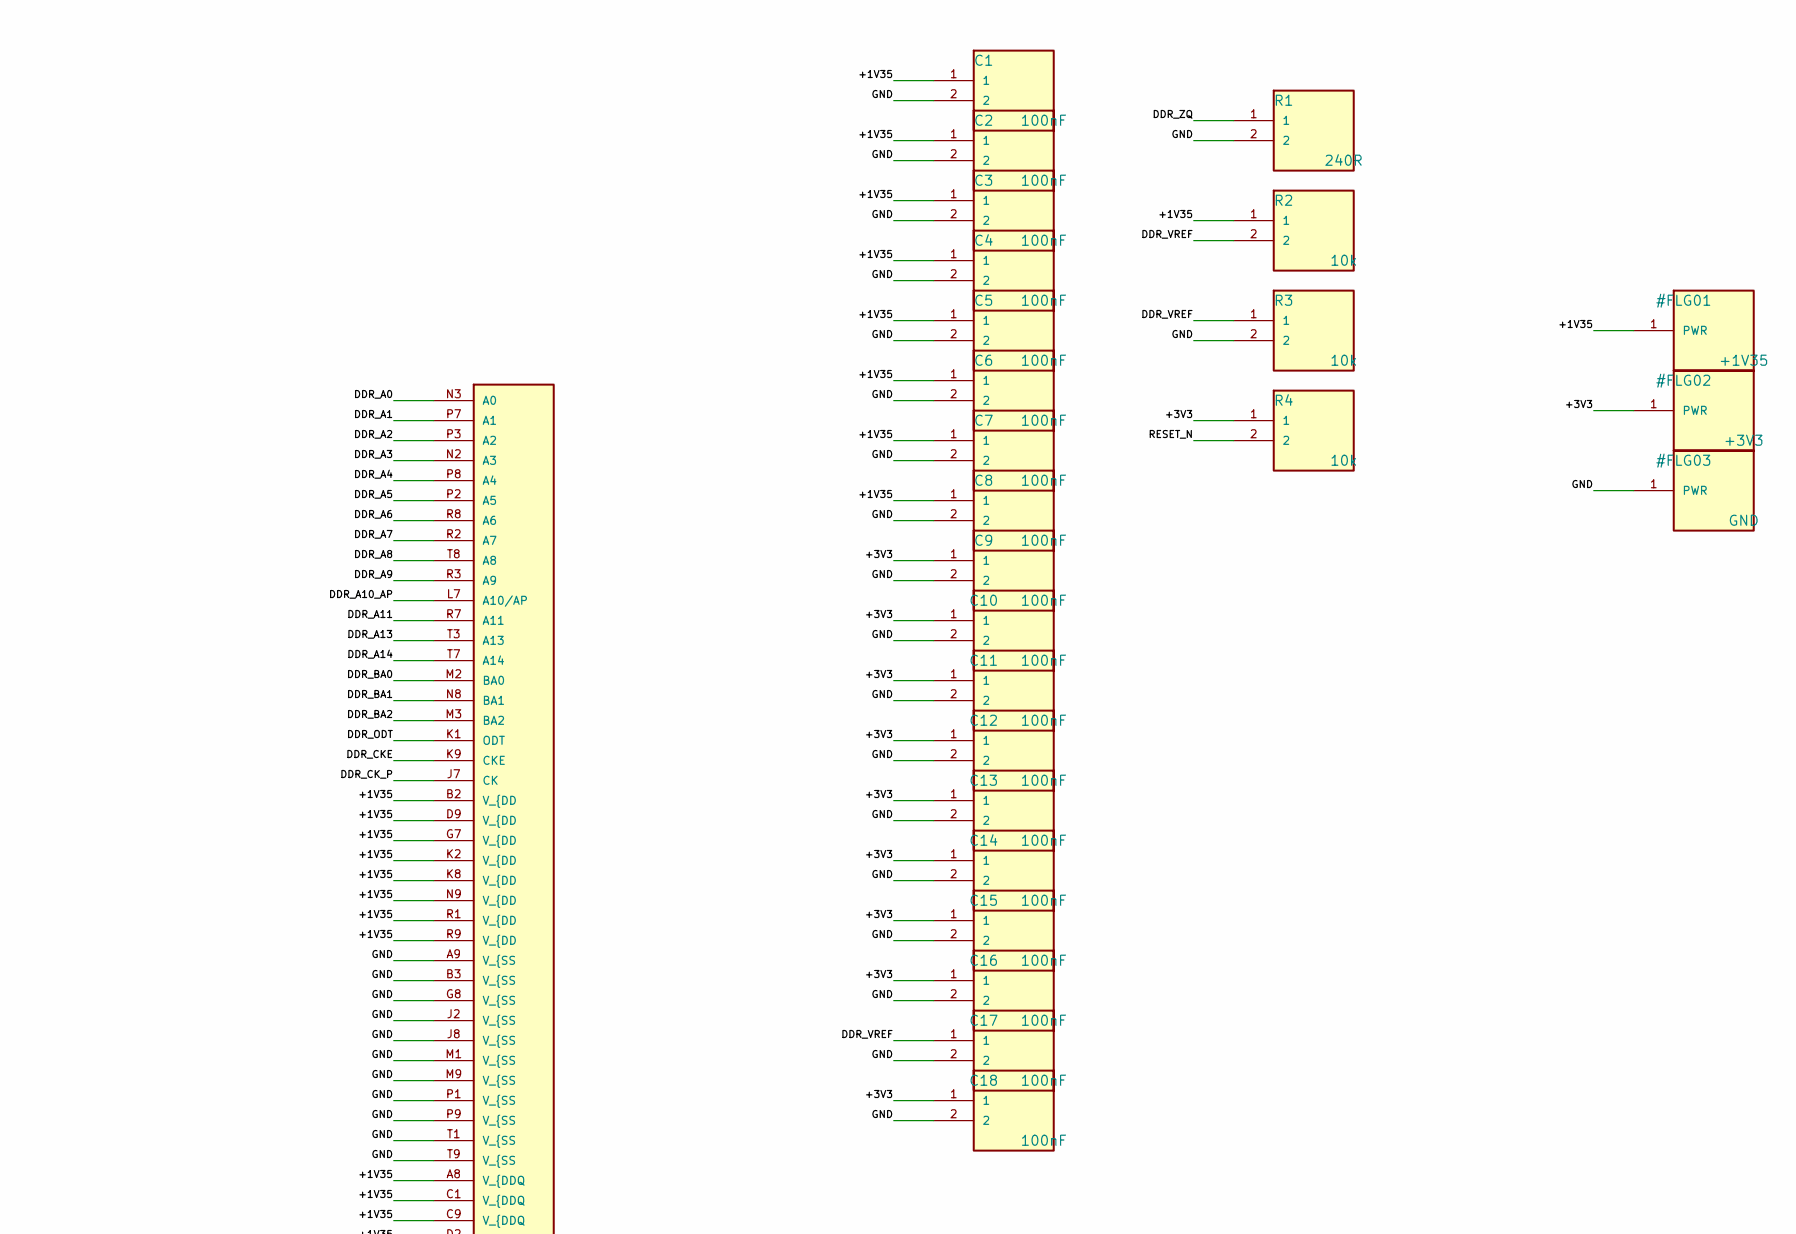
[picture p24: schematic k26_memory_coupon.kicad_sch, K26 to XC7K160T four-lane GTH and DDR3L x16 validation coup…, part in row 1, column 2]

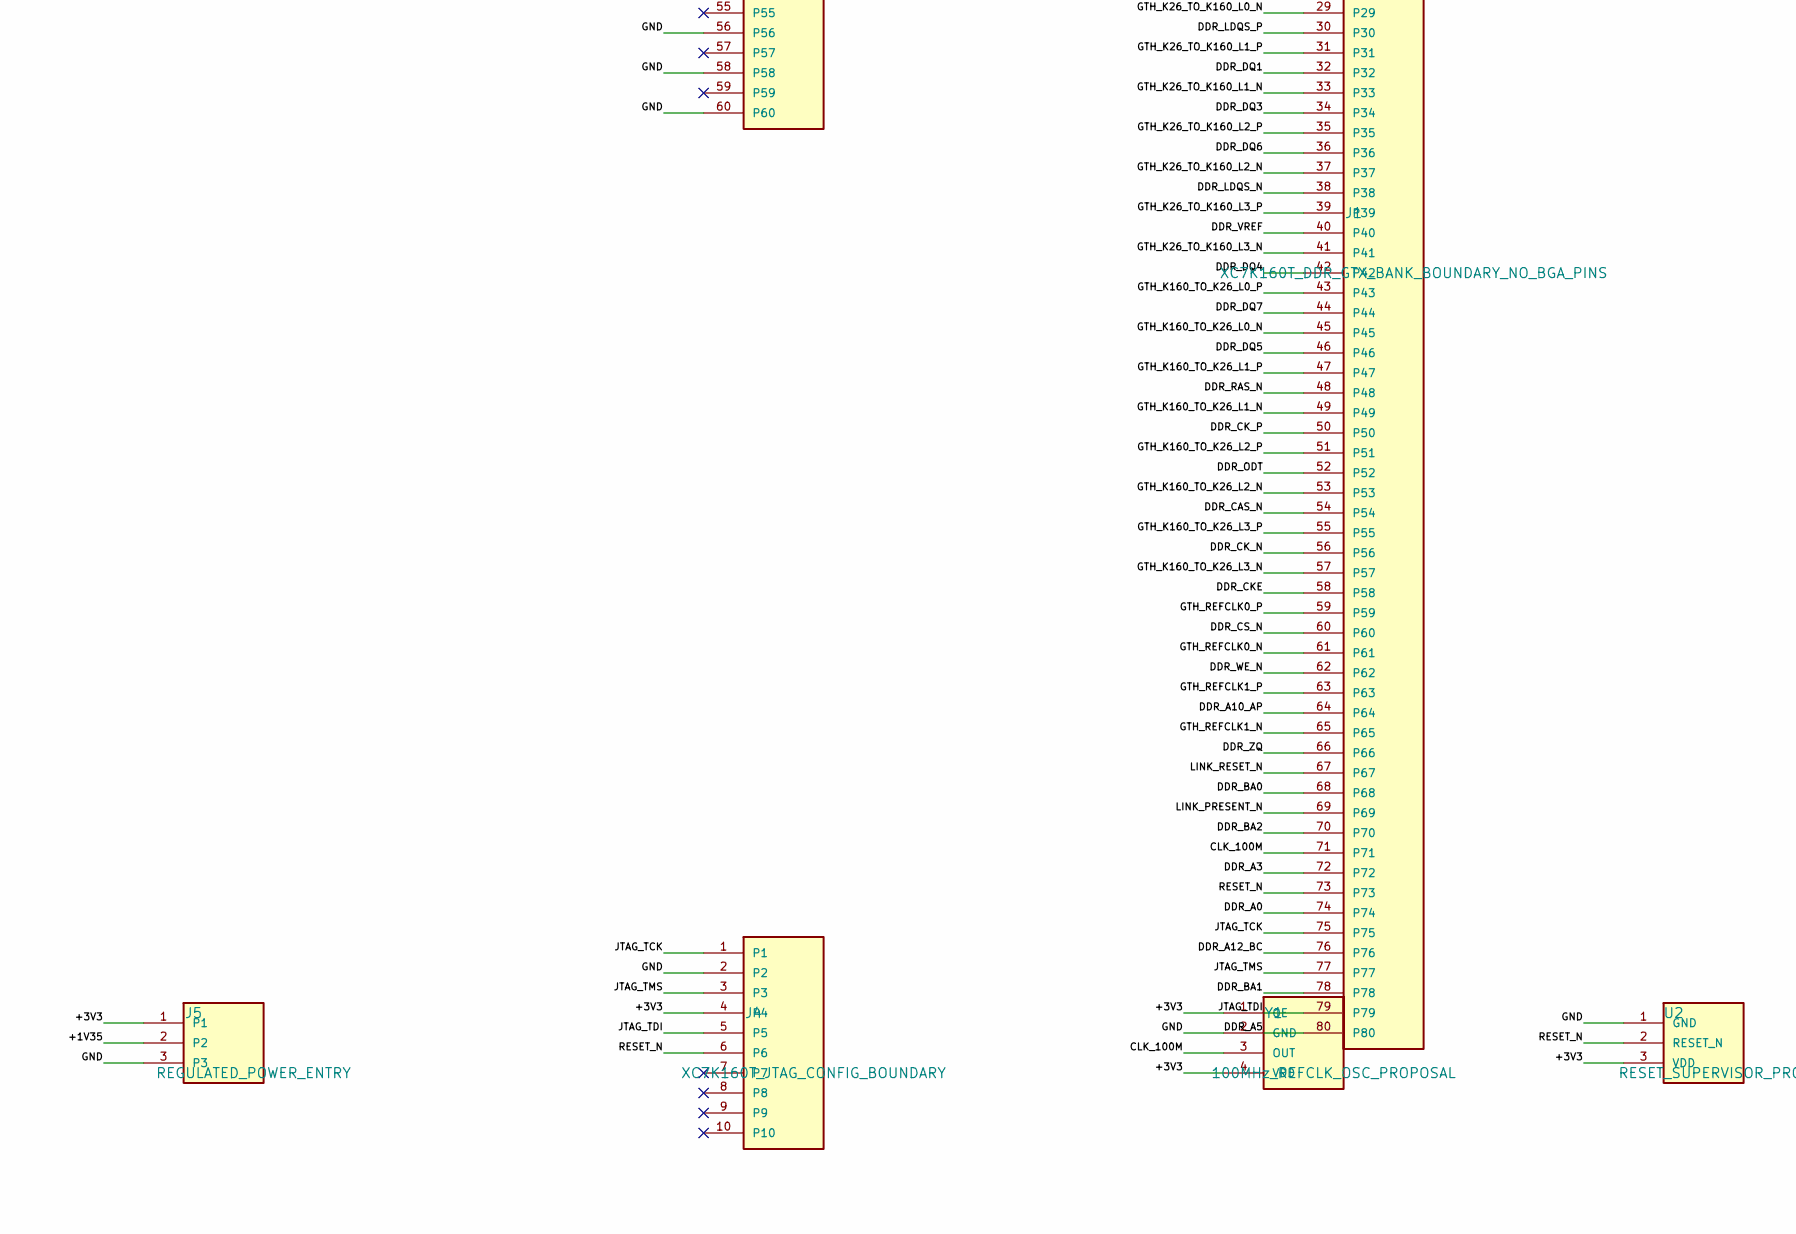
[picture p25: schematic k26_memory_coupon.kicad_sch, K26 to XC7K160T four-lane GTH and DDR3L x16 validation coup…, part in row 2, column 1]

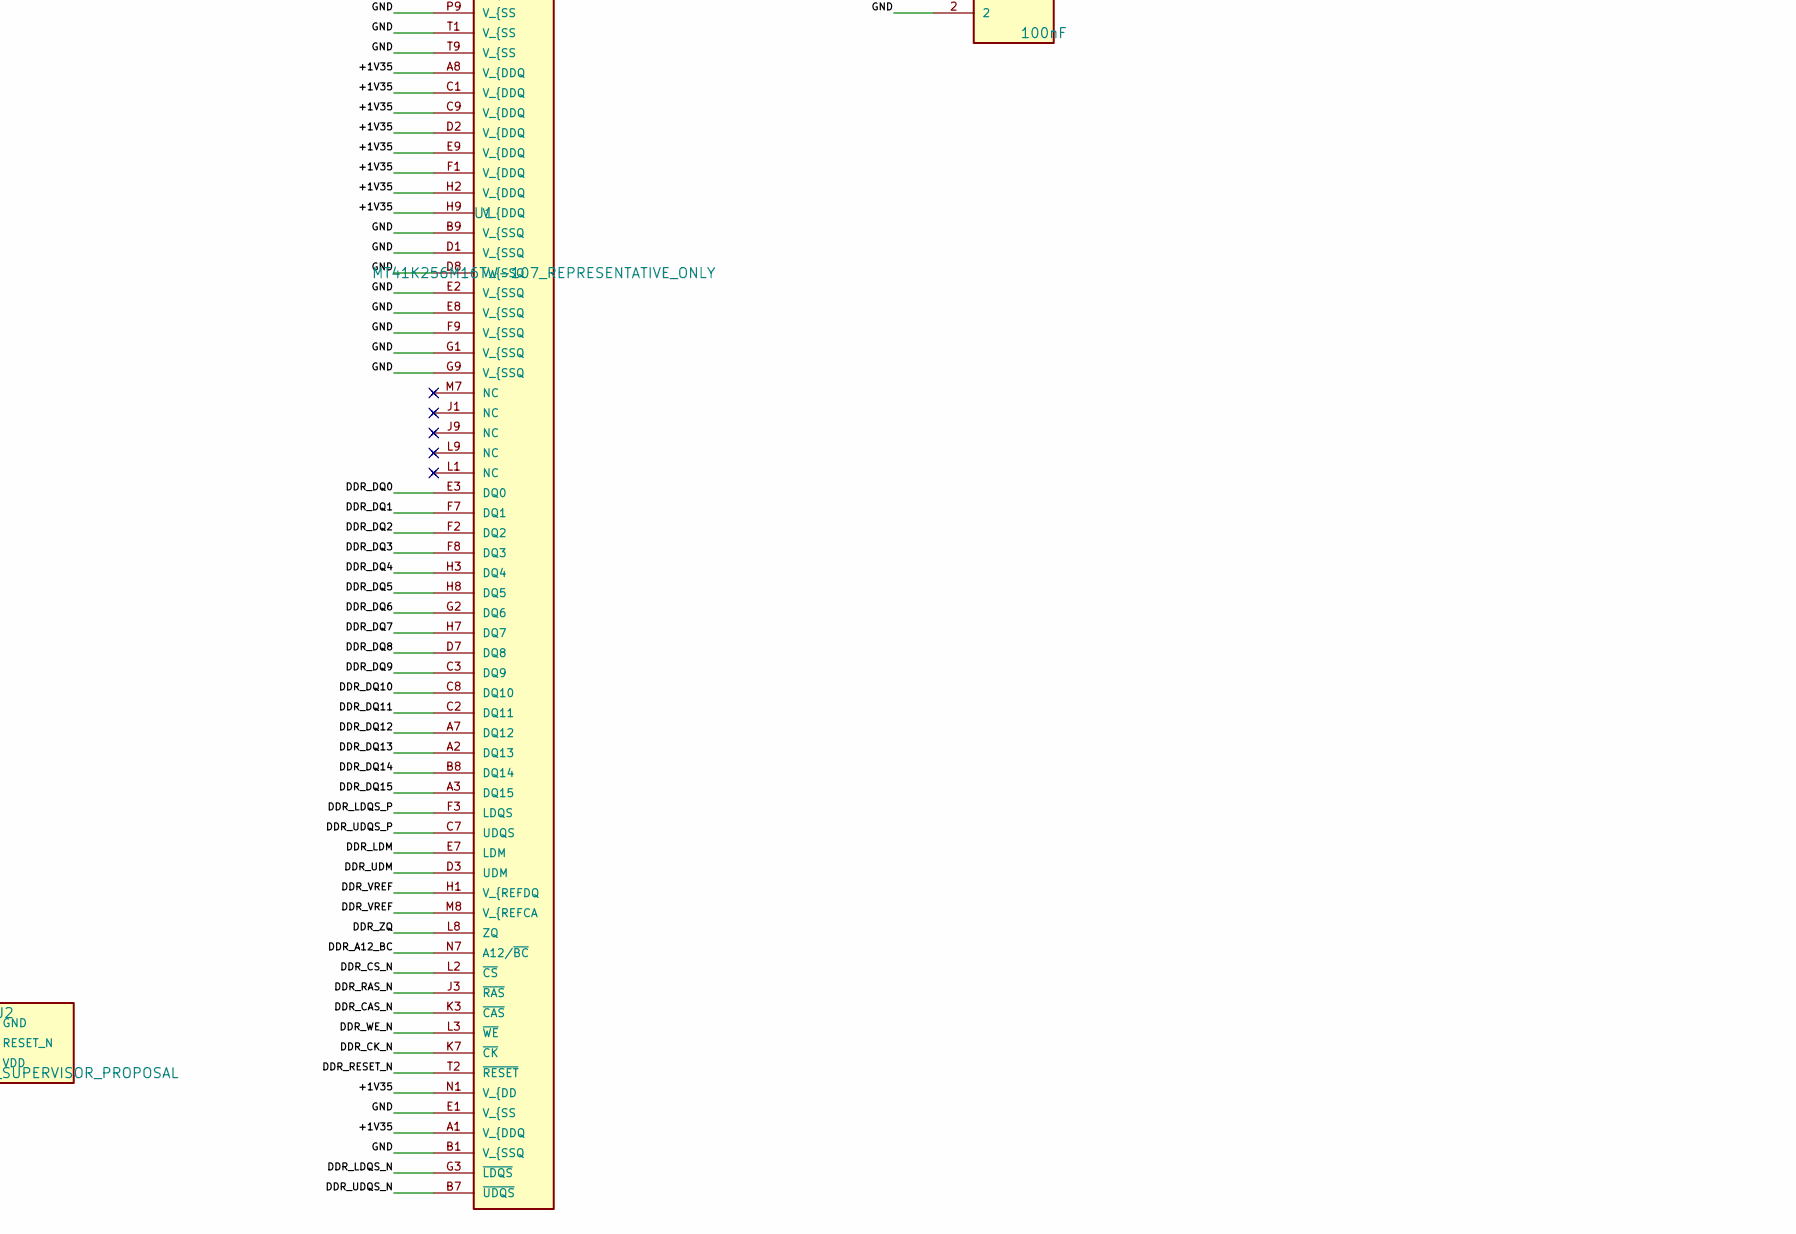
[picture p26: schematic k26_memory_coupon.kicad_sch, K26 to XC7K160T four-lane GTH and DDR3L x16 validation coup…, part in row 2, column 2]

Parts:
C1, C2, C3, C4, C5, C6, C7, C8, C9, C10, C11, C12, C13, C14, C15, C16, C17, C18: 100nF; C_0402_1005Metric
J1: XC7K160T_DDR_GTX_BANK_BOUNDARY_NO_BGA_PINS; Samtec_HSEC8-140-03-X-DV_2x40_P0.8mm_Pol22_Socket
J2: K26_SOM240_2_GTH_BANK224_BOUNDARY; Samtec_HSEC8-130-03-X-DV_2x30_P0.8mm_Socket
J4: XC7K160T_JTAG_CONFIG_BOUNDARY; PinHeader_2x05_P1.27mm_Vertical
J5: REGULATED_POWER_ENTRY; TerminalBlock_Phoenix_MKDS-1,5-3_1x03_P5.00mm_Horizontal
R1: 240R; R_0402_1005Metric
R2, R3, R4: 10k; R_0402_1005Metric
U1: MT41K256M16TW-107_REPRESENTATIVE_ONLY; Micron_FBGA-96_8x14mm_Layout9x16_P0.8mm; MPN MT41K256M16TW-107
U2: RESET_SUPERVISOR_PROPOSAL; SOT-23
Y1: 100MHz_REFCLK_OSC_PROPOSAL; Oscillator_SMD_ECS_2520MV-xxx-xx-4Pin_2.5x2.0mm

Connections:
/+1V35: C1.1, C2.1, C3.1, C4.1, C5.1, C6.1, C7.1, C8.1, J1.23, J5.2, R2.1, U1.A1 (V_{DDQ), U1.A8 (V_{DDQ), U1.B2 (V_{DD), U1.C1 (V_{DDQ), U1.C9 (V_{DDQ), U1.D2 (V_{DDQ), U1.D9 (V_{DD), U1.E9 (V_{DDQ), U1.F1 (V_{DDQ), U1.G7 (V_{DD), U1.H2 (V_{DDQ), U1.H9 (V_{DDQ), U1.K2 (V_{DD), U1.K8 (V_{DD), U1.N1 (V_{DD), U1.N9 (V_{DD), U1.R1 (V_{DD), U1.R9 (V_{DD)
/+3V3: C9.1, C10.1, C11.1, C12.1, C13.1, C14.1, C15.1, C16.1, C18.1, J4.4, J5.1, R4.1, U2.3 (VDD), Y1.1 (OE), Y1.4 (VDD)
/CLK_100M: J1.71, Y1.3 (OUT)
/DDR_A0: J1.74, U1.N3 (A0)
/DDR_A1: J1.3, U1.P7 (A1)
/DDR_A2: J1.1, U1.P3 (A2)
/DDR_A3: J1.72, U1.N2 (A3)
/DDR_A4: J1.5, U1.P8 (A4)
/DDR_A5: J1.80, U1.P2 (A5)
/DDR_A6: J1.13, U1.R8 (A6)
/DDR_A7: J1.7, U1.R2 (A7)
/DDR_A8: J1.21, U1.T8 (A8)
/DDR_A9: J1.9, U1.R3 (A9)
/DDR_A10_AP: J1.64, U1.L7 (A10/AP)
/DDR_A11: J1.11, U1.R7 (A11)
/DDR_A12_BC: J1.76, U1.N7 (A12/~BC)
/DDR_A13: J1.17, U1.T3 (A13)
/DDR_A14: J1.19, U1.T7 (A14)
/DDR_BA0: J1.68, U1.M2 (BA0)
/DDR_BA1: J1.78, U1.N8 (BA1)
/DDR_BA2: J1.70, U1.M3 (BA2)
/DDR_CAS_N: J1.54, U1.K3 (~CAS)
/DDR_CKE: J1.58, U1.K9 (CKE)
/DDR_CK_N: J1.56, U1.K7 (~CK)
/DDR_CK_P: J1.50, U1.J7 (CK)
/DDR_CS_N: J1.60, U1.L2 (~CS)
/DDR_DQ0: J1.24, U1.E3 (DQ0)
/DDR_DQ1: J1.32, U1.F7 (DQ1)
/DDR_DQ2: J1.28, U1.F2 (DQ2)
/DDR_DQ3: J1.34, U1.F8 (DQ3)
/DDR_DQ4: J1.42, U1.H3 (DQ4)
/DDR_DQ5: J1.46, U1.H8 (DQ5)
/DDR_DQ6: J1.36, U1.G2 (DQ6)
/DDR_DQ7: J1.44, U1.H7 (DQ7)
/DDR_DQ8: J1.22, U1.D7 (DQ8)
/DDR_DQ9: J1.14, U1.C3 (DQ9)
/DDR_DQ10: J1.18, U1.C8 (DQ10)
/DDR_DQ11: J1.12, U1.C2 (DQ11)
/DDR_DQ12: J1.6, U1.A7 (DQ12)
/DDR_DQ13: J1.2, U1.A2 (DQ13)
/DDR_DQ14: J1.10, U1.B8 (DQ14)
/DDR_DQ15: J1.4, U1.A3 (DQ15)
/DDR_LDM: J1.26, U1.E7 (LDM)
/DDR_LDQS_N: J1.38, U1.G3 (~LDQS)
/DDR_LDQS_P: J1.30, U1.F3 (LDQS)
/DDR_ODT: J1.52, U1.K1 (ODT)
/DDR_RAS_N: J1.48, U1.J3 (~RAS)
/DDR_RESET_N: J1.15, U1.T2 (~RESET)
/DDR_UDM: J1.20, U1.D3 (UDM)
/DDR_UDQS_N: J1.8, U1.B7 (~UDQS)
/DDR_UDQS_P: J1.16, U1.C7 (UDQS)
/DDR_VREF: C17.1, J1.40, R2.2, R3.1, U1.H1 (V_{REFDQ), U1.M8 (V_{REFCA)
/DDR_WE_N: J1.62, U1.L3 (~WE)
/DDR_ZQ: J1.66, R1.1, U1.L8 (ZQ)
/GND: C1.2, C2.2, C3.2, C4.2, C5.2, C6.2, C7.2, C8.2, C9.2, C10.2, C11.2, C12.2, C13.2, C14.2, C15.2, C16.2, C17.2, C18.2, J1.25, J2.1, J2.3, J2.5, J2.7, J2.46, J2.48, J2.50, J2.52, J2.54, J2.56, J2.58, J2.60, J4.2, J5.3, R1.2, R3.2, U1.A9 (V_{SS), U1.B1 (V_{SSQ), U1.B3 (V_{SS), U1.B9 (V_{SSQ), U1.D1 (V_{SSQ), U1.D8 (V_{SSQ), U1.E1 (V_{SS), U1.E2 (V_{SSQ), U1.E8 (V_{SSQ), U1.F9 (V_{SSQ), U1.G1 (V_{SSQ), U1.G8 (V_{SS), U1.G9 (V_{SSQ), U1.J2 (V_{SS), U1.J8 (V_{SS), U1.M1 (V_{SS), U1.M9 (V_{SS), U1.P1 (V_{SS), U1.P9 (V_{SS), U1.T1 (V_{SS), U1.T9 (V_{SS), U2.1 (GND), Y1.2 (GND)
/GTH_K26_TO_K160_L0_N: J1.29, J2.4
/GTH_K26_TO_K160_L0_P: J1.27, J2.2
/GTH_K26_TO_K160_L1_N: J1.33, J2.8
/GTH_K26_TO_K160_L1_P: J1.31, J2.6
/GTH_K26_TO_K160_L2_N: J1.37, J2.12
/GTH_K26_TO_K160_L2_P: J1.35, J2.10
/GTH_K26_TO_K160_L3_N: J1.41, J2.16
/GTH_K26_TO_K160_L3_P: J1.39, J2.14
/GTH_K160_TO_K26_L0_N: J1.45, J2.20
/GTH_K160_TO_K26_L0_P: J1.43, J2.18
/GTH_K160_TO_K26_L1_N: J1.49, J2.24
/GTH_K160_TO_K26_L1_P: J1.47, J2.22
/GTH_K160_TO_K26_L2_N: J1.53, J2.28
/GTH_K160_TO_K26_L2_P: J1.51, J2.26
/GTH_K160_TO_K26_L3_N: J1.57, J2.32
/GTH_K160_TO_K26_L3_P: J1.55, J2.30
/GTH_REFCLK0_N: J1.61, J2.36
/GTH_REFCLK0_P: J1.59, J2.34
/GTH_REFCLK1_N: J1.65, J2.40
/GTH_REFCLK1_P: J1.63, J2.38
/JTAG_TCK: J1.75, J4.1
/JTAG_TDI: J1.79, J4.5
/JTAG_TMS: J1.77, J4.3
/LINK_PRESENT_N: J1.69, J2.44
/LINK_RESET_N: J1.67, J2.42
/RESET_N: J1.73, J4.6, R4.2, U2.2 (RESET_N)

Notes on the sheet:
Four full-duplex GTH lanes and two K26 input refclock pairs are accounted.
J1 is a bank boundary, not the XC7K160T FFG676 BGA pinout.
J2 models K26 SOM240_2 PL GTH bank224; confirm balls against current DS987.
NOT FOR FABRICATION - proposal_only - conditionally_feasible.
U1 is one real x16 DDR3L symbol/footprint as a routing subset, not the 8GB BOM.
MIG pin placement, SI/PI, stackup, timing closure, and production DDR3L sourcing unresolved.

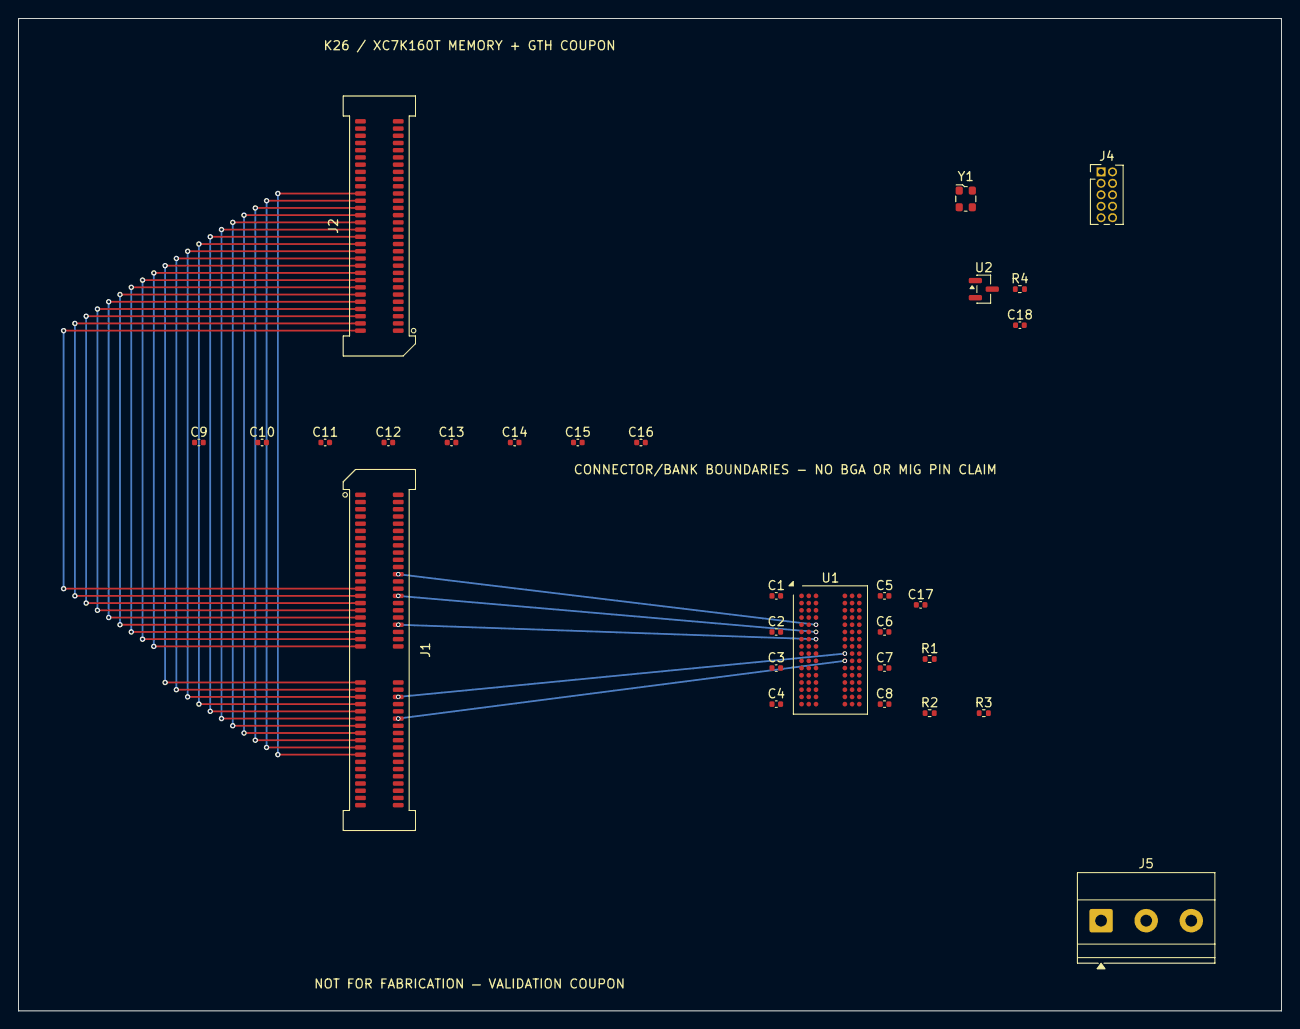
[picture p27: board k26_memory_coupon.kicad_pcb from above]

Board: 4 copper layers, 140.0 x 110.0 mm, 29 parts (0 on the bottom side), 81 nets.

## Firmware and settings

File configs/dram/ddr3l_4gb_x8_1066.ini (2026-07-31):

[dram_structure]
protocol = DDR3
bankgroups = 1
banks_per_group = 8
rows = 65536
columns = 1024
device_width = 8
BL = 8

[timing]
tCK = 1.875
AL = 0
CL = 8
CWL = 6
tRCD = 8
tRP = 8
tRAS = 20
tRFC = 139
tRFC2 = 139
tRFC4 = 139
REFI = 4160
tRPRE = 0
tWPRE = 0
tRRD_S = 4
tRRD_L = 4
tWTR_S = 4
tWTR_L = 4
tFAW = 20
tWR = 8
tWR2 = 8
tRTP = 4
tCCD_S = 4
tCCD_L = 4
tCKE = 3
tCKESR = 4
tXS = 145
tXP = 4
tRTRS = 1

[power]
VDD = 1.35
IDD0 = 44
IPP0 = 0.0
IDD2P = 18
IDD2N = 28
IDD3P = 32
IDD3N = 32
IDD4W = 95
IDD4R = 123
IDD5AB = 224
IDD6x = 20

[system]
channel_size = 8192
channels = 1
bus_width = 64
address_mapping = rochrababgco
queue_structure = PER_BANK
refresh_policy = RANK_LEVEL_STAGGERED
row_buf_policy = OPEN_PAGE
cmd_queue_size = 8
trans_queue_size = 32

[other]
epoch_period = 533333
output_level = 1

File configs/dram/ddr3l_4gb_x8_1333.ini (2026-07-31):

[dram_structure]
protocol = DDR3
bankgroups = 1
banks_per_group = 8
rows = 65536
columns = 1024
device_width = 8
BL = 8

[timing]
tCK = 1.5
AL = 0
CL = 10
CWL = 7
tRCD = 10
tRP = 10
tRAS = 24
tRFC = 174
tRFC2 = 174
tRFC4 = 174
REFI = 5200
tRPRE = 0
tWPRE = 0
tRRD_S = 4
tRRD_L = 4
tWTR_S = 5
tWTR_L = 5
tFAW = 20
tWR = 10
tWR2 = 10
tRTP = 5
tCCD_S = 4
tCCD_L = 4
tCKE = 4
tCKESR = 5
tXS = 181
tXP = 4
tRTRS = 1

[power]
VDD = 1.35
IDD0 = 47
IPP0 = 0.0
IDD2P = 18
IDD2N = 29
IDD3P = 35
IDD3N = 35
IDD4W = 110
IDD4R = 140
IDD5AB = 228
IDD6x = 20

[system]
channel_size = 8192
channels = 1
bus_width = 64
address_mapping = rochrababgco
queue_structure = PER_BANK
refresh_policy = RANK_LEVEL_STAGGERED
row_buf_policy = OPEN_PAGE
cmd_queue_size = 8
trans_queue_size = 32

[other]
epoch_period = 666666
output_level = 1

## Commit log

2026-07-31 Initial public research artifact
    [01_K26_SOM_GTH_Boundary.kicad_sch, 02_XC7K160T_Bank_Boundary.kicad_sch, 03_DDR3L_Four_Channel_Topology.kicad_sch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]
2026-07-31 feat: add CSV-backed conference presentation figures
    [bottleneck_shift_source.csv, s1_s3_timeline_events.csv]
2026-07-31 finalize v11 conference research package
    [bottleneck_shift_source.csv, claim_audit.csv, events_dependency_decode1_source_rule_S1.csv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]
